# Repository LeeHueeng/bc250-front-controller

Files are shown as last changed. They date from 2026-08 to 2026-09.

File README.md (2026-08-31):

# BC250 Front Controller

**Turn your AMD BC-250 into a real PC** — smart power button, graceful shutdown, temperature-driven fan curve, OLED status display, and Home Assistant integration, all running standalone on a single ESP32-S3.

[🇰🇷 한국어 README](README.ko.md)






> ⚠️ **Status: work in progress.** Firmware boots and is verified on a bare board; full hardware validation (relay + sensors + fan on a live BC-250) is ongoing. Follow the repo for updates.

## Why?

The AMD BC-250 is a PS5-APU board that sells for roughly $100–150 these days — but it was born in a mining rack, so as a desktop it's missing everything:

- ❌ **No power button** and no ACPI — power on = PSU on
- ❌ **No graceful shutdown** — cutting power is the only "off"
- ❌ **No usable fan control** outside the original rack chassis
- ❌ **No status indication** whatsoever

This project fixes all of that with an ESP32-S3 sitting between your ATX PSU and the board — like the front panel the BC-250 never had.

## Features

- 🔌 **Real power button** — short press to power on / gracefully shut down, 5-second hold to force off
- 🛡️ **Fail-safe relay design** — the ATX `PS_ON` line is held through the relay's **NC contact**, so if the ESP32 crashes, reboots or updates, **your server stays up**
- 🧠 **Fully autonomous** — the graceful-shutdown sequence (HTTP request to the OS → wait → cut power), fan curve, OLED and button all run on the ESP32 itself. No Home Assistant, no cloud, no Wi-Fi required
- 🌡️ **Temperature-driven fan curve** — two DS18B20 probes (GPU heatsink + case), 25 kHz PWM, tach feedback with fan-failure detection
- 🖥️ **OLED status display** — power state, temperatures, fan RPM, network info on an SSD1306
- 🎛️ **On-device settings menu** — two extra buttons + the OLED give you a local menu: fan mode/preset, manual speed, display brightness, overheat threshold, shutdown timeout — all saved to flash, no phone or PC needed
- 🚨 **WS2812 status LED** — off / green (running) / yellow (shutting down) / red (fan failure, overheat)
- 🌐 **Built-in web dashboard** — control everything from a browser, straight from the ESP32
- 🏠 **Home Assistant auto-discovery** — appears natively via the ESPHome integration (optional MQTT)
- 📶 **Zero-config Wi-Fi provisioning** — first boot opens a `bc250-front-setup` AP with a captive portal; no credentials are baked into the firmware
- 🔄 **OTA updates** — flash over USB once, update over the air forever
- 📴 **Network-loss hardened** — never reboots on Wi-Fi/API loss; local control keeps working, the setup AP reopens automatically

## How it works

The BC-250 only uses the PCIe 8-pin — the ATX 24-pin connector is completely unused. So we steal three wires from it:

| ATX wire | Purpose |
|---|---|
| 🟣 Purple (pin 9, `5VSB`) | Always-on 5 V → powers the ESP32 + relay even when the PSU is "off" |
| 🟢 Green (pin 16, `PS_ON`) | Grounding this turns the PSU on — held via the relay **NC** contact |
| ⚪ Gray (pin 8, `PWR_OK`) | Tells the ESP32 whether the PSU is actually up (10k+10k divider) |

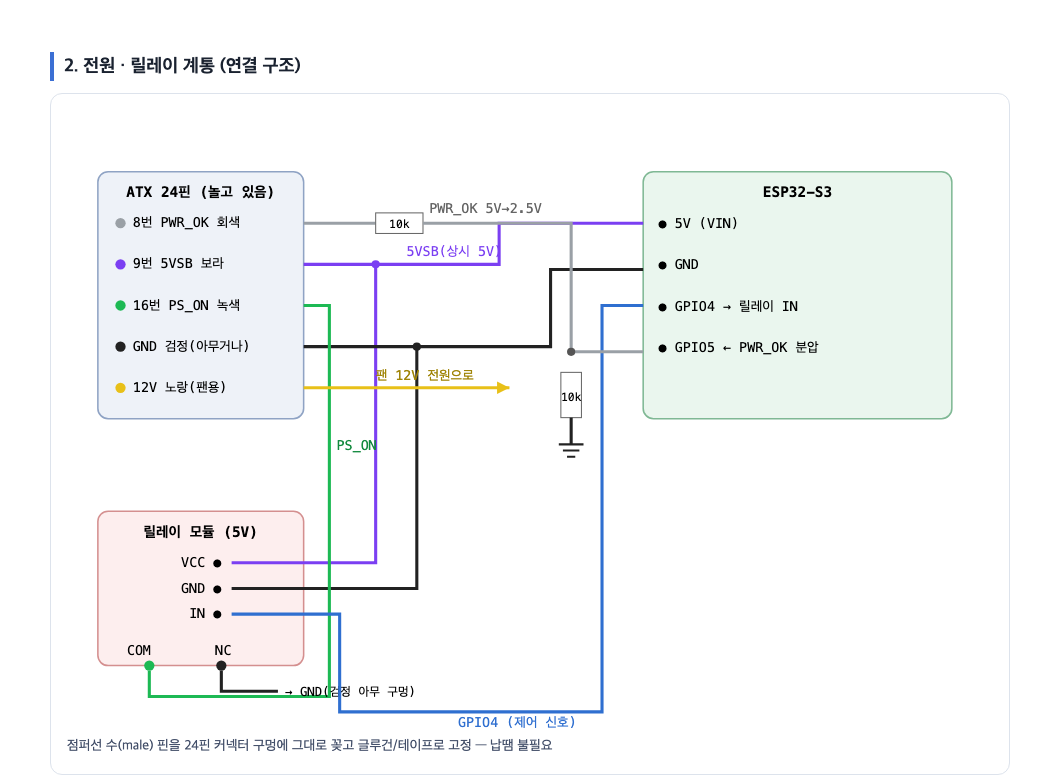
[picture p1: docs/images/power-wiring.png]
Power & relay wiring


Graceful shutdown, with the **ESP32 as the source of truth** (no home-automation dependency):

```
button / web / HA  →  ESP32  →  HTTP shutdown request to the OS
                              →  wait 60 s for the OS to halt
                              →  release PS_ON (power off)
```

## Build tiers — everything is optional except the relay

Missing parts don't break anything: an absent OLED, sensor, fan or button simply disables that one feature. Start minimal, add parts whenever you feel like it.

| Tier | Hardware | You get | Firmware |
|---|---|---|---|
| **Minimal** | ESP32 + relay + 3 jumper wires | Web/HA power on-off, graceful shutdown, status LED (onboard) | [`bc250-front-minimal.yaml`](bc250-front-minimal.yaml) |
| **+ Button** | + push button | Physical front-panel power button | same |
| **Full** | + OLED, 2× DS18B20, PWM fan, 2 menu buttons, PWR_OK divider | Fan curve, temperatures, display, on-device settings menu, PSU state | [`bc250-front.yaml`](bc250-front.yaml) |
| **Full + color LCD** | Full, but OLED → **ST7789V 2.4" 240×320 SPI** | All of the above + large color UI, status icons, backlight dimming | [`bc250-front-st7789.yaml`](bc250-front-st7789.yaml) |

## Hardware

| Part | Qty | ~Cost |
|---|---|---|
| ESP32-S3 dev board (2×22 pins) | 1 | $5 |
| 5 V 1-channel relay module (optocoupler) | 1 | $1 |
| SSD1306 0.96" OLED (I2C) | 1 | $2 |
| DS18B20 temperature sensor | 2 | $2 |
| Momentary push button (power + 2 menu) | 3 | $1 |
| Resistors: 2× 10 kΩ, 1× 4.7 kΩ | — | $0.1 |
| Dupont jumper wires | — | $1 |

**No soldering required** — male jumper pins fit straight into the unused ATX 24-pin connector holes.

## PCB — three options (optional)

| | [**DIY carrier board**](hardware/bc250-front-carrier/README.md) | [**Semi-assembled PCBA**](hardware/bc250-front-pcba/README.md) | [**DevKit mini**](hardware/bc250-front-mini/README.md) |
|---|---|---|---|
| How | bare board, hand-solder the parts, plug in an ESP32-S3-DevKitC-1 | JLCPCB Economic assembly — you solder only the ESP32-S3 WROOM module, the display socket and (optionally) the LED | **66×50 mm**, smallest — DevKit on sockets, parts under it, LCD wired to a pin header |
| Power switch | relay | MOSFET (silent) | MOSFET (silent) |
| Sensors | DS18B20 | DS18B20 **or** 10 kΩ NTC | DS18B20 |
| Cost (5 boards) | ≈ $2 boards + ≈ $8 parts each | JLCPCB ≈ $45 + ≈ $4 module each → ≈ $13 each | ≈ $2 boards (≈ $12 with SMD assembly) + a DevKit |
| Firmware | `relay_inverted: "false"` | defaults + `log_uart: USB_SERIAL_JTAG` | defaults (`relay_inverted: "true"`) |

All three take the PSU's ATX 24-pin plug directly and use the pin map above.

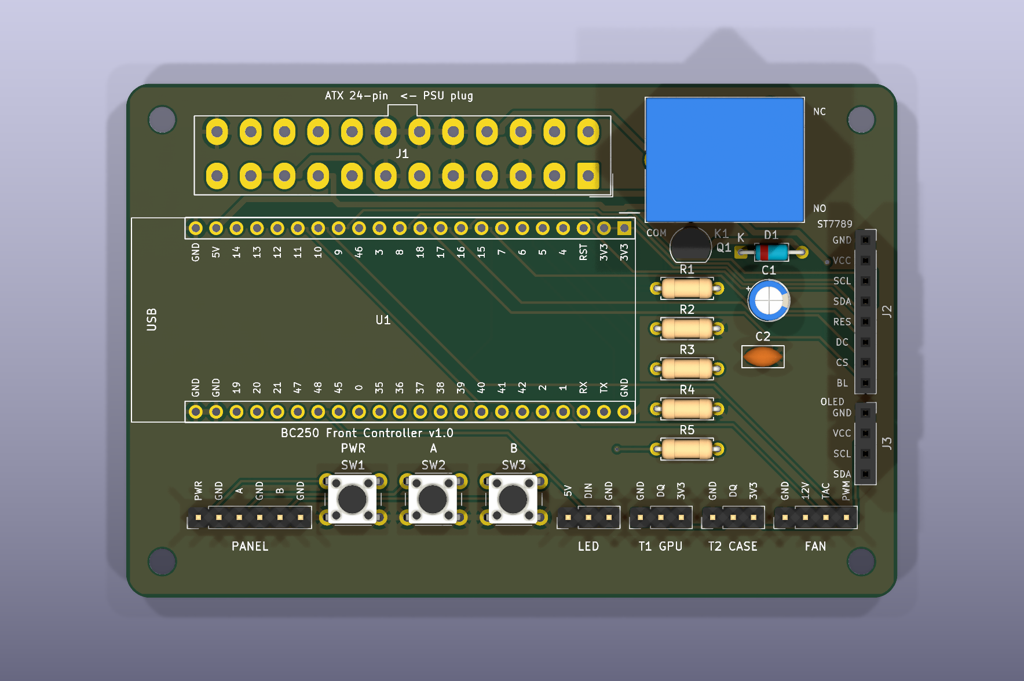
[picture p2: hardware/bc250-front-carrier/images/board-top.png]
carrier board

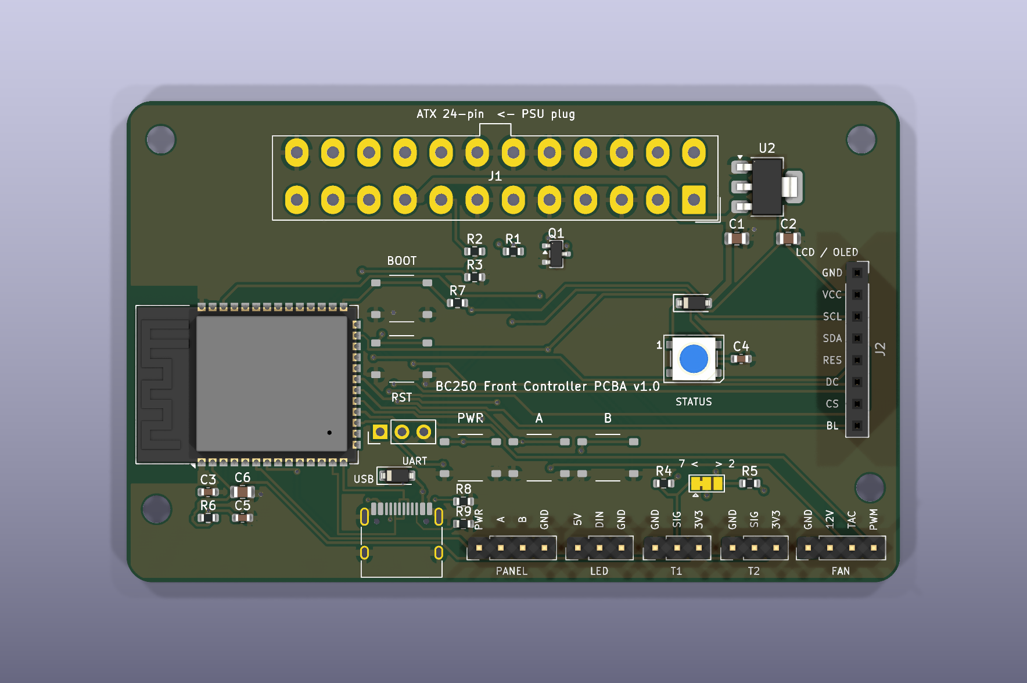
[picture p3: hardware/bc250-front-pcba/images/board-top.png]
PCBA

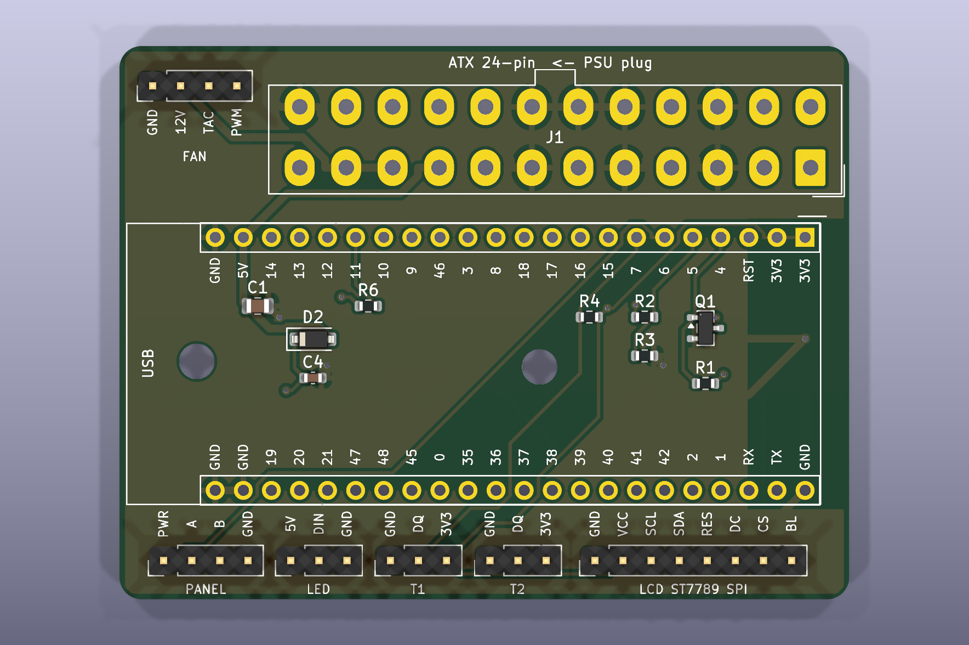
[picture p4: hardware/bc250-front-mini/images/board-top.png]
DevKit mini


## Wiring

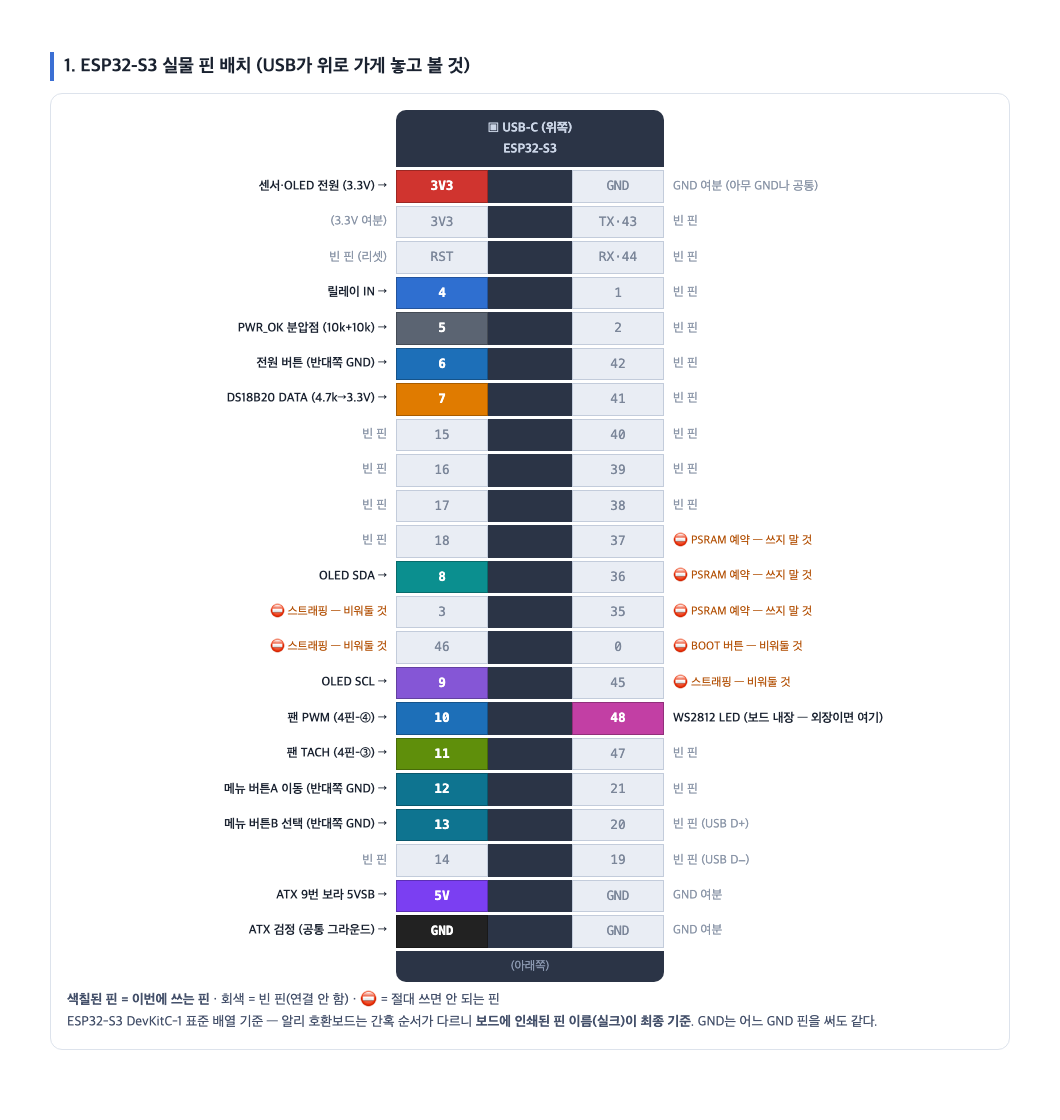
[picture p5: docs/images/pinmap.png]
ESP32-S3 pin map


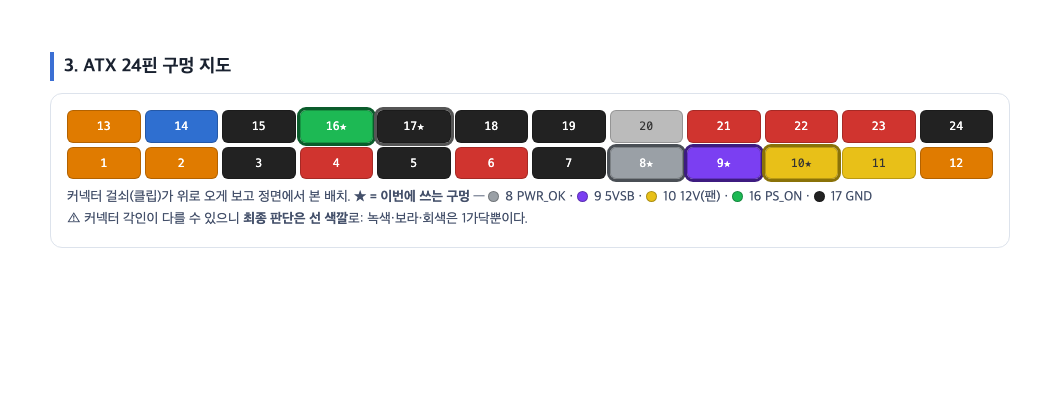
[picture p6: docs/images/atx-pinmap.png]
ATX 24-pin holes


| ESP32-S3 pin | Connects to |
|---|---|
| `5V` | ATX pin 9 — purple `5VSB` |
| `GND` | ATX black (common ground) |
| `3V3` | OLED VCC, DS18B20 VDD, pull-ups |
| `GPIO4` | Relay IN |
| `GPIO5` | ATX pin 8 — gray `PWR_OK` (**via 10k+10k divider**) |
| `GPIO6` | Power button (other leg → GND) |
| `GPIO7` | DS18B20 data ×2, 4.7 kΩ pull-up to 3.3 V |
| `GPIO8` / `GPIO9` | OLED SDA / SCL |
| `GPIO10` | Fan PWM (4-pin fan, pin 4) |
| `GPIO11` | Fan tach (4-pin fan, pin 3) |
| `GPIO12` / `GPIO13` | Menu buttons A (navigate) / B (select) — other leg → GND |
| `GPIO48` | WS2812 (onboard on most devkits) |

Relay contacts: **COM ↔ ATX pin 16 (green `PS_ON`)**, **NC ↔ GND**, NO unused.

Full interactive wiring guide (Korean): [`docs/wiring-guide.html`](docs/wiring-guide.html) (OLED) · [`docs/wiring-guide-st7789.html`](docs/wiring-guide-st7789.html) (ST7789V)

## Flashing

```bash
pip install esphome
esphome run bc250-front.yaml   # first time over USB, afterwards OTA
```

First boot: join the **`bc250-front-setup`** Wi-Fi AP from your phone → the captive portal opens → pick your network, enter the password. Done. Home Assistant will auto-discover the device within minutes.

> **Board note:** on CH343-based devkits the logger must use `hardware_uart: UART0` (already set in the YAML) — the default USB-JTAG console is not routed to the USB port on those boards.

## Roadmap

- [ ] OS-side shutdown agent (tiny systemd unit) + install script
- [ ] INA226 power monitoring (watts on the OLED!)
- [ ] Web-editable fan curve
- [ ] 3D-printable front-panel enclosure
- [ ] Buzzer alerts / event log

PRs and issues welcome — especially test reports from different BC-250 setups.

## Credits

- [mothenjoyer69/bc250-documentation](https://github.com/mothenjoyer69/bc250-documentation) — the definitive BC-250 hardware reference
- [elektricM/amd-bc250-docs](https://github.com/elektricM/amd-bc250-docs) — power & cooling documentation
- Built with [ESPHome](https://esphome.io)

## License

[MIT](LICENSE)

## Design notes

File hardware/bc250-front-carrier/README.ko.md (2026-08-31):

# BC250 Front Controller — 캐리어 PCB v1.0

ESP32-S3 DevKitC-1을 꽂는 캐리어 보드입니다. **PSU의 ATX 24핀 플러그가 보드에 그대로 꽂히므로** 점퍼선·글루건 없이 5VSB / PS_ON / PWR_OK / 12V / GND가 전부 자동으로 연결됩니다. 부품은 전부 관통형(THT)이라 인두기 하나면 조립할 수 있습니다.

[🇺🇸 English](README.md)

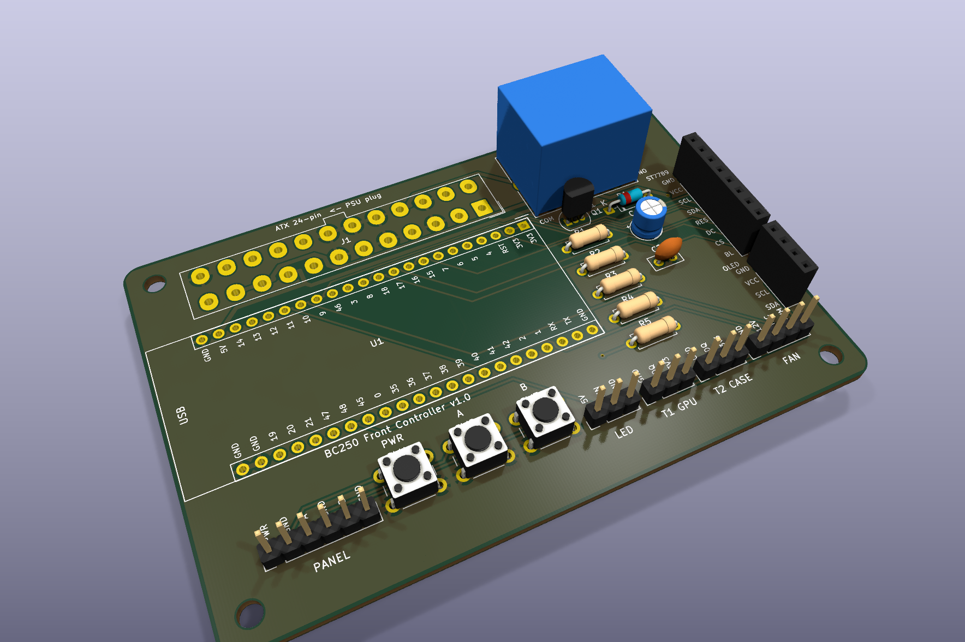
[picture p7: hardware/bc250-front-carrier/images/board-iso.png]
보드 렌더링


| | |
|---|---|
| 크기 | 96 × 64 mm, 2층, 1.6 mm, M3 홀 4개 (간격 87 × 55 mm) |
| MCU | ESP32-S3-DevKitC-1 (2×22핀) → 암소켓 2개에 꽂음 |
| 전원 | ATX 24핀 헤더 (Molex Mini-Fit Jr 5566-24A) 온보드 |
| 릴레이 | SRD-05VDC-SL-C + S8050 NPN 드라이버 온보드 — 기존과 같은 **NC fail-safe** 배선 |
| 디스플레이 | ST7789 2.4″ SPI 8핀 소켓 **과** SSD1306 OLED 4핀 소켓 (둘 중 하나만 꽂으면 됨) |
| 기타 커넥터 | 4핀 PWM 팬, DS18B20 ×2, 외장 WS2812, 전면패널 버튼 6핀 + 온보드 택트 3개 |
| 검증 | KiCad 10 ERC / DRC / 회로도-PCB 정합성 **모두 0건** (실물 검증은 아직 — 아래 첫 전원 절차 참고) |

## 파일

| 파일 | 용도 |
|---|---|
| [`gerbers/bc250-front-carrier-v1.0-gerbers.zip`](gerbers/bc250-front-carrier-v1.0-gerbers.zip) | **JLCPCB에 올리는 파일** (거버 + Excellon 드릴 + 잡파일) |
| `bc250-front-carrier.kicad_pro` / `.kicad_sch` / `.kicad_pcb` | KiCad 10 프로젝트 (풋프린트·심볼 라이브러리 동봉, 다른 PC에서도 바로 열림) |
| [`bc250-front-carrier-schematic.pdf`](bc250-front-carrier-schematic.pdf) | 회로도 |
| [`bom.csv`](bom.csv) | 부품표 |
| `bc250-front-carrier-pos.csv` | 부품 좌표 (조립 참고용) |
| `images/` | 앞·뒤·입체 렌더링, 레이아웃 SVG, 회로도 SVG |
| [`../tools/`](../tools/) | 보드 전체를 스크립트로 재생성 (`build.sh`) |

## JLCPCB 주문

1. [jlcpcb.com](https://jlcpcb.com) → **Order now** → *Add gerber file* → `gerbers/bc250-front-carrier-v1.0-gerbers.zip` 업로드
2. 96 × 64 mm, 2 layers로 자동 인식됩니다. 옵션은 **기본값 그대로** 두면 됩니다: FR-4, 1.6 mm, 1 oz, HASL, 수량 5장 (색은 취향, Remove Order Number는 No).
3. SMT 조립 서비스는 필요 없습니다 — 전부 직접 납땜합니다.
4. 5장에 보드값 약 $2 + 배송비 수준입니다.

## 부품표 (BOM)

| 참조 | 수량 | 부품 | 비고 |
|---|---|---|---|
| U1 | 1 | ESP32-S3-DevKitC-1 (N8R2 / N16R8 무관) | 수핀 헤더가 납땜된 것 |
| U1 소켓 | 2 | 1×22 암 핀소켓 2.54 mm | DevKit을 꽂은 채로 납땜하면 정렬이 쉬움 |
| J1 | 1 | ATX 24핀 보드용 커넥터 (Molex 5566-24A / 39-28-1243 호환, 4.2 mm 2×12 수직) | 국내: 디바이스마트·엘레파츠 "ATX 24핀 커넥터 보드용" |
| K1 | 1 | SRD-05VDC-SL-C 릴레이 (Songle / Sanyou SRD) | |
| Q1 | 1 | S8050 NPN (2N2222A·BC337도 가능) | TO-92, E-B-C |
| D1 | 1 | 1N4148 | 띠(캐소드)를 실크 **K** 쪽으로 |
| R1 | 1 | 1 kΩ | |
| R2, R3, R4 | 3 | 10 kΩ | |
| R5 | 1 | 4.7 kΩ | |
| C1 | 1 | 100 µF 16 V 전해 (5 mm) | 긴 다리(+)를 실크 **+** 쪽으로 |
| C2 | 1 | 100 nF 세라믹 | |
| J2 | 1 | 1×8 암 핀소켓 | ST7789 LCD 모듈이 그대로 꽂힘 |
| J3 | 1 | 1×4 암 핀소켓 | SSD1306 OLED 모듈이 그대로 꽂힘 |
| J4 | 1 | 1×4 수 핀헤더 | 4핀 팬 (진짜 팬 헤더도 꽂힘) |
| J5, J6, J7 | 3 | 1×3 수 핀헤더 | DS18B20 ×2, WS2812 |
| J8 | 1 | 1×6 수 핀헤더 | 전면 패널 버튼 (선택) |
| SW1–SW3 | 3 | 6×6 mm 택트 스위치 | 온보드 PWR / A / B |
| H1–H4 | 4 | M3 서포트 | 선택 |

## 조립 순서

1. **낮은 부품부터**: R1–R5 → D1 (띠를 `K` 쪽) → Q1 (평평한 면을 실크 모양과 맞춤) → C2 → C1 (`+` 확인)
2. **소켓·헤더**: J2·J3 암소켓, J4–J8 핀헤더, SW1–SW3, U1용 1×22 암소켓 ×2
3. **큰 부품**: K1 릴레이, J1 ATX 헤더 — 래치 홈이 있는 면이 보드 위쪽 가장자리(`ATX 24-pin ← PSU plug` 글자 쪽)를 향하게

## ⚠️ 첫 전원 인가 — ESP32를 꽂기 **전에**

ATX 헤더의 핀 번호는 KiCad 표준 Molex 5566-24A 풋프린트를 따랐지만, 실물로 검증된 보드는 아직 없습니다. 1분이면 확인됩니다.

1. DevKit **없이** PSU 24핀만 꽂고 PSU를 켭니다. 릴레이가 쉬는 상태(NC)라 **PSU가 바로 켜지는 게 정상**입니다 (ESP32가 죽어도 서버는 켜져 있다는 그 fail-safe).
2. 멀티미터로 확인 (보드 뒷면 실크에도 적혀 있음):
   - U1 소켓 윗줄 `5V` 핀 ↔ `GND` = **약 5 V**
   - `FAN` 헤더 `12V` 핀 ↔ `GND` = **12 V**
   - `5V` 자리에 0 V나 12 V가 나오면 J1 방향·납땜을 확인하고 **진행을 멈추세요.**
3. PSU를 끄고 DevKit 장착: USB 커넥터가 보드 **왼쪽 가장자리**(`USB` 실크), 안테나가 릴레이 쪽.

## 펌웨어

- yaml의 `substitutions:`에서 **`relay_inverted: "false"`** 로 바꿉니다 (이 보드는 NPN 직결 active-high; 시판 릴레이 모듈은 `"true"`).
- 외장 WS2812를 J7에 달면 `light:`의 `num_leds`를 조정하세요 (DevKit 내장 LED가 첫 번째 픽셀).
- 나머지 핀맵은 [배선 가이드](../../docs/wiring-guide.html)와 동일 — 보드가 그 배선을 그대로 구현한 것입니다.

## 설계 메모

- **릴레이**: COM=PS_ON, NC=GND. 평상시 PS_ON이 접지돼 PSU ON. GPIO4 HIGH → Q1 → 코일 여자 → NC 열림 → PSU OFF. R2(10 k) 풀다운으로 ESP32 부팅 중 코일이 뜨지 않게 하고, D1이 플라이백을 잡습니다. NO 접점은 비워둠.
- **PWR_OK**: 5 V → R3/R4 10 k/10 k → 2.5 V → GPIO5.
- **1-Wire**: GPIO7, R5 4.7 k → 3V3. DS18B20 두 개는 J5/J6에 병렬.
- **전원**: 5VSB → DevKit `5V` 핀(내장 LDO) + 릴레이 코일 (C1 100 µF). 3V3는 DevKit LDO 출력을 J2/J3/J5/J6/R5에 분배. 12V는 팬 전용(PSU 켜져 있을 때만).
- **레이아웃**: 신호 0.3 mm, 전원 0.7 mm, 양면 GND 폴, WROOM 안테나 아래 구리 제거(keepout). 배선은 Freerouting 자동 배선 후 DRC 통과.

## 재생성 (수정하고 싶을 때)

`.kicad_pcb`를 손으로 고치기보다 `../tools/gen_pcb.py`(배치·넷)와 `gen_sch.py`(회로도)를 고친 뒤 `../tools/build.sh`를 돌리세요. KiCad 10과 Java 21+가 필요하며, Freerouting은 스크립트가 자동으로 내려받습니다. 결과물은 이 폴더에 다시 설치됩니다.

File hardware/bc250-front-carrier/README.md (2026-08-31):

# BC250 Front Controller — carrier PCB v1.0

A carrier board for the ESP32-S3-DevKitC-1. **The PSU's ATX 24-pin plug goes straight onto the board**, so 5VSB / PS_ON / PWR_OK / 12V / GND are wired without jumper wires or hot glue. Every part is through-hole — a soldering iron is all you need.

[🇰🇷 한국어](README.ko.md)

board render

| | |
|---|---|
| Size | 96 × 64 mm, 2 layers, 1.6 mm, 4× M3 holes (87 × 55 mm spacing) |
| MCU | ESP32-S3-DevKitC-1 (2×22 pins) in two female sockets |
| Power | ATX 24-pin header (Molex Mini-Fit Jr 5566-24A) on board |
| Relay | SRD-05VDC-SL-C + S8050 NPN driver on board — same **NC fail-safe** wiring as before |
| Display | ST7789 2.4″ SPI 8-pin socket **and** SSD1306 OLED 4-pin socket (fit either) |
| Other connectors | 4-pin PWM fan, 2× DS18B20, external WS2812, 6-pin front-panel buttons + 3 on-board tact switches |
| Checks | KiCad 10 ERC / DRC / schematic-PCB parity: **0 violations** (not yet verified on a physical board — see first power-up below) |

## Files

| File | Purpose |
|---|---|
| [`gerbers/bc250-front-carrier-v1.0-gerbers.zip`](gerbers/bc250-front-carrier-v1.0-gerbers.zip) | **upload this to JLCPCB** (Gerbers + Excellon drill + job file) |
| `bc250-front-carrier.kicad_pro` / `.kicad_sch` / `.kicad_pcb` | KiCad 10 project, footprint and symbol libraries included (opens anywhere) |
| [`bc250-front-carrier-schematic.pdf`](bc250-front-carrier-schematic.pdf) | schematic |
| [`bom.csv`](bom.csv) | bill of materials |
| `bc250-front-carrier-pos.csv` | component positions (assembly reference) |
| `images/` | top / bottom / iso renders, layout SVG, schematic SVG |
| [`../tools/`](../tools/) | regenerates the whole board from scripts (`build.sh`) |

## Ordering at JLCPCB

1. [jlcpcb.com](https://jlcpcb.com) → **Order now** → *Add gerber file* → upload `gerbers/bc250-front-carrier-v1.0-gerbers.zip`
2. It is detected as 96 × 64 mm, 2 layers. Keep the **defaults**: FR-4, 1.6 mm, 1 oz, HASL, quantity 5 (colour is up to you, Remove Order Number: No).
3. No SMT assembly needed — everything is hand-soldered.
4. Expect roughly $2 for 5 boards plus shipping.

## BOM

| Ref | Qty | Part | Notes |
|---|---|---|---|
| U1 | 1 | ESP32-S3-DevKitC-1 (N8R2 / N16R8, either) | with male pin headers soldered |
| U1 sockets | 2 | 1×22 female pin socket 2.54 mm | solder with the DevKit plugged in for alignment |
| J1 | 1 | ATX 24-pin motherboard header (Molex 5566-24A / 39-28-1243 or compatible, 4.2 mm 2×12 vertical) | |
| K1 | 1 | SRD-05VDC-SL-C relay (Songle / Sanyou SRD) | |
| Q1 | 1 | S8050 NPN (2N2222A / BC337 also fine) | TO-92, E-B-C |
| D1 | 1 | 1N4148 | cathode band toward the **K** mark |
| R1 | 1 | 1 kΩ | |
| R2, R3, R4 | 3 | 10 kΩ | |
| R5 | 1 | 4.7 kΩ | |
| C1 | 1 | 100 µF 16 V electrolytic (5 mm) | long leg (+) to the **+** mark |
| C2 | 1 | 100 nF ceramic | |
| J2 | 1 | 1×8 female pin socket | ST7789 LCD module plugs in directly |
| J3 | 1 | 1×4 female pin socket | SSD1306 OLED module plugs in directly |
| J4 | 1 | 1×4 male pin header | 4-pin fan (a real fan header fits too) |
| J5, J6, J7 | 3 | 1×3 male pin header | 2× DS18B20, WS2812 |
| J8 | 1 | 1×6 male pin header | front-panel buttons (optional) |
| SW1–SW3 | 3 | 6×6 mm tactile switch | on-board PWR / A / B |
| H1–H4 | 4 | M3 standoffs | optional |

## Assembly order

1. **Low parts first**: R1–R5 → D1 (band to `K`) → Q1 (flat side as drawn on the silkscreen) → C2 → C1 (mind the `+`)
2. **Sockets and headers**: J2/J3 female sockets, J4–J8 pin headers, SW1–SW3, the two 1×22 sockets for U1
3. **Big parts**: K1 relay, J1 ATX header — the latch ramp faces the top board edge (the `ATX 24-pin ← PSU plug` text)

## ⚠️ First power-up — **before** fitting the ESP32

The ATX header pin numbering follows KiCad's standard Molex 5566-24A footprint, but no physical board has been verified yet. This takes a minute:

1. Plug in the PSU's 24-pin **without** the DevKit and switch the PSU on. The relay is idle (NC), so **the PSU turning on immediately is correct** — that is the fail-safe.
2. With a multimeter (also printed on the back silkscreen):
   - U1 socket, top row `5V` pin ↔ `GND` = **about 5 V**
   - `FAN` header `12V` pin ↔ `GND` = **12 V**
   - If the `5V` pin reads 0 V or 12 V, **stop** and check J1 orientation/solder joints.
3. Power the PSU off and fit the DevKit: USB connectors toward the **left board edge** (`USB` silkscreen), antenna toward the relay.

## Firmware

- Set **`relay_inverted: "false"`** under `substitutions:` in the yaml (this board drives the relay with an NPN, active-high; off-the-shelf relay modules are `"true"`).
- If you attach an external WS2812 to J7, adjust `num_leds` in `light:` (the DevKit's on-board LED is pixel 0).
- Everything else matches the [wiring guide](../../docs/wiring-guide.html) — the board simply implements that wiring.

## Design notes

- **Relay**: COM=PS_ON, NC=GND. PS_ON is grounded at rest, so the PSU is on. GPIO4 HIGH → Q1 → coil energised → NC opens → PSU off. R2 (10 k) keeps the coil off while the ESP32 boots; D1 clamps the flyback. NO is left open.
- **PWR_OK**: 5 V → R3/R4 10 k/10 k → 2.5 V → GPIO5.
- **1-Wire**: GPIO7 with R5 4.7 k to 3V3; both DS18B20s in parallel on J5/J6.
- **Power**: 5VSB → DevKit `5V` pin (on-board LDO) + relay coil (C1 100 µF). 3V3 from the DevKit LDO feeds J2/J3/J5/J6/R5. 12 V is fan-only (present only while the PSU is on).
- **Layout**: 0.3 mm signals, 0.7 mm power, GND pours on both sides, copper keep-out under the WROOM antenna. Autorouted with Freerouting, DRC clean.

## Regenerating

Rather than editing the `.kicad_pcb` by hand, change `../tools/gen_pcb.py` (placement, nets) or `gen_sch.py` (schematic) and run `../tools/build.sh`. It needs KiCad 10 and Java 21+; Freerouting is downloaded automatically. The outputs are installed back into this folder.

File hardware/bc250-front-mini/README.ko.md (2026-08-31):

# BC250 Front Controller — DevKit 미니 보드 v1.0 (66 × 50 mm)

ESP32-S3-DevKitC-1(2×22핀)을 소켓에 꽂고, **PSU의 ATX 24핀 플러그를 보드에 그대로 꽂는** 가장 작은 버전입니다. 케이블 가공 없음. 저항·MOSFET 같은 작은 부품은 전부 DevKit **밑**(소켓 두 줄 사이)에 들어가 있어서 보드가 DevKit보다 조금 큰 정도예요. 디스플레이는 1×8 핀헤더에 점퍼선으로 연결합니다.

[🇺🇸 English](README.md) · 다른 보드: [DIY 캐리어 (96×64)](../bc250-front-carrier/README.ko.md) · [반조립 PCBA (90×56)](../bc250-front-pcba/README.ko.md)

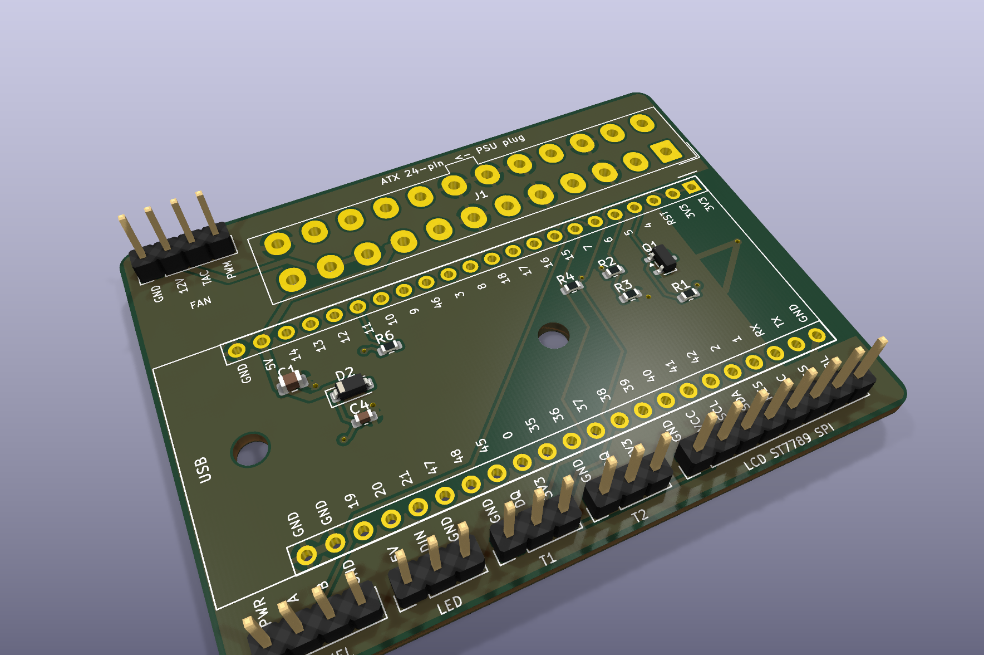
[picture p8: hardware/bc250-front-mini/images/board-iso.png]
보드 렌더링


| | |
|---|---|
| 크기 | **66 × 50 mm**, 2층, 1.6 mm, M3 홀 2개 (DevKit 밑) |
| MCU | ESP32-S3-DevKitC-1 (N8R2 / N16R8 아무거나) — 1×22 암소켓 2개에 꽂음. USB 끝이 보드 왼쪽 가장자리, 안테나는 오른쪽 |
| 전원 | ATX 24핀 헤더 온보드. 5VSB → DevKit `5V` 핀 (DevKit 자체 LDO가 3.3 V). 12 V는 팬 전용 |
| 전원 제어 | **MOSFET(AO3400A)** 이 PS_ON을 접지 — 무소음, fail-safe (ESP32가 죽어도 PSU ON) |
| 디스플레이 | 1×8 핀헤더 `GND VCC SCL SDA RES DC CS BL` → ST7789 모듈에 선으로 (15 cm 이내) |
| 센서 | T1·T2 3핀 헤더 — DS18B20 ×2 (GPIO7 1-Wire 공용, 4.7 k 풀업 내장) |
| 기타 | 4핀 PWM 팬(윗변), 외장 WS2812 헤더, 전면 버튼 4핀 헤더 (PWR A B GND) |
| 검증 | KiCad 10 ERC / DRC / 회로도-PCB 정합성 **0건**. **실물 검증은 아직 없음** — 아래 첫 전원 절차대로 |

v1.0 보드들에서 고친 점: PWR_OK 분압 10k/**20k** (2.5 V → 3.3 V, GPIO HIGH 규격 여유 확보) · 외장 LED 헤더 5V를 D2 뒤 ~4.3 V에서 공급 (3.3 V 데이터선을 WS2812B가 확실히 인식) · 팬 TACH에 10 k 직렬 (12 V 풀업 팬 보호).

## 파일

| 파일 | 용도 |
|---|---|
| [`gerbers/bc250-front-mini-v1.0-gerbers.zip`](gerbers/bc250-front-mini-v1.0-gerbers.zip) | JLCPCB 업로드용 거버 + 드릴 |
| [`jlcpcb-bom.csv`](jlcpcb-bom.csv) · [`jlcpcb-cpl.csv`](jlcpcb-cpl.csv) | (선택) JLCPCB Economic 조립 — **SMD 8개만** (전부 Basic 부품, 로딩비 0) |
| `jlcpcb-bom-full.csv` · `jlcpcb-cpl-full.csv` | ATX 헤더·1×3/1×4 핀헤더까지 조립시킬 때 (Extended 3종, +$9) |
| `bc250-front-mini.kicad_pro` / `.kicad_sch` / `.kicad_pcb` | KiCad 10 프로젝트 (라이브러리 동봉) — 열어서 직접 고쳐도 됨 |
| [`bc250-front-mini-schematic.pdf`](bc250-front-mini-schematic.pdf) | 회로도 |
| `images/` | 렌더링·레이아웃·회로도 SVG |
| [`../tools/`](../tools/) | `build.sh mini` 로 전체 재생성 (`designs/mini.py` 편집) |

## 부품 목록

| Ref | 수량 | 부품 | 비고 |
|---|---|---|---|
| U1 | 1 | **ESP32-S3-DevKitC-1** (핀헤더 납땜된 것) | 알리 ₩6,000~ |
| U1 소켓 | 2 | 1×22 암 핀소켓 2.54 mm | 1×40 소켓 잘라서 써도 됨 |
| J1 | 1 | ATX 24핀 보드용 헤더 **Molex 5566-24A** (4.2 mm 2×12 수직) | 검색어: `5566-24A` / "ATX 24핀 커넥터 보드용" — LCSC C114088 |
| Q1 | 1 | AO3400A N-MOSFET SOT-23 | C20917 |
| R1 R2 R6 | 3 | 10 kΩ 0603 | C25804 |
| R3 | 1 | **20 kΩ** 0603 | C4184 |
| R4 | 1 | 4.7 kΩ 0603 | C23162 |
| D2 | 1 | 1N4148W SOD-123 | C81598 |
| C1 | 1 | 10 µF 0805 | C15850 |
| C4 | 1 | 100 nF 0603 | C14663 |
| J2 | 1 | 1×8 수 핀헤더 | LCD |
| J4 J8 | 2 | 1×4 수 핀헤더 | FAN · PANEL — C124378 |
| J5 J6 J7 | 3 | 1×3 수 핀헤더 | T1 · T2 · LED — C49257 |

SMD 8개는 0603/0805/SOT-23라 인두로도 되지만, JLCPCB에 **Economic 조립**(`jlcpcb-bom.csv` + `jlcpcb-cpl.csv`)을 시키면 5장에 약 **$12** (PCB $2 + 셋업 $8 + 부품 $1.5)로 끝납니다. 나머지(소켓·헤더·ATX)는 관통형이라 직접 납땜.

## 조립 순서

1. **SMD** (JLC 조립이면 건너뜀): DevKit 밑 자리의 Q1·D2·R1~R6·C1·C4. 실크 `1` 표시 = D2 캐소드(K).
2. **핀헤더** (J2·J4~J8) → 짧은 것부터.
3. **DevKit 소켓**: 소켓 2개를 DevKit에 먼저 꽂고 통째로 보드에 끼운 뒤 납땜하면 정렬이 맞습니다. DevKit의 **USB가 보드 왼쪽 가장자리(실크 `USB`)**, 안테나가 오른쪽.
4. **ATX 헤더** 마지막 (열용량이 커서 인두 온도 높게). 걸쇠 홈 면이 보드 위쪽 가장자리(`ATX 24-pin <- PSU plug` 글자 쪽).

## ⚠️ 첫 전원 인가 — DevKit을 꽂기 **전에**

1. 소켓만 있는 보드에 PSU 24핀만 꽂고 PSU AC on. **PSU가 바로 켜지는 게 정상** (fail-safe).
2. 멀티미터: 소켓 윗줄 `5V` ↔ `GND` = **약 5 V** · `FAN` 헤더 `12V` = 12 V · `T1` `3V3`는 아직 0 V (DevKit이 없으니 정상).
3. `5V` 자리에 0 V나 12 V가 나오면 J1 방향·납땜 확인하고 **진행 중지**. 이상 없으면 PSU 끄고 DevKit 장착.
4. USB로 `esphome run bc250-front-st7789.yaml` → 대시보드에서 "서버 전원" 끄기 → PSU 꺼지면 OK.

## 펌웨어 — 기존 yaml에 한 줄

```yaml
substitutions:
  relay_inverted: "true"   # 릴레이 모듈과 같은 극성 (GPIO4 LOW = 전원 차단)
  # log_uart 는 기본값 UART0 그대로 (DevKit의 USB-시리얼)
```
GPIO는 점퍼선 배선과 100 % 동일 — `bc250-front.yaml` / `bc250-front-st7789.yaml` / `bc250-front-minimal.yaml` 전부 그대로.

## 커넥터

| 라벨 | 핀 (실크 순서) | 비고 |
|---|---|---|
| `LCD` (J2) | GND VCC SCL SDA RES DC CS BL | ST7789 모듈 라벨과 1:1 — 같은 이름끼리 선으로 |
| `FAN` (J4, 윗변) | GND 12V TAC PWM | 4핀 PWM 팬 |
| `T1` `T2` (J5 J6) | GND DQ 3V3 | DS18B20 (둘 다 GPIO7) |
| `LED` (J7) | 5V DIN GND | 외장 WS2812 (5V 자리는 실제 ~4.3 V — 의도된 것) |
| `PANEL` (J8) | PWR A B GND | 전면 버튼 3개, 반대쪽 다리는 전부 GND |

LCD 선은 **15 cm 이내**로. 화면이 깨지면 yaml `spi:` 의 `data_rate`를 20 MHz로 낮추세요.

## 설계 메모
- **PS_ON**: Q1 드레인 → PS_ON, 소스 → GND, 게이트 ← GPIO4 + R1 10 k 풀업(3V3). ESP32 리셋/다운로드/사망 시 풀업이 게이트를 HIGH → PSU ON. 펌웨어가 GPIO4 LOW → PSU OFF.
- **PWR_OK**: 5 V → R2 10 k / R3 20 k → 3.3 V → GPIO5. (구 보드의 10k/10k = 2.5 V는 ESP32-S3 VIH 최소 2.475 V에 너무 가까움.)
- **LED**: 5 V → D2 → ~4.3 V → J7. WS2812B는 데이터 HIGH ≥ 0.7×VDD 필요 → 4.3 V면 3.3 V 데이터 OK. 1N4148W 150 mA라 LED 2개까지.
- **FAN TACH**: R6 10 k 직렬 → 일부 팬의 12 V 내부 풀업에서 GPIO11 보호. PWM은 3.3 V 직결.
- **안테나**: DevKit 오른쪽 끝(안테나) 아래는 양면 구리 제거 구역.
- **홀**: M3 ×2, DevKit 밑에 있음 — 소켓 높이(8.5 mm) 덕분에 너트/스탠드오프가 들어감.
- **ATX 헤더 방향**: KiCad 표준 Molex 5566-24A 풋프린트 기준(캐리어/PCBA와 동일). 실물 검증 전이므로 위 첫 전원 절차 필수.

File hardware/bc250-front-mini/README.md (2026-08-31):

# BC250 Front Controller — DevKit mini board v1.0 (66 × 50 mm)

The smallest variant: an **ESP32-S3-DevKitC-1 on two 1×22 sockets, the PSU's ATX 24-pin plug straight on the board**, every small part (MOSFET, resistors, diode, caps) tucked *under* the DevKit between the socket rows. The display is wired to a 1×8 pin header. No cable surgery anywhere.

[🇰🇷 한국어](README.ko.md) · other boards: [DIY carrier (96×64)](../bc250-front-carrier/README.md) · [semi-assembled PCBA (90×56)](../bc250-front-pcba/README.md)

render

| | |
|---|---|
| Size | **66 × 50 mm**, 2 layers, 1.6 mm, 2× M3 (under the DevKit) |
| MCU | ESP32-S3-DevKitC-1 (any N8R2 / N16R8) on 2× 1×22 female headers — USB end at the left board edge, antenna right |
| Power | ATX 24-pin header on board. 5VSB → DevKit `5V` pin (its own LDO makes 3V3). 12 V only feeds the fan |
| Power switch | **MOSFET (AO3400A)** grounds PS_ON — silent, fail-safe (PSU stays ON when the ESP32 is dead) |
| Display | 1×8 header `GND VCC SCL SDA RES DC CS BL` → ST7789 module via wires (≤ 15 cm) |
| Sensors | T1 · T2 3-pin headers — 2× DS18B20 on the GPIO7 1-wire bus (4.7 k pull-up on board) |
| Other | 4-pin PWM fan (top edge), external WS2812 header, front-panel 4-pin header (PWR A B GND) |
| Checks | KiCad 10 ERC / DRC / schematic parity **0 issues**. **Not yet verified on a physical board** |

Fixes vs the v1.0 boards: PWR_OK divider 10k/**20k** (3.3 V instead of a marginal 2.5 V) · external LED header fed from ~4.3 V (D2) so 3.3 V data is a valid HIGH · 10 k series resistor on FAN TACH.

## Files

| File | Use |
|---|---|
| [`gerbers/bc250-front-mini-v1.0-gerbers.zip`](gerbers/bc250-front-mini-v1.0-gerbers.zip) | Gerbers + drill for JLCPCB |
| [`jlcpcb-bom.csv`](jlcpcb-bom.csv) · [`jlcpcb-cpl.csv`](jlcpcb-cpl.csv) | optional JLCPCB Economic assembly — the **8 SMD parts only** (all Basic, no loading fee) |
| `jlcpcb-bom-full.csv` · `jlcpcb-cpl-full.csv` | also assembles the ATX header and 1×3 / 1×4 headers (3 Extended parts, +$9) |
| `bc250-front-mini.kicad_pro` / `.kicad_sch` / `.kicad_pcb` | KiCad 10 project (self-contained libraries) — edit freely |
| [`bc250-front-mini-schematic.pdf`](bc250-front-mini-schematic.pdf) | schematic |
| [`../tools/`](../tools/) | `build.sh mini` regenerates everything from `designs/mini.py` |

## BOM

| Ref | Qty | Part | LCSC |
|---|---|---|---|
| U1 | 1 | ESP32-S3-DevKitC-1 with pin headers | — |
| U1 sockets | 2 | 1×22 female header 2.54 mm | — |
| J1 | 1 | ATX 24-pin header Molex 5566-24A (4.2 mm 2×12 vertical) | C114088 |
| Q1 | 1 | AO3400A SOT-23 | C20917 |
| R1 R2 R6 | 3 | 10 kΩ 0603 | C25804 |
| R3 | 1 | 20 kΩ 0603 | C4184 |
| R4 | 1 | 4.7 kΩ 0603 | C23162 |
| D2 | 1 | 1N4148W SOD-123 | C81598 |
| C1 | 1 | 10 µF 0805 | C15850 |
| C4 | 1 | 100 nF 0603 | C14663 |
| J2 | 1 | 1×8 male pin header | — |
| J4 J8 | 2 | 1×4 male pin header | C124378 |
| J5 J6 J7 | 3 | 1×3 male pin header | C49257 |

## Build order
1. SMD parts under the DevKit (skip if JLCPCB assembles them). Silk `1` on D2 = cathode.
2. Pin headers J2, J4–J8.
3. DevKit sockets: plug the two sockets onto the DevKit first, insert the whole stack, solder. **USB end at the left edge** (silk `USB`), antenna right.
4. ATX header last (large thermal mass). Latch side toward the top edge.

## ⚠️ First power-up — before fitting the DevKit
1. Only the PSU plug on the board → PSU AC on. **The PSU turns on immediately — that is the fail-safe working.**
2. Multimeter: socket `5V` ↔ `GND` ≈ 5 V · `FAN` `12V` = 12 V.
3. 0 V or 12 V on `5V` → check J1 orientation / solder joints and **stop**. Otherwise PSU off, fit the DevKit.
4. USB → `esphome run bc250-front-st7789.yaml` → switch "server power" off in the dashboard → PSU turns off = OK.

## Firmware
```yaml
substitutions:
  relay_inverted: "true"   # same polarity as the relay module (GPIO4 LOW = power cut)
```
GPIOs are identical to the jumper-wire build — all `bc250-front*.yaml` files work unchanged (`log_uart` stays `UART0`).

## Connectors
| Label | Pins | Notes |
|---|---|---|
| `LCD` (J2) | GND VCC SCL SDA RES DC CS BL | same names as on the ST7789 module — wire like to like |
| `FAN` (J4, top edge) | GND 12V TAC PWM | 4-pin PWM fan |
| `T1` `T2` (J5 J6) | GND DQ 3V3 | DS18B20 (both on GPIO7) |
| `LED` (J7) | 5V DIN GND | external WS2812 (the 5V pin is really ~4.3 V — intended) |
| `PANEL` (J8) | PWR A B GND | three buttons, other legs to GND |

## Design notes
- **PS_ON**: Q1 drain → PS_ON, source → GND, gate ← GPIO4 + R1 10 k pull-up to 3V3. Reset / download / dead ESP32 → gate HIGH → PSU on. Firmware drives GPIO4 LOW → PSU off.
- **PWR_OK**: 5 V → R2 10 k / R3 20 k → 3.3 V → GPIO5.
- **LED**: 5 V → D2 → ~4.3 V → J7 so the 3.3 V data line satisfies the WS2812B 0.7×VDD input threshold. 1N4148W = 150 mA → up to 2 LEDs.
- **FAN TACH**: R6 10 k in series protects GPIO11 from fans with an internal 12 V pull-up.
- **Antenna**: copper-free zone under the DevKit's antenna end. **Holes**: M3 ×2 under the DevKit (8.5 mm socket clearance).
- **ATX header orientation** follows the KiCad Molex 5566-24A footprint (same as the other two boards) — unverified on hardware, hence the power-up check above.

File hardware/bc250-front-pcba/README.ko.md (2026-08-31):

# BC250 Front Controller — 반조립 PCBA v1.0 (JLCPCB Economic 조립)

JLCPCB가 저항·콘덴서·MOSFET·LDO·USB-C·ATX 헤더·핀헤더·버튼을 전부 실장해서 보내고, **ESP32-S3 모듈 · 디스플레이 소켓 · (선택) 상태 LED 세 가지만 직접 납땜**하는 버전입니다. 이 세 부품을 빼면 JLCPCB의 저렴한 **Economic 조립**이 가능해져(ESP32 모듈과 5050 LED는 "Standard 전용" 부품) 고정비가 약 $22 줄어듭니다.

[🇺🇸 English](README.md) · 전부 직접 납땜하는 DevKit 버전은 [`../bc250-front-carrier/`](../bc250-front-carrier/README.ko.md)

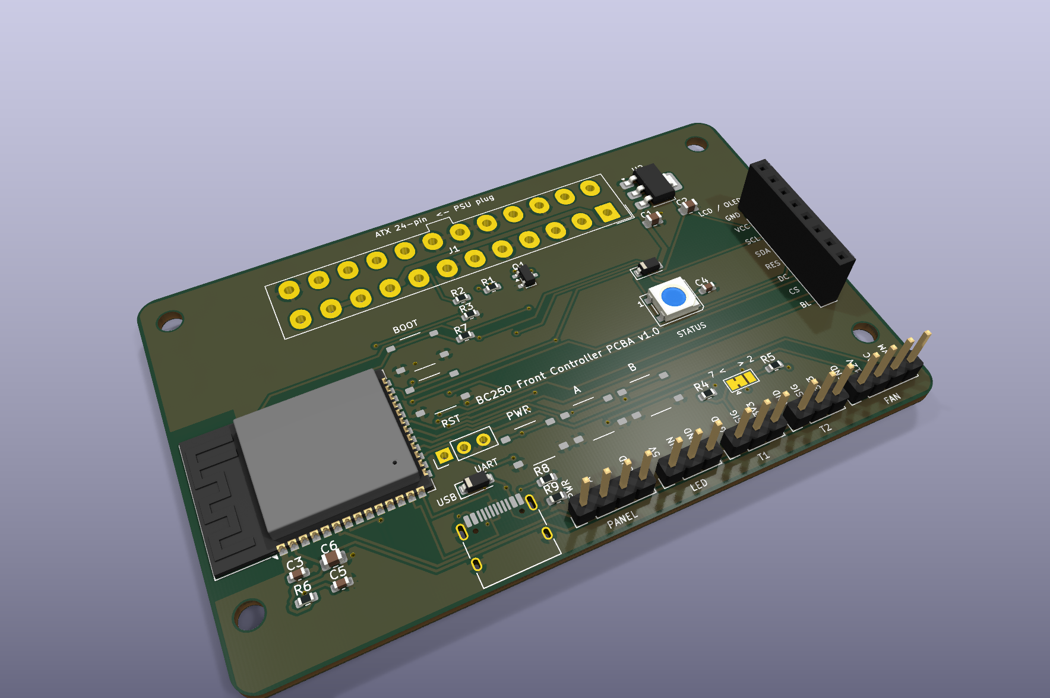
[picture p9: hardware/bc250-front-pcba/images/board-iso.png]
보드 렌더링


| | |
|---|---|
| 크기 | 90 × 56 mm, 2층, 1.6 mm, M3 홀 4개 |
| MCU | **ESP32-S3-WROOM-1** 모듈 (직접 납땜; N4/N8/N8R2/N16R8 아무거나) + USB-C 네이티브 USB (USB-시리얼 칩 없음) |
| 전원 제어 | **MOSFET(AO3400A)** 이 PS_ON을 접지 — 릴레이 없음, 무소음, fail-safe 동일 (ESP32가 죽어도 PSU ON) |
| 전원 | ATX 헤더의 5VSB → AMS1117-3.3. 12V는 팬 전용 |
| 디스플레이 | 1×8 소켓 자리(직접 납땜)에 **ST7789(8핀) 또는 SSD1306 OLED(앞 4핀)** |
| 센서 | T1·T2 3핀 헤더 — DS18B20 **또는 10 kΩ NTC** (4.7 k 풀업 내장) |
| 기타 | 4핀 PWM 팬, WS2812B 상태 LED 자리(선택) + 외장 LED 헤더, 전면패널 4핀, PWR/A/B/BOOT/RESET 버튼 |
| 검증 | KiCad 10 ERC / DRC / 회로도-PCB 정합성 0건. **실물 검증은 아직 없음** — 첫 보드는 아래 점검 절차대로 |

## 파일

| 파일 | 용도 |
|---|---|
| [`gerbers/bc250-front-pcba-v1.0-gerbers.zip`](gerbers/bc250-front-pcba-v1.0-gerbers.zip) | JLCPCB 1단계: 거버 업로드 |
| [`jlcpcb-bom.csv`](jlcpcb-bom.csv) · [`jlcpcb-cpl.csv`](jlcpcb-cpl.csv) | JLCPCB 2단계: **기본(반조립)** BOM/CPL — U1·J2·LED1 제외 |
| `jlcpcb-bom-full.csv` · `jlcpcb-cpl-full.csv` | 전부 조립시키고 싶을 때 (Standard 조립 필요, 약 +$30) |
| `bc250-front-pcba.kicad_pro` / `.kicad_sch` / `.kicad_pcb` | KiCad 10 프로젝트 (라이브러리 동봉) |
| [`bc250-front-pcba-schematic.pdf`](bc250-front-pcba-schematic.pdf) | 회로도 |
| `images/` | 렌더링·레이아웃·회로도 SVG |
| [`../tools/`](../tools/) | `build.sh pcba` 로 전체 재생성 |

## JLCPCB 주문

1. [jlcpcb.com](https://jlcpcb.com) → **Order now** → `gerbers/bc250-front-pcba-v1.0-gerbers.zip` 업로드. PCB 옵션 기본값(FR-4, 1.6 mm, HASL). 수량 **최소 2장**, 5장 추천.
2. **PCB Assembly** ON → **Economic** · Top side · 조립 수량 = 보드 수량.
3. **Add BOM / CPL**: `jlcpcb-bom.csv` + `jlcpcb-cpl.csv` 업로드 → 22줄 전부 LCSC 번호로 자동 매칭되는지 확인. (Extended 부품은 ATX 헤더·USB-C·핀헤더 2종 = 4종, 나머지는 Basic)
4. **배치 미리보기** 확인: `J3` USB-C 입구가 보드 **아래 가장자리**, `Q1`(SOT-23)·`U2`(SOT-223)·`D1`/`D2` 방향이 실크와 일치. 어긋나면 미리보기에서 회전.
5. 결제 → 1~2주 후 도착.

### 비용 (5장 기준 추정, 2026-08 — JLCPCB 견적이 정확)

| 항목 | 금액 |
|---|---|
| PCB 5장 | ~$2 |
| Economic 조립 셋업 + 스텐실 | ~$8 + ~$1.5 |
| Extended 부품 로딩비 4종 | ~$12 |
| 실장 부품값 (장당 ≈ $2.6) | ~$13 |
| 조립비 SMT+THT (장당 ≈ $1.7) | ~$8.5 |
| **JLCPCB 합계 (5장)** | **≈ $45 + 배송 → 장당 ≈ $9** |
| **JLCPCB 합계 (2장)** | **≈ $32 + 배송** |
| + 직접 구매: ESP32-S3-WROOM-1 (알리/LCSC ~$3.5), 1×8 암소켓 (₩100), WS2812B 5050 (선택, ₩100) | 장당 ≈ $4 |

→ **장당 ≈ $13 + 디스플레이·센서·팬**. 전부 조립(Standard, `*-full.csv`)은 5장 ≈ $100.

### 이 버전의 원가 절감 내역

| 항목 | 전 | 후 |
|---|---|---|
| 조립 등급 | Standard ($25 + $7) | **Economic ($8 + $1.5)** — 모듈·LED만 직접 납땜 |
| 릴레이 + 드라이버 (SRD-05V, S8050, 1N4148, 100 µF) | ~$0.7 + THT 4개 | **AO3400A MOSFET 1개** ($0.09), 무소음 |
| DevKit ($4.5~5) | 소켓 2개 + 별도 구매 | **WROOM 모듈** ($3.5) + USB-C ($0.31) + LDO ($0.12) |
| 관통형 R/C | THT 7개 | **0603/0805 Basic 부품** (로딩비 $0) |
| OLED 소켓 + LCD 소켓 | 2개 | **1×8 소켓 하나** (OLED는 앞 4핀) |
| 전면패널 헤더 1×6 | Extended 1종 | **1×4** → FAN과 같은 부품 |
| 택트 스위치 | 6×6 THT | **TS-1187A SMD (Basic, $0.02)** ×5 |
| 온도 센서 | DS18B20 ×2 (~₩3,000/개) | **10 kΩ NTC 겸용** (~₩300/개) |
| ESP32-S3 | N16R8 | **N4/N8도 가능** (PSRAM 불필요) — 직접 사니 아무거나 |

ESP32-C3 다운그레이드는 넣지 않았습니다: 풀옵션에 GPIO 15개가 필요한데 C3는 13개, 절감액도 $1 미만. OLED/최소 구성 전용이면 가능합니다.

## 직접 납땜할 부품 3개

| 부품 | 어떻게 |
|---|---|
| **U1 ESP32-S3-WROOM-1** | 가장자리 캐스텔레이션 패드(1.27 mm 피치)를 인두로: 플럭스 → 모서리 두 곳 가납땜으로 정렬 → 나머지 패드. 가운데 큰 GND 패드는 **안 해도 됨**(GND는 가장자리 1·40번 핀으로 연결됨; 열풍기 있으면 해도 좋음). 안테나가 보드 왼쪽 가장자리(실크 안테나 그림) 쪽. |
| **J2 디스플레이** | 1×8 2.54 mm 암소켓을 납땜해 모듈을 꽂거나(권장), 모듈의 핀헤더를 보드에 직접 납땜. OLED는 GND·VCC·SCL·SDA 4핀 자리에. |
| **LED1 WS2812B** (선택) | 5050 4패드, 1번 핀 표시(실크 `1`)가 왼쪽 위. 안 달아도 외장 LED 헤더 `LED`(J7)가 같은 데이터선을 받으므로 기능은 동일. |

## 사용법

### 펌웨어 (기존 yaml 그대로, substitutions 두 줄만)
```yaml
substitutions:
  relay_inverted: "true"        # 릴레이 모듈과 같은 극성 (GPIO4 LOW = 전원 차단)
  log_uart: USB_SERIAL_JTAG     # 네이티브 USB로 로그
```
GPIO 번호는 DevKit 배선과 100% 동일 — `bc250-front.yaml` / `bc250-front-st7789.yaml` / `bc250-front-minimal.yaml` 모두 그대로. 첫 굽기는 USB-C(`esphome run`), 이후 OTA. 자동 다운로드가 안 잡히면 **BOOT** 누른 채 **RESET**. 외장 LED만 쓰면 `num_leds: 1` 그대로(LED1과 같은 픽셀 0을 보여줌).

### 온도 센서 — DS18B20 또는 NTC
- **DS18B20 두 개(기본)**: T1·T2 모두 GPIO7 1-Wire 버스. yaml 그대로.
- **NTC 두 개 (가장 저렴)**: 뒷면 솔더 점퍼 **JP1** 을 `1-2`(기본, 실크 7)에서 `2-3`(실크 2)으로 옮기면 T2가 GPIO2 전용 채널. NTC를 SIG–GND 사이에 연결하고 yaml의 `one_wire`/`dallas_temp` 대신:
  ```yaml
  sensor:
    - platform: adc
      pin: GPIO7            # T1 (T2는 GPIO2)
      id: t1_adc
      attenuation: 12db
      update_interval: 5s
    - platform: resistance
      sensor: t1_adc
      configuration: DOWNSTREAM   # NTC가 GND 쪽, 4.7k 풀업이 3V3 쪽
      resistor: 4.7kOhm
      reference_voltage: 3.3V
      id: t1_res
    - platform: ntc
      sensor: t1_res
      id: gpu_temp
      name: "GPU 온도"
      calibration:
        b_constant: 3950
        reference_temperature: 25°C
        reference_resistance: 10kOhm
  ```

### 커넥터
| 라벨 | 핀 | 비고 |
|---|---|---|
| `LCD / OLED` (J2) | GND VCC SCL SDA RES DC CS BL | ST7789 8핀 / OLED는 앞 4핀 |
| `FAN` (J4) | GND 12V TACH PWM | 4핀 PWM 팬 |
| `T1` `T2` (J5 J6) | GND SIG 3V3 | DS18B20(GND DQ VDD) 또는 NTC(GND–SIG) |
| `LED` (J7) | 5V DIN GND | 외장 WS2812 (LED1과 병렬, 픽셀 0) |
| `PANEL` (J8) | PWR A B GND | 전면 버튼 (온보드 버튼과 병렬) |
| `UART` (J9, 미실장) | TX RX GND | 디버그용 |

### ⚠️ 첫 전원 인가
1. 모듈·디스플레이·센서를 달기 **전에** PSU 24핀만 꽂고 PSU on → **PSU가 바로 켜지는 게 정상**(fail-safe).
2. `T1` `3V3`–`GND` = 3.3 V, `FAN` `12V` = 12 V, `LED` `5V` = 5 V 확인 (뒷면 실크에도 표기). 이상 없으면 PSU 끄고 모듈 납땜.
3. USB-C 연결 → `esphome run` → 웹 대시보드에서 "서버 전원" 끄기 → PSU 꺼지면 OK.

## 설계 메모
- **PS_ON**: Q1 드레인 → PS_ON, 소스 → GND, 게이트 ← GPIO4 + R1 10 k 풀업(3V3). ESP32가 리셋/다운로드/사망이면 풀업이 게이트를 HIGH로 → PSU ON. 펌웨어가 GPIO4를 LOW로 → PSU OFF. 릴레이 모듈(active-low)과 같은 논리라 `relay_inverted: "true"`.
- **USB**: VBUS → D1(B5819W) → 5V 레일: USB만 꽂아도 동작, PSU 5VSB는 USB로 역류하지 않음. D+/D−는 커넥터 양면 패드를 고정 배선으로 브리지.
- **LED**: WS2812B VDD를 D2(1N4148W)로 ~4.3 V로 낮춰 3.3 V 데이터를 인식. J7은 같은 데이터선(병렬).
- **BOOT/RESET**: R7/R6 10 k 풀업, C5 1 µF EN 지연.
- **안테나**: 모듈 안테나가 왼쪽 가장자리로 향하고 그 아래 양면 구리 제거.
- **CPL 회전값**: KiCad 풋프린트와 JLCPCB(EasyEDA) 풋프린트의 1번 핀 위치를 실제 비교해 보정 (SOT-23·SOT-223 +180°, 나머지 0°).

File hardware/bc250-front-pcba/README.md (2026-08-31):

# BC250 Front Controller — semi-assembled PCBA v1.0 (JLCPCB Economic assembly)

JLCPCB places every resistor, capacitor, the MOSFET, LDO, USB-C, ATX header, pin headers and buttons; **you hand-solder three parts: the ESP32-S3 module, the display socket and (optionally) the status LED.** Leaving those out lets JLCPCB use the cheap **Economic** assembly (the ESP32 module and 5050 LEDs are "Standard only" parts), which cuts the fixed fees by about $22.

[🇰🇷 한국어](README.ko.md) · fully hand-soldered DevKit version: [`../bc250-front-carrier/`](../bc250-front-carrier/README.md)

board render

| | |
|---|---|
| Size | 90 × 56 mm, 2 layers, 1.6 mm, 4× M3 |
| MCU | **ESP32-S3-WROOM-1** module (hand-soldered; any of N4/N8/N8R2/N16R8) + USB-C native USB (no USB-serial chip) |
| Power switch | **MOSFET (AO3400A)** grounds PS_ON — no relay, silent, same fail-safe (PSU stays on when the ESP32 is dead) |
| Power | 5VSB from the ATX header → AMS1117-3.3. 12 V is fan-only |
| Display | 1×8 socket position (hand-soldered) for the **ST7789 (8 pins) or SSD1306 OLED (first 4 pins)** |
| Sensors | T1/T2 3-pin headers — DS18B20 **or 10 kΩ NTC** (4.7 k pull-ups on board) |
| Other | 4-pin PWM fan, WS2812B status LED position (optional) + external LED header, 4-pin front-panel header, PWR/A/B/BOOT/RESET buttons |
| Checks | KiCad 10 ERC / DRC / schematic-PCB parity: 0 violations. **Not verified on hardware yet** — follow the first power-up steps |

## Files

| File | Purpose |
|---|---|
| [`gerbers/bc250-front-pcba-v1.0-gerbers.zip`](gerbers/bc250-front-pcba-v1.0-gerbers.zip) | JLCPCB step 1: Gerbers |
| [`jlcpcb-bom.csv`](jlcpcb-bom.csv) · [`jlcpcb-cpl.csv`](jlcpcb-cpl.csv) | JLCPCB step 2: **default (semi-assembled)** BOM/CPL — U1, J2, LED1 excluded |
| `jlcpcb-bom-full.csv` · `jlcpcb-cpl-full.csv` | if you want everything placed (needs Standard assembly, ≈ +$30) |
| `bc250-front-pcba.kicad_pro` / `.kicad_sch` / `.kicad_pcb` | KiCad 10 project (libraries included) |
| [`bc250-front-pcba-schematic.pdf`](bc250-front-pcba-schematic.pdf) | schematic |
| `images/` | renders, layout and schematic SVG |
| [`../tools/`](../tools/) | `build.sh pcba` regenerates everything |

## Ordering at JLCPCB

1. [jlcpcb.com](https://jlcpcb.com) → **Order now** → upload `gerbers/bc250-front-pcba-v1.0-gerbers.zip`. PCB options: defaults (FR-4, 1.6 mm, HASL). Quantity **at least 2**, 5 recommended.
2. **PCB Assembly** on → **Economic** · Top side · assembly quantity = board quantity.
3. **Add BOM / CPL**: upload `jlcpcb-bom.csv` + `jlcpcb-cpl.csv` → all 22 lines should auto-match LCSC parts. (Extended parts: ATX header, USB-C, two pin-header types = 4; everything else is Basic.)
4. **Placement preview**: `J3` USB-C opening toward the **bottom edge**; `Q1` (SOT-23), `U2` (SOT-223), `D1`/`D2` matching the silkscreen. Rotate in the preview if not.
5. Pay → 1–2 weeks.

### Cost (estimate for 5 boards, Aug 2026 — the JLCPCB quote is authoritative)

| Item | Amount |
|---|---|
| PCB ×5 | ~$2 |
| Economic assembly setup + stencil | ~$8 + ~$1.5 |
| Extended-part loading fee ×4 | ~$12 |
| placed parts (≈ $2.6 / board) | ~$13 |
| assembly SMT + THT (≈ $1.7 / board) | ~$8.5 |
| **JLCPCB total (5)** | **≈ $45 + shipping → ≈ $9 each** |
| **JLCPCB total (2)** | **≈ $32 + shipping** |
| + bought separately: ESP32-S3-WROOM-1 (~$3.5), 1×8 female socket, WS2812B 5050 (optional) | ≈ $4 each |

→ **≈ $13 per board + display, sensors, fan.** Fully assembled (Standard, `*-full.csv`) is ≈ $100 for 5.

### Cost reductions in this version

| Item | Before | After |
|---|---|---|
| Assembly tier | Standard ($25 + $7) | **Economic ($8 + $1.5)** — only the module and LED are hand-soldered |
| Relay + driver (SRD-05V, S8050, 1N4148, 100 µF) | ~$0.7 + 4 THT parts | **one AO3400A MOSFET** ($0.09), silent |
| DevKit ($4.5–5) | 2 sockets + separate purchase | **WROOM module** ($3.5) + USB-C ($0.31) + LDO ($0.12) |
| THT R/C | 7 THT parts | **0603/0805 Basic parts** (no loading fee) |
| OLED socket + LCD socket | 2 parts | **one 1×8 socket** (OLED on the first 4 pins) |
| Front-panel header 1×6 | 1 extended part | **1×4** → same part as the fan header |
| Tact switches | 6×6 THT | **TS-1187A SMD (Basic, $0.02)** ×5 |
| Temperature sensors | 2× DS18B20 (~$2 each) | **10 kΩ NTC also supported** (~$0.2 each) |
| ESP32-S3 | N16R8 | **N4/N8 fine too** (no PSRAM needed) — you buy it, pick the cheapest |

ESP32-C3 was not adopted: the full build needs 15 GPIOs, the C3 exposes 13, and the saving is under $1. Possible for OLED/minimal-only builds.

## The three parts you solder

| Part | How |
|---|---|
| **U1 ESP32-S3-WROOM-1** | Iron-solder the edge castellations (1.27 mm pitch): flux → tack two corners to align → the rest. The large centre GND pad is **optional** (GND is also on edge pins 1/40; use hot air if you have it). Antenna toward the left board edge (see the silkscreen antenna outline). |
| **J2 display** | Solder a 1×8 2.54 mm female socket and plug the module in (recommended), or solder the module's pin header straight to the board. The OLED goes on the GND·VCC·SCL·SDA positions. |
| **LED1 WS2812B** (optional) | 5050, 4 pads, pin-1 mark (silk `1`) top-left. If you skip it, the external `LED` header (J7) carries the same data line, so nothing is lost. |

## Using it

### Firmware (same yaml, two substitutions)
```yaml
substitutions:
  relay_inverted: "true"        # same polarity as the relay module (GPIO4 LOW = power cut)
  log_uart: USB_SERIAL_JTAG     # logs over native USB
```
GPIO numbers are identical to the DevKit wiring — `bc250-front.yaml`, `bc250-front-st7789.yaml`, `bc250-front-minimal.yaml` flash unchanged. First flash over USB-C (`esphome run`), OTA afterwards. If auto-download does not trigger, hold **BOOT** and tap **RESET**. With only an external LED keep `num_leds: 1` (it shows the same pixel 0 as LED1).

### Temperature sensors — DS18B20 or NTC
- **Two DS18B20 (default)**: T1 and T2 on the GPIO7 1-Wire bus. Yaml unchanged.
- **Two NTCs (cheapest)**: move solder jumper **JP1** on the back from `1-2` (default, silk "7") to `2-3` (silk "2") so T2 gets its own channel on GPIO2. Wire each NTC between SIG and GND and replace `one_wire`/`dallas_temp` with:
  ```yaml
  sensor:
    - platform: adc
      pin: GPIO7            # T1 (T2: GPIO2)
      id: t1_adc
      attenuation: 12db
      update_interval: 5s
    - platform: resistance
      sensor: t1_adc
      configuration: DOWNSTREAM   # NTC to GND, 4.7k pull-up to 3V3
      resistor: 4.7kOhm
      reference_voltage: 3.3V
      id: t1_res
    - platform: ntc
      sensor: t1_res
      id: gpu_temp
      name: "GPU temperature"
      calibration:
        b_constant: 3950
        reference_temperature: 25°C
        reference_resistance: 10kOhm
  ```

### Connectors
| Label | Pins | Note |
|---|---|---|
| `LCD / OLED` (J2) | GND VCC SCL SDA RES DC CS BL | all 8 for ST7789 / first 4 for the OLED |
| `FAN` (J4) | GND 12V TACH PWM | 4-pin PWM fan |
| `T1` `T2` (J5 J6) | GND SIG 3V3 | DS18B20 (GND DQ VDD) or NTC (GND–SIG) |
| `LED` (J7) | 5V DIN GND | external WS2812, in parallel with LED1 (pixel 0) |
| `PANEL` (J8) | PWR A B GND | front buttons, in parallel with the on-board ones |
| `UART` (J9, not populated) | TX RX GND | debug |

### ⚠️ First power-up
1. **Before** soldering the module: plug in the PSU 24-pin only and switch the PSU on → **the PSU turning on immediately is correct** (fail-safe).
2. Check `T1` `3V3`–`GND` = 3.3 V, `FAN` `12V` = 12 V, `LED` `5V` = 5 V (also printed on the back). If fine, power off and solder the module.
3. Connect USB-C → `esphome run` → switch "server power" off in the web dashboard → the PSU should turn off.

## Design notes
- **PS_ON**: Q1 drain → PS_ON, source → GND, gate ← GPIO4 with R1 10 k pull-up to 3V3. While the ESP32 is in reset/download/dead the pull-up holds the gate high → PSU on. Firmware drives GPIO4 low → PSU off. Same logic as the active-low relay module, hence `relay_inverted: "true"`.
- **USB**: VBUS → D1 (B5819W) → 5 V rail: runs from USB alone, and the PSU's 5VSB never back-feeds the USB host. D+/D− pad pairs of the receptacle are bridged with locked tracks.
- **LED**: WS2812B VDD dropped to ~4.3 V through D2 (1N4148W) so 3.3 V data is a valid high. J7 shares the same data line (parallel).
- **BOOT/RESET**: R7/R6 10 k pull-ups, C5 1 µF EN delay.
- **Antenna**: module antenna toward the left board edge, copper removed on both layers underneath.
- **CPL rotations**: corrected by comparing pin-1 positions of the KiCad footprints against the JLCPCB (EasyEDA) footprints of the exact LCSC parts (SOT-23 / SOT-223 +180°, everything else 0°).

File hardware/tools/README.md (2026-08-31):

# hardware/tools — board generators

All boards are generated from Python tables, autorouted and checked by scripts; edit the tables, not the `.kicad_pcb`.

| File | Role |
|---|---|
| `gen_pcb.py` | placement / nets / silkscreen tables → `.kicad_pcb`, `.kicad_pro`, project footprint library. Built-in tables = DevKit carrier; `--design pcba` / `--design mini` load `designs/<name>.py` |
| `gen_sch.py` | schematic from the same tables (global labels, power symbols, no-connects, custom symbols) |
| `route.py` | Freerouting autoroute (headless) + no-connect nets + zone fill (runs under KiCad's bundled python) |
| `jlc_export.py` | JLCPCB BOM + CPL from the design's `LCSC` map and the position file (rotation corrections verified against EasyEDA footprints) |
| `build.sh [carrier\|pcba\|mini]` | everything: generate → route → ERC → DRC + schematic parity → Gerbers/drill zip → renders/PDF → install into `../<project>/` |
| `designs/pcba.py` | tables for the assembled board |
| `designs/mini.py` | tables for the 66×50 mm DevKit mini board (SMD parts under the DevKit, ATX header on board) |
| `uuids*.json` | stable symbol/footprint UUIDs so rebuilds keep the schematic ↔ PCB link |

Requirements: KiCad 10 (`KICAD_APP` env, default `~/Applications/KiCad/KiCad.app`), Java 21+ (`JAVA` env), python3. Freerouting 2.3.0 is downloaded automatically.

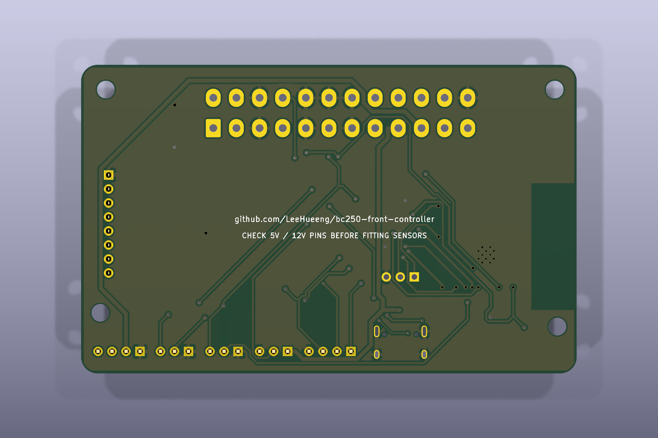
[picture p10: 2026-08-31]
hardware/bc250-front-pcba/images/board-bottom.png

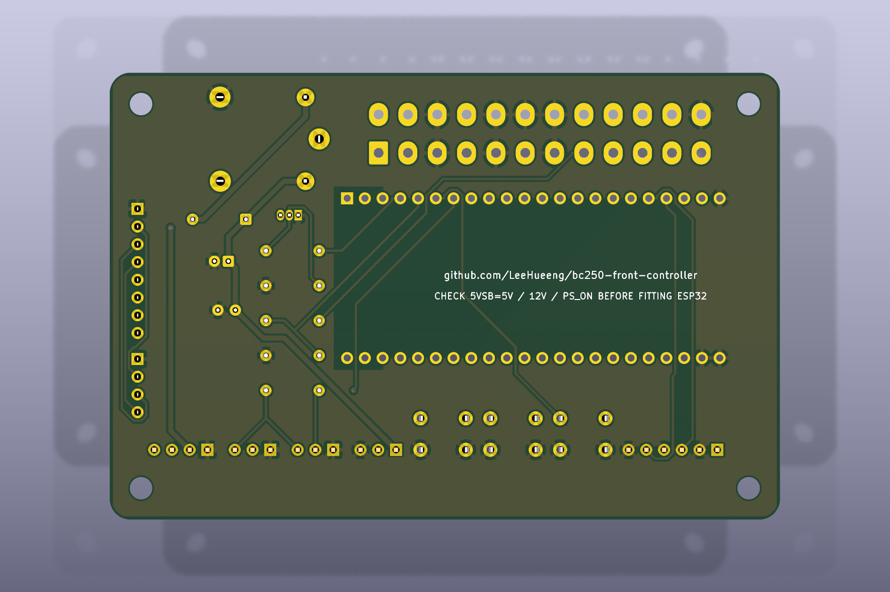
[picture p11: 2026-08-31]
hardware/bc250-front-carrier/images/board-bottom.png

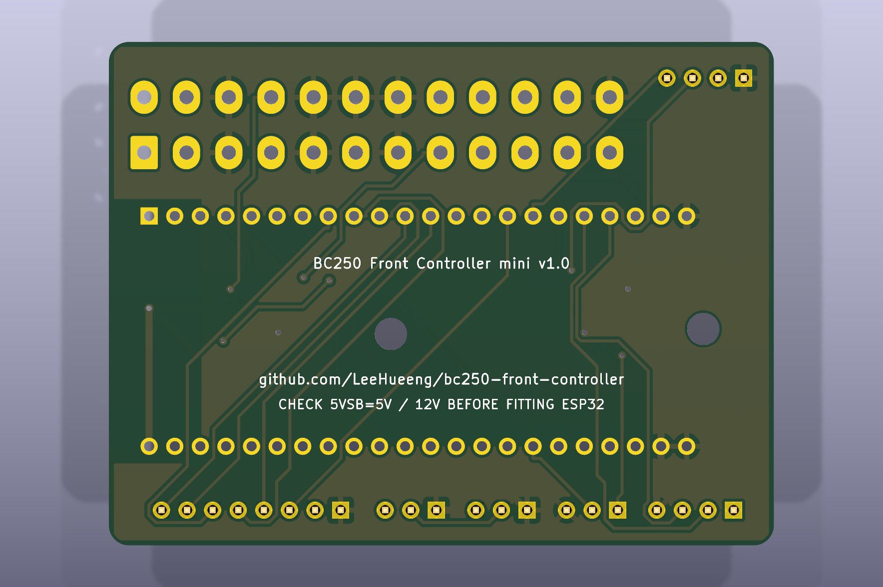
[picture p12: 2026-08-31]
hardware/bc250-front-mini/images/board-bottom.png

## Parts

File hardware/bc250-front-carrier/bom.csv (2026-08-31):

Ref | Qty | Value | Description | Package / footprint | Notes
U1 | 1 | ESP32-S3-DevKitC-1 | ESP32-S3 dev board (N8R2 / N16R8 all fine) | 2x22 pins 2.54 mm | buy with male pin headers soldered; plugs into the two 1x22 sockets
U1 socket | 2 | 1x22 female pin socket 2.54 mm | for the DevKit | THT | solder with the DevKit plugged in for alignment
J1 | 1 | ATX 24-pin motherboard header | Molex Mini-Fit Jr 5566-24A / 39-28-1243 (4.2 mm 2x12 vertical) or compatible | THT | KR: 디바이스마트/엘레파츠 'ATX 24핀 보드용 커넥터'; latch ramp toward the board edge
K1 | 1 | SRD-05VDC-SL-C | 5 V SPDT relay (Songle / Sanyou SRD) | THT 19x15.5 mm
Q1 | 1 | S8050 | NPN transistor (2N2222A / BC337 also OK) | TO-92 (E-B-C) | flat side per silkscreen
D1 | 1 | 1N4148 | flyback diode | DO-35 | cathode band toward the 'K' mark (pin 1, +5V side)
R1 | 1 | 1 kΩ 1/4 W | base resistor | axial 7.62 mm
R2,R3,R4 | 3 | 10 kΩ 1/4 W | base pull-down / PWR_OK divider | axial 7.62 mm
R5 | 1 | 4.7 kΩ 1/4 W | DS18B20 1-wire pull-up | axial 7.62 mm
C1 | 1 | 100 µF 16 V electrolytic | 5VSB bulk | radial D5 mm P2.0 mm | long leg (+) to the '+' mark
C2 | 1 | 100 nF ceramic | decoupling | disc P2.5 mm
J2 | 1 | 1x8 female pin socket 2.54 mm | ST7789V 2.4" SPI LCD module (GND VCC SCL SDA RES DC CS BL) | THT
J3 | 1 | 1x4 female pin socket 2.54 mm | SSD1306 0.96" I2C OLED (GND VCC SCL SDA) | THT
J4 | 1 | 1x4 male pin header 2.54 mm | 4-pin PWM fan (GND 12V TACH PWM) | THT | a real 4-pin fan header (KK-254 style) also fits
J5,J6 | 2 | 1x3 male pin header 2.54 mm | DS18B20 probes (GND DQ 3V3) | THT
J7 | 1 | 1x3 male pin header 2.54 mm | external WS2812 (5V DIN GND) | THT | optional
J8 | 1 | 1x6 male pin header 2.54 mm | front-panel buttons (PWR GND A GND B GND) | THT | optional
SW1,SW2,SW3 | 3 | 6x6 mm tactile switch | on-board PWR / MENU A / MENU B | THT 4-leg
H1-H4 | 4 | M3 standoff + screw | mounting (87 x 55 mm hole spacing) | 3.2 mm holes | optional

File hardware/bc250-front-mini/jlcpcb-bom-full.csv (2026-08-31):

Comment | Designator | Footprint | LCSC Part #
10uF | C1 | C_0805_2012Metric | C15850
100nF | C4 | C_0603_1608Metric | C14663
1N4148W | D2 | D_SOD-123 | C81598
ATX 24-pin | J1 | Molex_Mini-Fit_Jr_5566-24A_2x12_P4.20mm_Vertical | C114088
FAN | J4 | PinHeader_1x04_P2.54mm_Vertical | C124378
T1 | J5 | PinHeader_1x03_P2.54mm_Vertical | C49257
T2 | J6 | PinHeader_1x03_P2.54mm_Vertical | C49257
LED | J7 | PinHeader_1x03_P2.54mm_Vertical | C49257
PANEL | J8 | PinHeader_1x04_P2.54mm_Vertical | C124378
AO3400A | Q1 | SOT-23 | C20917
10k | R1,R2,R6 | R_0603_1608Metric | C25804
20k | R3 | R_0603_1608Metric | C4184
4.7k | R4 | R_0603_1608Metric | C23162

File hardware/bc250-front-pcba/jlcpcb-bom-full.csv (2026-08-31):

Comment | Designator | Footprint | LCSC Part #
10uF | C1,C2,C6 | C_0805_2012Metric | C15850
100nF | C3,C4 | C_0603_1608Metric | C14663
1uF | C5 | C_0603_1608Metric | C15849
B5819W | D1 | D_SOD-123 | C8598
1N4148W | D2 | D_SOD-123 | C81598
ATX 24-pin | J1 | Molex_Mini-Fit_Jr_5566-24A_2x12_P4.20mm_Vertical | C114088
LCD / OLED | J2 | PinSocket_1x08_P2.54mm_Vertical | C27438
USB-C | J3 | USB_C_Receptacle_HRO_TYPE-C-31-M-12 | C165948
FAN | J4 | PinHeader_1x04_P2.54mm_Vertical | C124378
T1 | J5 | PinHeader_1x03_P2.54mm_Vertical | C49257
T2 | J6 | PinHeader_1x03_P2.54mm_Vertical | C49257
LED | J7 | PinHeader_1x03_P2.54mm_Vertical | C49257
PANEL | J8 | PinHeader_1x04_P2.54mm_Vertical | C124378
WS2812B | LED1 | LED_WS2812B_PLCC4_5.0x5.0mm_P3.2mm | C2761795
AO3400A | Q1 | SOT-23 | C20917
10k | R1,R2,R3,R6,R7 | R_0603_1608Metric | C25804
4.7k | R4,R5 | R_0603_1608Metric | C23162
5.1k | R8,R9 | R_0603_1608Metric | C23186
PWR | SW1 | SW_TS-1187A | C318884
MENU A | SW2 | SW_TS-1187A | C318884
MENU B | SW3 | SW_TS-1187A | C318884
BOOT | SW4 | SW_TS-1187A | C318884
RESET | SW5 | SW_TS-1187A | C318884
ESP32-S3-WROOM-1-N16R8 | U1 | ESP32-S3-WROOM-1_edge | C2913202
AMS1117-3.3 | U2 | SOT-223-3_TabPin2 | C6186

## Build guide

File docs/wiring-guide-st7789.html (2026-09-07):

# ⚡ BC250 전면 컨트롤러 배선도 (ST7789V 2.4인치 SPI 에디션)

ESP32-S3 (2×22핀 devkit) · ATX 파워 · 2026-08-21 기준 (ESPHome bc250-front-st7789.yaml과 1:1 대응) · 6장 J2000/J2001 보조 전원은 2026-08-26 추가 · 7장 DS18B20 방수 프로브는 2026-08-28 추가 · 10장 화면 깨짐 자동 복구 · 전원 투입 자동 부팅 · 11장 BC250 종료 에이전트는 2026-09-01 추가

⚠ 시작 전 3가지
① 릴레이 접점은 반드시 NC에 배선 (ESP가 죽어도 서버는 켜진 상태 유지)
② ATX 24핀 구멍은 번호보다 선 색깔로 찾을 것 — 녹색·보라·회색은 파워에 딱 1가닥씩이라 헷갈릴 수 없음
③ PWR_OK(회색)는 5V라서 10kΩ 분압 없이 GPIO에 직결 금지

## 0. ST7789V 모듈 핀 → ESP32 연결표 (모듈에 인쇄된 라벨 기준)

ST7789V 모듈 핀 | ESP32-S3 핀 | 역할
VCC | 3V3 | 전원 (3.3V)
GND | GND | 그라운드 (공통)
SDA (DIN) | GPIO8 | SPI 데이터 입력 (MOSI)
SCL (SCLK) | GPIO9 | SPI 클럭
CS | GPIO17 | 칩 선택
DC (A0/RS) | GPIO15 | 데이터/커맨드 구분
RST (RESET) | GPIO16 | 리셋
BL | GPIO18 | 백라이트 (PWM 밝기 제어)

⚠️ 저가 모듈은 SPI 핀을 SDA/SCL로 인쇄해 놓은 경우가 많음 — SDA=MOSI, SCL=SCLK로 보면 됨.
화면이 세로로 80px 밀려 보이면 yaml의 offset_height: 0 → 80 으로 변경.

## 1. ESP32-S3 실물 핀 배치 (USB가 위로 가게 놓고 볼 것)

▣ USB-C (위쪽)
ESP32-S3

센서·디스플레이 전원 (3.3V) →

3V3

GND

GND 여분 (아무 GND나 공통)

(3.3V 여분)

3V3

TX·43

빈 핀

빈 핀 (리셋)

RST

RX·44

빈 핀

릴레이 IN →

4

1

빈 핀

PWR_OK 분압점 (10k+10k) →

5

2

빈 핀

전원 버튼 (반대쪽 GND) →

6

42

빈 핀

DS18B20 DATA 노랑 (4.7k→3.3V, 7장) →

7

41

빈 핀

ST7789 DC (A0/RS) →

15

40

빈 핀

ST7789 RST →

16

39

빈 핀

ST7789 CS →

17

38

빈 핀

ST7789 BL(백라이트) →

18

37

⛔ PSRAM 예약 — 쓰지 말 것

ST7789 MOSI (DIN) →

8

36

⛔ PSRAM 예약 — 쓰지 말 것

⛔ 스트래핑 — 비워둘 것

3

35

⛔ PSRAM 예약 — 쓰지 말 것

⛔ 스트래핑 — 비워둘 것

46

0

⛔ BOOT 버튼 — 비워둘 것

ST7789 SCLK →

9

45

⛔ 스트래핑 — 비워둘 것

팬 PWM (4핀-④) →

10

48

WS2812 LED (보드 내장 — 외장이면 여기)

팬 TACH (4핀-③) →

11

47

빈 핀

메뉴 버튼A 다음·＋ (반대쪽 GND) →

12

21

빈 핀

메뉴 버튼B 선택 (반대쪽 GND) →

13

20

빈 핀 (USB D+)

메뉴 버튼C 이전·− (반대쪽 GND) → 2026-08-31 추가

14

19

빈 핀 (USB D−)

ATX 9번 보라 5VSB →

5V

GND

GND 여분

ATX 검정 (공통 그라운드) →

GND

GND

GND 여분

(아래쪽)

색칠된 핀 = 이번에 쓰는 핀 · 회색 = 빈 핀(연결 안 함) · ⛔ = 절대 쓰면 안 되는 핀
ESP32-S3 DevKitC-1 표준 배열 기준 — 알리 호환보드는 간혹 순서가 다르니 보드에 인쇄된 핀 이름(실크)이 최종 기준. GND는 어느 GND 핀을 써도 같다.

## 2. 전원 · 릴레이 계통 (연결 구조)

점퍼선 수(male) 핀을 24핀 커넥터 구멍에 그대로 꽂고 글루건/테이프로 고정 — 납땜 불필요

## 3. ATX 24핀 구멍 지도

13

14

15

16★

17★

18

19

20

21

22

23

24

1

2

3

4

5

6

7

8★

9★

10★

11

12

커넥터 걸쇠(클립)가 위로 오게 보고 정면에서 본 배치. ★ = 이번에 쓰는 구멍 — 8 PWR_OK · 9 5VSB · 10 12V(팬) · 16 PS_ON · 17 GND
⚠ 커넥터 각인이 다를 수 있으니 최종 판단은 선 색깔로: 녹색·보라·회색은 1가닥뿐이다.

쓰는 선만 색칠 — 24가닥 중 5가닥만 건드린다

13

14

15

16
PS_ON

17
GND

18

19

20

21

22

23

24

1

2

3

4

5

6

7

8
PWR_OK

9
5VSB

10
12V

11

12

선 색 | 구멍 | 전압 | 이 보드에서 쓰는 곳
보라 | 9 | 5VSB (5 V 상시) | ESP32 전원. 파워가 꺼져 있어도 살아 있어서 컨트롤러가 항상 켜져 있음 → 보드에서 3.3 V로 낮춰 씀
녹색 | 16 | PS_ON (파워 내부 풀업, 3.3~5 V) | 접지하면 파워가 켜짐 → 릴레이 NC / MOSFET이 이 선을 GND로 당김
회색 | 8 | PWR_OK — 5 V 논리 신호 | 파워가 정상 기동했는지 감지. 5 V라 10k+10k 분압으로 2.5 V로 낮춰 GPIO5에
노랑 | 10 | 12 V | 팬 헤더 12V 핀만. 파워가 켜져 있을 때만 나옴. 컨트롤러 회로로는 안 들어감
검정 | 17 (아무 GND나) | GND | 공통 그라운드
빨강 · 주황 · 파랑 · 흰 | 나머지 19개 | 5 V · 3.3 V · −12 V · NC | 안 씀 — 비워 둔다

12 V는 팬으로만 가고 컨트롤러 쪽은 전부 5 V / 3.3 V 영역이다. BC250 본체는 24핀이 아니라 PCIe 8핀(12 V)으로 먹기 때문에 24핀이 통째로 놀고 있고, 그 중 다섯 가닥만 빌려 쓴다.

## 4. 전체 연결표

ESP32-S3 핀 | 연결 대상 | 비고
5V (VIN) | ATX 9번 보라(5VSB) | 상시 전원 — 파워 꺼져도 살아있음
GND | ATX 검정(아무거나) | 모든 장치 GND 공통
3V3 | ST7789V VCC · DS18B20 VDD(빨강선) · 풀업저항 | 3.3V 전원 레일
GPIO4 | 릴레이 IN | active-low 모듈 기준(yaml inverted:true)
GPIO5 | ATX 8번 회색(PWR_OK) | 10k+10k 분압 필수 (5V→2.5V). 2026-09-01부터 ADC로 전압을 읽어 1.5 V 넘으면 켜짐 / 1.0 V 아래면 꺼짐으로 판정 — 실제 전압은 웹/HA의 "PWR_OK 전압" 센서에 보임 (파워 켜짐 ≈ 2.5 V, 꺼짐 ≈ 0 V, 선이 안 물렸으면 0.1~0.5 V를 떠돎)
GPIO6 | 전원 버튼 | 반대쪽은 GND, 내부 풀업 사용
GPIO7 | DS18B20 ×2 DATA (노랑선) | 3.3V로 4.7k 풀업 1개, 센서는 병렬 — 방수 프로브 배선은 7장
GPIO8 | ST7789V SDA (DIN/MOSI) | SPI 데이터
GPIO9 | ST7789V SCL (SCLK) | SPI 클럭
GPIO17 | ST7789V CS | 칩 선택
GPIO15 | ST7789V DC (A0/RS) | 데이터/커맨드 구분 — 펌웨어의 화면 복구 스크립트가 같은 핀을 출력(lcd_dc)으로도 씀. 배선은 그대로
GPIO16 | ST7789V RST (RESET) | 리셋 — 부팅 때 1초 긴 리셋·하드 복구용 출력(lcd_rst)과 공유. 배선은 그대로
GPIO18 | ST7789V BL (백라이트) | PWM 밝기 제어 (메뉴에서 조절)
GPIO10 | 팬 4핀-④ PWM | 25kHz PWM 출력
GPIO11 | 팬 4핀-③ TACH | 내부 풀업, 2펄스/회전
GPIO12 / GPIO13 / GPIO14 | 메뉴 버튼 A(다음·＋) / B(선택) / C(이전·−) | 반대쪽은 GND, 내부 풀업 — 디스플레이 설정 메뉴 조작. C(GPIO14)는 2026-08-31 추가 — 13번 바로 옆 핀
GPIO48 | WS2812 상태 LED | devkit 내장 LED면 배선 불필요
릴레이 접점: COM ↔ ATX 16번 녹색(PS_ON) · NC ↔ GND · NO는 비움 / 릴레이 VCC↔5VSB, GND↔공통
팬 전원: ① GND ↔ 공통 GND · ② 12V ↔ ATX 10번 노랑 (파워 켜져 있을 때만 살아남 — 정상)

## 5. 사용법 (조작 설명서)

🔘 버튼 조작
버튼 | 동작 | 결과
전원 버튼 (GPIO6) | 짧게 | 꺼져 있으면 켜기 (단, 과열 위험이 아직 안 풀렸으면 거부) / 켜져 있으면 정상 종료: 화면 하단 SENDING SHUTDOWN → BC250 에이전트(11장)에 종료 명령 → SHUTTING DOWN 43s 카운트다운 → 전원 컷. 대기가 끝났는데 OS가 아직 응답하면 한 번 더 기다린다(최대 2배). 종료 명령이 실패하면(에이전트 없음·네트워크 불통·토큰 불일치) 전원을 끊지 않고 유지 + LED 빨강 + 하단 SHUTDOWN REQUEST FAILED가 다음 전원 조작까지 남는다 — 그때는 아래 3초 강제 컷을 쓴다
| 3초 누르고 있기 | 강제 전원 컷 (콘센트 뽑기와 동일 — 서버가 뻗었을 때만). 3초 되는 순간 바로 꺼지므로 놓는 타이밍은 상관없음 — 2026-08-31에 5초→3초로 변경
메뉴 A (GPIO12) | 짧게 | 메뉴 닫혀 있으면 다음 화면(메인 ↔ 네트워크) / 메뉴에선 다음 항목 / 값 변경 중엔 값 올리기(＋)
| 누르고 있기 | 0.6초 뒤부터 0.2초마다 자동 반복 (항목 이동·값 ＋) — 놓으면 멈춤
메뉴 C (GPIO14) 2026-08-31 추가 | 짧게 | 메뉴 닫혀 있으면 이전 화면 / 메뉴에선 이전 항목 / 값 변경 중엔 값 내리기(−)
| 누르고 있기 | 0.6초 뒤부터 0.2초마다 자동 반복 (항목 이동·값 −) — 놓으면 멈춤
메뉴 B (GPIO13) | 짧게 | 메뉴 열기 / 항목 선택 → 값 변경 모드 진입 / 한 번 더 누르면 확정
| 길게(1.2초) | 메뉴 닫기

값 바꾸는 순서: A·C로 항목 찾기 → B(변경 모드, 항목 양옆에 표시) → A(＋)·C(−)로 값 조절 → B(확정). 예전엔 A를 길게 눌러 되돌아갔지만 2026-08-31부터 C 버튼이 그 역할 — A 길게는 자동 반복이다. 메뉴는 30초 동안 버튼 조작이 없으면 자동으로 닫힌다.

🎛️ 설정 메뉴 항목 (변경값은 플래시에 저장 — 재부팅에도 유지)
팬 모드 | 자동(온도 커브) / 수동. 자동인데 GPU 온도가 안 읽히면(센서 미배선·고장) 60% 고정으로 돈다
수동 팬 % | 수동 모드일 때 팬 속도 (0~100%)
팬 프리셋 | 조용히(−10%p) / 표준 / 성능(+15%p) — 자동 커브에 가감
화면 밝기 | 10~100% — ST7789 백라이트 PWM 밝기 (웹/HA 에서는 "LCD 밝기" — 2026-09-07 이름 변경: 한글만인 이름은 저장 키가 "팬 프리셋"과 겹쳐 밝기가 0 으로 복원되던 버그). 자동 어둡게: 서버 꺼짐 → 35%(예전 10%), 밤 23~07시(인터넷 시계가 맞을 때만) → 30%, 아무 버튼이나 누르면 30초간 원래 밝기 (값은 yaml off_brightness / night_start / night_end / night_brightness)
과열 경고 C | 이 온도 넘으면 팬 100% + 경고 (70~95°C, 5°C 단위). 여기서 +10°C가 60초 지속되면 자동 정상 종료, 종료 요청이 실패하면 강제 전원 컷 (마진은 yaml critical_margin)
종료 대기 s | 정상 종료 시 OS가 꺼질 때까지 기다리는 시간 (30~180초)
화면 복구 2026-09-01 추가 | LCD를 RST 핀으로 완전히 리셋하고 초기화를 처음부터 다시 함 — 화면이 깨진 채 1분이 지나도 안 돌아올 때. 약 0.4초 꺼졌다 켜진다. 웹/HA에는 "LCD 화면 복구" 버튼. 평소의 깨짐은 10장의 자동 복구가 알아서 처리
컨트롤러 재부팅 | ESP32만 재시작 — 서버가 켜져 있으면 전원 유지 (NC 배선 덕분). 서버가 꺼져 있을 때는 재부팅 중 릴레이 입력이 잠깐 풀리며 PSU가 약 1~2초 켜졌다 꺼질 수 있음(정상, 무해) — 재부팅 뒤 꺼짐 상태는 그대로 복원된다(아래 전원 정책)
초기화 ▶ 설정값만 초기화 | 팬·밝기·과열·종료대기를 기본값으로 되돌림 — WiFi·전원 상태는 유지
초기화 ▶ 공장 초기화(WiFi 포함) | WiFi 비밀번호까지 전부 지우고 재부팅 → 다시 bc250-front-setup AP로 시작. 웹/HA에도 "공장 초기화" 버튼으로 있음

🔌 전원 정책 — 컨트롤러가 켜질 때 서버는? 2026-09-01 변경
5VSB/AC 투입 (콜드 부팅) 콘센트·PSU 스위치·5VSB 선을 뽑았다 꽂음, ESP32 RST 버튼도 포함 | 서버 무조건 ON — 마지막에 꺼 놓고 뽑았어도 켜진다 (릴레이 NC 접점이라 5VSB가 들어오는 순간 PS_ON이 접지돼 PSU가 켜지고, 펌웨어도 그 상태를 유지). 이게 싫으면 yaml power_on_boot: "false" → 예전처럼 마지막 상태 복원
소프트 재부팅 OTA 업데이트·"컨트롤러 재부팅"·안전 모드·워치독 | 마지막 상태 복원 — 서버를 꺼 둔 채였으면 부팅 직후 다시 끈다(그 사이 PSU가 1~2초 켜질 수 있음). 켜져 있었으면 NC 접점 덕에 전원이 끊기지 않는다
예전 동작 (2026-08-31까지) | 어느 경우든 마지막 상태 복원 → 서버를 끄고 전원을 뽑았다 꽂으면 꺼진 채라 "전원 넣어도 자동 부팅이 안 된다"고 보였음

💡 상태 LED
꺼짐 | 서버 전원 꺼짐
🟢 초록 | 정상 동작
🟡 노랑 | 정상 종료 진행 중
🔴 빨강 | 팬 고장 · 과열 · PSU 이상(릴레이는 켰는데 PWR_OK가 10초 넘게 안 옴) · 정상 종료 요청 실패(다음 전원 조작까지 유지, 전원은 유지됨). 무엇인지는 화면 하단 바에 적힌다

🖥️ 메인 화면 하단 바 2026-09-01 변경
평소: FAN · TEMP · PSU · NET 점 4개 | 초록=정상, 빨강=팬 고장/과열, PSU 점은 PWR_OK(회색=파워 꺼짐), NET 노랑=WiFi 끊김. PSU 점이 실제와 다르면 웹의 "PWR_OK 전압"을 볼 것 — 파워가 켜져 있는데 0 V 근처면 회색선·분압·GND 배선이 안 물린 것
🟨 SENDING SHUTDOWN | 에이전트에 종료 명령 보내는 중 (최대 3초, 그동안 버튼이 안 먹는 건 정상)
🟨 SHUTTING DOWN 43s | OS가 꺼지길 기다리는 중 — 카운트다운이 0이 되면 전원 컷. 급하면 전원 버튼 3초
🟥 SHUTDOWN REQUEST FAILED / HOLD POWER 3S TO FORCE OFF | 종료 명령이 실패해 전원을 유지 중. 11장(에이전트·IP·토큰·방화벽) 확인. 강제로 끄려면 전원 버튼 3초
🟥 PSU NOT OK / CHECK PS-ON RELAY / PWR-OK | 릴레이는 켰는데 PWR_OK가 10초 넘게 1.5 V를 못 넘음 — 파워가 정말 안 켜졌으면 릴레이 NC↔PS_ON 배선·PSU, 파워는 켜졌는데 뜨면 회색선/분압/GND가 GPIO5에 안 물린 것 ("PWR_OK 전압" 확인)
네트워크 화면(메뉴 A)에 OFFLINE | WiFi 실패 1분 뒤 설정용 AP bc250-front-setup가 뜬다(비밀번호: secrets.yaml의 ap_password) → 192.168.4.1

📶 최초 WiFi 설정 & 원격 접속
1 | 첫 부팅(또는 WiFi 실패 1분 후) ESP가 bc250-front-setup AP를 엶 — 비밀번호는 secrets.yaml의 ap_password (2026-09-01부터 잠금. 예전엔 누구나 붙어 WiFi를 바꿀 수 있었음)
2 | 폰으로 접속 → 자동으로 설정 페이지 열림 (안 열리면 브라우저에서 192.168.4.1)
3 | 집 WiFi 선택 + 비밀번호 입력 → 저장 후 자동 접속
4 | 이후 웹 대시보드: http://bc250-front.local — 전원·정상종료·팬·설정 전부 브라우저에서 조작 가능. 로그인: admin / secrets.yaml의 web_password (2026-09-01부터 digest 인증 — 브라우저 로그인창은 같고, 비밀번호가 LAN에 평문으로 안 흐름. 스크립트로 부를 땐 curl --digest -u admin:…). 페이지 JS를 펌웨어에 내장해서(local: true) 인터넷 없는 AP 모드(192.168.4.1)에서도 정상 표시
5 | Home Assistant가 있으면 몇 분 안에 자동 발견 (없어도 모든 기능 동작). 추가할 때 secrets.yaml의 api_key를 물어봄
6 | 비밀번호 파일 — 키·비밀번호(API 키, OTA 비밀번호, 웹 로그인)는 전부 secrets.yaml에 있고 git에는 올라가지 않는다(secrets.yaml.example 참고). 파일을 잃어버리면 새로 만들고 USB로 다시 플래시하면 됨. 2026-08-31 적용

디스플레이 화면은 메인(전원·온도·팬) ↔ 네트워크(WiFi·IP) 두 장 — A/C 버튼으로 넘긴다 (2026-08-31: 7초 자동 순환 제거). 온도센서·디스플레이 등이 미배선이어도 해당 기능만 꺼질 뿐 나머지는 정상 동작한다.
5V 투입 직후 화면은 약 2초 동안 꺼져 있다가 켜진다 — 정상. LCD 전원이 안정될 때까지 초기화를 미루는 것 (8장 참고).

## 6. (옵션) 보조 전원 — PSU CPU/EPS 8핀 → BC250 J2000·J2001 Micro-Fit 3.0 · 2026-08-26 추가

BC250 보드 가장자리의 Micro-Fit 8핀 헤더 두 개(J2000·J2001)에 PSU의 CPU(EPS12V) 케이블을 연결해 J1000(PCIe 8핀)과 부하를 나눈다. 위 1~5장 배선은 그대로 둔 채 케이블만 추가하는 개조.

⛔ 시작 전 4가지
① LED1 · LED2 · PGD 세 자리는 반드시 비운다. PGD를 GND에 붙이면 보드가 안 켜지고, LED 자리에 12V가 들어가면 보드를 태운다
② 12V 줄 / GND 줄이 뒤집히면 PSU 12V가 그대로 단락 → 보드에 꽂기 전에 멀티미터로 J1000과 통전 체크(6-6의 3번)가 최종 기준
③ CPU/EPS 케이블만 쓸 것 — PCIe 8핀은 12V/GND 줄이 반대라 이 어댑터에 억지로 꽂으면 극성이 뒤집힌다. 모듈러 PSU면 PSU 쪽 소켓의 CPU 라벨 확인
④ J1000(PCIe 8핀)은 계속 꽂아둔다. J2000/J2001은 대체가 아니라 부하 분담용

### 6-1. 전체 구조 — 뭘 추가하고 뭘 안 건드리나

12V(노랑) · GND(검정) · 연결 금지 자리 · 초록 테두리 = 기본안에서 쓰는 자리 · 점선 = 확장안(선이 더 있고 통전 확인을 마쳤을 때만)

### 6-2. PSU 쪽 — CPU/EPS 8핀 케이블에서 어느 선이 뭔지

EPS12V 8핀 (마더보드 쪽 커넥터를 정면에서, 걸쇠가 위로 오게)

걸쇠(클립) 쪽

12V노랑

12V노랑

12V노랑

12V노랑

GND검정

GND검정

GND검정

GND검정

걸쇠 반대쪽

규칙은 단순하다: 걸쇠 쪽 줄 4가닥 = 12V, 반대 줄 4가닥 = GND.
↳ PCIe 8핀은 정확히 반대(걸쇠 쪽이 GND)라서 헷갈리면 극성이 뒤집힌다 — 그래서 CPU 케이블만 쓴다.

4+4 분리형이면 더 쉽다. 반쪽 하나가 정확히 노랑 2 + 검정 2 → 반쪽 A는 J2000, 반쪽 B는 J2001. 자르기 전에 반쪽별로 테이프를 감아두면 끝.

선이 전부 검정인 슬리브 케이블이면 자르기 전에 커넥터에 꽂힌 상태로 걸쇠 쪽 4가닥에 노란 테이프를 감아둔다. 자르고 나면 구분할 방법이 없다. 불안하면 PSU에만 꽂고(보드 연결 없이) 24핀 PS_ON을 GND에 점퍼 → 멀티미터로 12V 나오는 선 확인.

### 6-3. 보드 쪽 — J2000 · J2001 자리 지도

J2000

PCB에서 먼 줄

LED1⛔ 비움

12V★

12V★

12V확장

LED2⛔ 비움

GND★

GND★

GND확장

PCB(보드) 쪽 줄

J2001

PCB에서 먼 줄

12V확장

12V★

12V★

PGD⛔ 비움

GND확장

GND★

GND★

GND확장

PCB(보드) 쪽 줄

보드 가장자리에서 헤더 정면(핀 구멍 쪽)을 보고, PCB가 아래로 오게 본 배치 (mothenjoyer69 문서의 "PCB down" 핀아웃). 헤더는 Molex Micro-Fit 3.0 BMI 44428-0801 호환.
★ 가운데 두 칸만 쓰는 이유: 문서 그림이 좌우 거울로 보이더라도 2·3번째 칸은 어느 쪽으로 봐도 12V/GND라 좌우 방향을 틀려도 안전하다. 1·4번째 칸은 한쪽이 LED/PGD라 실수하면 바로 사고 → 점선 "확장" 자리는 6-6의 3번 통전 확인을 마친 뒤에만 쓴다.
위/아래 줄은 하우징 키(각진 모서리) 때문에 한 방향으로만 꽂히지만, 어느 하우징 줄이 12V 줄에 오는지는 빈 하우징을 먼저 끼워보고 + J1000과 통전 체크로 정한다 (6-6의 3번).

자리 | 정체 | 왜 비우나
PGD | 보드로 들어가는 입력. 랙에서 두 번째 PSU가 살아 있음을 알리는 5V 신호(PGOOD) | GND에 닿으면 보드가 꺼진다 → GND 자리로 착각해 검정선을 꽂으면 "보드가 안 켜짐"
LED1 | 보드가 내보내는 출력(active-low) — 랙 전면 초록 LED용 | 출력 핀에 12V나 GND를 물리면 드라이버가 탄다. 선을 꽂지 않는 게 유일한 정답
LED2 | 보드가 내보내는 출력(active-low) — 랙 전면 빨강 LED용

### 6-4. 연결표

EPS 케이블 선 | → 자리 | 비고
노랑 ① | J2000 · 먼 줄 · 2번째 칸 (12V) | 기본안 (EPS 8핀 하나) 12V 4가닥 = 최대 20 A ≈ 240 W + J1000이 그대로 있으니 합계 여유 500 W↑
노랑 ② | J2000 · 먼 줄 · 3번째 칸 (12V)
노랑 ③ | J2001 · 먼 줄 · 2번째 칸 (12V)
노랑 ④ | J2001 · 먼 줄 · 3번째 칸 (12V)
검정 ① | J2000 · PCB 쪽 줄 · 2번째 칸 (GND) | 4+4 분리형이면 반쪽 A(노랑①② 검정①②) → J2000, 반쪽 B → J2001
검정 ② | J2000 · PCB 쪽 줄 · 3번째 칸 (GND)
검정 ③ | J2001 · PCB 쪽 줄 · 2번째 칸 (GND)
검정 ④ | J2001 · PCB 쪽 줄 · 3번째 칸 (GND)
비우는 자리: J2000 1번째 칸 위·아래(LED1·LED2) · J2001 4번째 칸 위(PGD) · 나머지 점선 자리는 기본안에서 빈 채로 둔다
확장안: PSU에 CPU 케이블이 2개(또는 8핀 + 4핀)면 점선 자리(J2000 4번째 칸 12V/GND · J2001 1번째 칸 12V/GND · J2001 4번째 칸 아래 GND)에 추가 → 12V 6가닥 ≈ 360 W. 반드시 6-6의 3번 통전 확인 후. 파워 하나에서 EPS 두 가닥을 뽑아 병렬로 묶는 건 같은 12V라 문제없다

### 6-5. 부품 · 공구

품목 | 수량 | 비고
Micro-Fit 3.0 리셉터클 하우징 2×4 (8핀) Molex 43025-0800 | 2 | J2000·J2001용. 알리/아마존의 "Micro-Fit 3.0 8핀 암 하네스/피그테일 18AWG" 완제품 2개를 사서 필요 없는 선은 빼내는 게 제일 빠름
암 크림프 단자 Molex 43030-0001 (주석, 18–24 AWG) | 8 + 여분 | 기본안 8자리. 피그테일 완제품이면 불필요
Micro-Fit 3.0 대응 라쳇 크림퍼 | 1 | 정품 63819-0900 또는 오픈배럴 소형 단자용(Engineer PA-09 급). 롱노즈로 눌러 접는 건 접촉 저항이 커져 발열 원인 → 비추
단자 추출 핀 (Micro-Fit용) | 1 | 피그테일에서 LED1·LED2·PGD 자리 선을 빼낼 때. 없으면 그 선을 하우징 바로 앞에서 잘라 열수축으로 절연 (빼는 게 정석)
열수축 튜브 · 압착 슬리브(또는 납땜) | — | EPS 선과 피그테일 이음용
케이블타이 · 글루건 | — | 래치를 잘라낸 하우징 빠짐 방지
멀티미터 | 1 | 필수. 통전(삐) 모드 있는 것

선 굵기 — PSU CPU 케이블은 대부분 18 AWG (고급 PSU는 16 AWG). Micro-Fit 단자는 18 AWG까지만 들어가므로 16 AWG면 바로 압착이 안 된다 → 18 AWG 피그테일에 압착 슬리브/납땜으로 잇는다. "18 AWG가 녹았다"는 보고는 PCIe 케이블 하나에 250 W 전부가 몰렸을 때 얘기고, 여기선 세 커넥터가 나눠 지므로 가닥당 전류는 훨씬 낮다.
래치 — BC250 헤더는 랙 백플레인용(BMI)이라 Micro-Fit 하우징의 걸쇠가 걸릴 홈이 없다. 하우징 걸쇠를 니퍼로 잘라내야 끝까지 들어간다 (MODDIY 어댑터 구매자 리뷰도 동일). 잘라도 하우징 모서리 키 때문에 방향은 한쪽으로만 꽂힌다. 빠짐 방지는 케이블타이나 글루건 소량.

### 6-6. 제작 · 검증 순서 (이 순서대로)

# | 할 일 | 확인 기준

1 | 선 표시. EPS 커넥터에 꽂힌 상태로 걸쇠 쪽 4가닥에 노란 테이프. 4+4면 반쪽별로 A/B 테이프. 그 다음 커넥터를 잘라낸다 | 노랑 4 · 검정 4가 구분됨
2 | 빈 하우징 끼워보기. 래치 잘라낸 빈 하우징을 J2000·J2001에 꽂아 방향 확인 → 보드에 닿는 줄에 "PCB" 표시, 1번째 칸 쪽에 "LED/PGD" 표시 | 한 방향으로만 들어감. 억지로 밀리지 않음
3 | 통전 체크 (최종 기준). PSU 케이블 전부 뽑은 상태에서 멀티미터 통전 모드: J1000의 12V 핀 ↔ J2000/J2001 각 자리 → 삐 = 12V 자리. J1000의 GND 핀 ↔ 각 자리 → 삐 = GND 자리. 어느 쪽도 안 울리는 자리 = LED1·LED2·PGD | 3장 지도와 일치: 먼 줄 12V(3칸) / PCB 쪽 GND, 안 울리는 자리가 J2000 1번째 칸 위·아래, J2001 4번째 칸 위
4 | 단자 삽입. 3번에서 확인한 자리에만 노랑/검정을 꽂는다. LED1·LED2·PGD 자리는 빈 채로. 딸깍 소리 후 살짝 당겨서 고정 확인 | 4장 연결표대로 8자리
5 | 케이블 단독 점검. 저항 모드: 노랑끼리 0 Ω · 검정끼리 0 Ω · 노랑↔검정 무한대. 하우징 정면에서 각 단자에 프로브 대고 다시 확인 | 노랑↔검정이 0 Ω이면 절대 꽂지 말 것
6 | 보드에 연결. J1000(PCIe) 그대로 + 새 케이블을 J2000·J2001에. PSU 쪽은 CPU 소켓. 케이블타이로 고정 | 세 커넥터 전부 끝까지 삽입
7 | 첫 전원. 컨트롤러 대시보드에서 "서버 전원" ON → 부팅 확인 → J2000 12V 자리에 프로브: 약 12 V. 10분 부하 후 커넥터·선 손으로 만져 온도 확인 | 미지근 = OK / 뜨거워서 못 만지면 즉시 OFF, 압착 상태 재점검

### 6-7. 전류 여유 계산

경로 | 단자 정격 | 12V 핀 | 여유
J1000 · PCIe 8핀 (Mini-Fit Jr) | 9 A/핀 | 3 | 27 A ≈ 324 W
J2000 + J2001 · 기본안 (Micro-Fit 3.0) | 최대 8.5 A/핀, 전 회로 사용 시 5 A 기준 | 2 + 2 | 20 A ≈ 240 W
J2000 + J2001 · 확장안 | 〃 | 3 + 3 | 30 A ≈ 360 W
BC250 실제 소비 — idle 65~105 W · 스톡 게이밍 최대 ~235 W · Furmark 250 W · GPU 오버클럭 시 320 W | | | 기본안 + J1000 = 560 W↑

그러니 기본안이면 충분하고, 확장안은 오버클럭을 세게 걸 때나 의미가 있다. 어느 경우든 핵심은 "한 케이블에 몰리지 않게" — 세 커넥터가 12V 플레인에서 병렬이라 자동으로 나눠 흐른다.

### 6-8. 컨트롤러(ESP32)와의 관계 — 바뀌는 것 없음

- 컨트롤러는 여전히 24핀 5VSB로 살고, PS_ON을 끊어 PSU를 끈다. PSU가 꺼지면 12V 레일 전체가 죽으므로 J1000 · J2000 · J2001이 동시에 꺼진다 — 케이블을 몇 가닥 더 꽂았다고 달라질 게 없다.
- PWR_OK(24핀 8번 회색) 감지도 그대로. 팬 12V도 그대로 24핀 10번.
- 위 0~5장의 배선과 YAML은 손댈 곳 없음.
- 참고(미검증): PGD는 "GND로 당기면 블레이드가 꺼지는" 입력이다. 나중에 ESP32 오픈드레인으로 PGD를 당기면 PSU는 켜둔 채 보드만 끄는 방식도 가능할 수 있지만, 내부 회로가 공개돼 있지 않으니 지금 프로젝트에서는 건드리지 않는다.

출처: mothenjoyer69/bc250-documentation (핀아웃·PGD·커넥터 호환) (https://github.com/mothenjoyer69/bc250-documentation/blob/main/hardware.md) · elektricM BC250 docs 핀아웃 (https://elektricm.github.io/amd-bc250-docs/hardware/pinouts/) · elektricM 전력 요구사항 (소비전력 실측) (https://elektricm.github.io/amd-bc250-docs/hardware/power/) · MODDIY EPS→2×MicroFit 어댑터 (래치 제거 리뷰) (https://www.moddiy.com/products/6837/Standard-8-Pin-EPS12V-to-2-x-MicroFit-8-Pin-Cable-for-ASRock-BC250.html) · mosfet.party 어댑터 (J1000 병행 권고) (https://mosfet.party/products/eps-8pin-to-dual-microfit) · Molex 44428-0801 (https://www.molex.com/en-us/products/part-detail/444280801)

## 7. DS18B20 방수 프로브 (스테인리스 관 · 3선 빨강/노랑/검정) 연결 2026-08-28 추가

알리/아마존의 "DS18B20 방수 스레드 온도 프로브 스테인리스 1/2/3/5 m" 기준. 관 안에 DS18B20 칩이 에폭시로 봉해져 있고 선 3가닥만 나온다. 케이블 길이가 1 m든 5 m든 배선은 똑같다. GPU 방열판용 ①, 케이스 공기용 ② 두 개를 같은 세 핀에 병렬로 단다.

⛔ 시작 전 3가지
① 빨강 = 전원(3V3) · 검정 = GND · 노랑 = DATA. 빨강↔검정이 바뀌면 센서가 뜨거워지고 몇 초 만에 망가질 수 있다 → 꽂기 전에 한 번 더 본다. 판매 페이지에 다른 색 표기가 있으면 그게 우선 (빨강·검정은 거의 고정, "남는 한 가닥 = DATA")
② 전원은 3V3에. 5V 핀 아님. 4.7 kΩ 풀업도 3V3에 건다 — DATA가 GPIO7에 직결이라 풀업을 5V에 걸면 ESP32 핀이 상한다
③ 4.7 kΩ 풀업은 버스 전체에 딱 1개 (프로브 2개라도 1개). 캐리어·PCBA·미니 보드는 이미 보드에 있으니 추가하지 않는다

### 7-1. 선 색 → 어디에 (연결 구조)

빨강 VDD · 노랑 DATA(DQ) · 검정 GND · ● = 이어진 곳 · 검정선이 노랑 줄을 넘어가는 아치(⌒) = 안 이어짐(건너뜀)
세 줄은 실제로는 "빨강 2가닥 + 저항 다리 하나를 3V3 핀에", "노랑 2가닥 + 저항 반대쪽 다리를 GPIO7 핀에", "검정 2가닥을 GND 핀에" 묶는다는 뜻. 프로브가 하나뿐이면 ②만 빼면 된다.

### 7-2. 연결표

프로브 선 | DevKit 직결 (점퍼선) | 캐리어 · PCBA · 미니 보드 (T1 / T2 3핀 헤더) | 비고
빨강 | 3V3 | 3V3 칸 (실크 3V3) | 5V 아님. DevKit 왼쪽 줄 맨 위 핀
노랑 | GPIO7 + 4.7 kΩ → 3V3 | 가운데 칸 (실크 DQ 또는 SIG) | 보드에는 4.7 k 풀업(R4/R5) 내장 → 저항 추가 금지
검정 | GND | GND 칸 (실크 GND) | 아무 GND 핀이나 같다
프로브 ② (케이스) | ①과 같은 세 핀에 같은 색끼리 병렬 | T2 헤더 (①은 T1) | T1/T2는 보드 안에서 이미 병렬(둘 다 GPIO7)
T1 · T2 헤더 칸 순서 (세 보드 공통, 실크 인쇄대로): GND ← 검정DQ ← 노랑3V3 ← 빨강 — 3핀 듀폰 암 하우징에 검정·노랑·빨강 순서로 끼워두면 그대로 꽂힌다 (거꾸로 꽂으면 빨강↔검정이 뒤집히니 실크 확인)

DevKit 직결일 때 4.7 kΩ 다는 법 — 1/4 W 4.7 kΩ 저항 한 개. 한쪽 다리는 3V3, 반대쪽 다리는 GPIO7. 제일 간단한 건 암-암 점퍼선 하우징에 프로브 노랑선과 저항 다리를 같이 끼워 GPIO7에 꽂고, 저항 반대 다리를 빨강선과 같이 3V3에 꽂는 것. 길게 쓸 거면 작은 만능기판이나 3핀 커넥터로 정리.
ESP32 내부 풀업(약 45 kΩ)으로는 대체 불가 — 너무 약해서 1 m만 넘어도 못 읽는다. 빨강을 검정과 같이 GND에 묶는 "2선 기생전원" 방식도 쓰지 않는다 (yaml은 3선 정상 전원 기준·긴 케이블에서 불안정).

### 7-3. 프로브 주소를 yaml에 넣기 (2개 쓸 때 필수)

# | 할 일 | 확인 기준

0 | 프로브가 하나뿐이면 건너뛴다. yaml의 address: 0x0000000000000000은 "버스에 하나뿐이면 그걸 자동 선택"이라 손댈 게 없다. GPU·케이스 두 항목이 같은 프로브를 가리켜 같은 값이 뜨는데 정상. 팬 커브·과열 경고는 GPU 온도 기준이니 하나만 달 거면 GPU 방열판에 | 부팅 후 "GPU 온도"가 실온 근처
1 | 둘 다 꽂고 USB 연결 → esphome run bc250-front-st7789.yaml (이미 올려뒀으면 esphome logs bc250-front-st7789.yaml). 부팅 로그에서 Found devices: 아래 두 줄을 복사 [C][gpio.one_wire]: GPIO 1-wire bus: [C][gpio.one_wire]: Pin: GPIO7 [C][gpio.one_wire]: Found devices: [C][gpio.one_wire]: 0x1c0000031edd2a28 (DS18B20) ← 예시 [C][gpio.one_wire]: 0x7a00000c3b41ee28 (DS18B20) ← 예시 | DS18B20 주소는 항상 …28로 끝남. 두 줄이 안 보이면 7-5
2 | yaml의 sensor: 아래 두 자리에 넣고 다시 esphome run - platform: dallas_temp id: gpu_temp name: "GPU 온도" address: 0x1c0000031edd2a28 # ← 1번에서 복사한 주소 update_interval: 5s - platform: dallas_temp id: case_temp name: "케이스 온도" address: 0x7a00000c3b41ee28 # ← 나머지 하나 update_interval: 10s | 주소 2개가 서로 다르고 둘 다 0x로 시작
3 | 어느 게 어느 건지 확인. GPU에 붙일 프로브를 손으로 꼭 쥐고 30초 → 대시보드(http://bc250-front.local)나 로그에서 "GPU 온도"가 올라가면 OK. "케이스 온도"가 올라가면 yaml의 두 주소를 맞바꾸고 다시 올린다 | 쥔 프로브 쪽 항목만 2~5 °C 상승 (방수관이라 느림)
4 | 프로브에 라벨(GPU / CASE)을 붙여둔다 — 나중에 케이블 정리할 때 헷갈리지 않게 | —

주소가 0x0000000000000000인 채로 프로브 2개를 꽂으면 로그에 More than one device, can't auto-select address가 뜨고 둘 다 값이 안 나온다 — 고장이 아니라 주소를 넣으라는 뜻.

### 7-4. 어디에 어떻게 붙이나

프로브 | 위치 | 고정
① GPU | GPU 방열판 핀 사이 또는 히트파이프에 관이 금속에 닿게. 팬 날개·팬 흡기 바로 앞은 피한다 | 케이블타이로 밀착 + 관과 금속 사이에 써멀패드/써멀구리스 소량. 케이블은 팬을 안 지나가게 빼서 케이스 안쪽으로
② 케이스 | 흡기 쪽 공기 중에 매달기 — 방열판·PSU·금속 판에 닿지 않게 | 케이블타이 한 개로 케이스 프레임에 늘어뜨린다
읽는 값의 의미 — 스테인리스 관은 방열판 표면 온도라 OS가 보여주는 GPU 다이 온도보다 낮게 나온다. 방수 에폭시 때문에 반응도 수십 초 느리다(정상). 부팅 후 OS 온도와 한 번 비교해서 5장 설정 메뉴의 팬 커브 시작 온도·과열 경고를 이 값 기준으로 낮춰 잡을 것. 케이블 5 m도 4.7 kΩ이면 보통 읽힌다. 읽기 실패가 잦으면 PSU·팬 전원선과 나란히 묶인 구간을 떼어 놓고, 그래도 안 되면 풀업을 3.3 kΩ(또는 2.2 kΩ)로 낮춘다. 남는 케이블은 둘둘 말지 말고 지그재그로 접어 묶는다.

### 7-5. 안 될 때

증상 | 원인 | 조치
로그에 Found no devices! / 온도 항목 "알 수 없음" | 노랑이 GPIO7에 안 갔거나 4.7 k 풀업 없음, 빨강이 3V3에 안 감 | 노랑↔GPIO7, 저항 양쪽(3V3·GPIO7), 빨강↔3V3 순서로 통전 확인. 전원 끈 상태에서 멀티미터로 GPIO7↔3V3 사이 4~5 kΩ 근처가 나와야 함
딱 85.0 °C로 고정 | DS18B20 초기값 = 전원이 불안정해 측정이 안 됨 | 빨강이 3V3에 확실히 닿는지, 접촉 불량(듀폰 헐거움) 확인
프로브가 뜨거워짐 / 인식 안 됨 | 빨강↔검정 반대 | 즉시 분리. 식힌 뒤 바르게 꽂아 다시 시도 — 오래 뒀으면 센서 사망
가끔 reading scratch pad failed / 값 튐 | 긴 케이블 + 노이즈, 풀업 약함 | PSU·팬 케이블과 떨어뜨리기 → 풀업 3.3 k/2.2 k → 케이블 짧은 것으로
More than one device, can't auto-select | 프로브 2개인데 주소가 0 | 7-3대로 주소 입력
1-wire bus is held low | 노랑이 GND에 닿음(단락) 또는 프로브 고장 | 프로브 하나씩 빼 보며 어느 쪽인지 찾기
디스플레이 온도 자리에 --만 뜸 | 위 항목 중 하나 | 로그부터 본다 (esphome logs bc250-front-st7789.yaml). 온도가 없어도 나머지 기능은 정상 동작

## 8. 전원 넣을 때 화면이 안 켜지고 버튼을 눌러야 나오는 문제 2026-08-31 조사·펌웨어 대응

증상 — 5V(PSU 5VSB 또는 USB)를 넣으면 화면이 안 켜지고, ESP32의 버튼을 눌러 재부팅해야 정상 화면이 나온다.

원인은 두 가지가 겹칠 수 있다 — 어느 쪽인지는 아래 확인 순서로 가른다.

# | 원인 | 설명

① | PC(맥)에 USB를 꽂아 둔 채 전원 투입 → 칩이 다운로드 모드로 들어감 | ESP32-S3의 두 USB 포트(UART/CH343, 네이티브 USB) 모두 PC 쪽 DTR/RTS 신호로 칩을 리셋·다운로드 모드로 보내는 회로가 달려 있다. PC가 포트를 열거나 열거(enumerate)하는 순간 rst:0x15 boot:0x0 (DOWNLOAD)로 들어가면 펌웨어가 아예 실행되지 않아 화면·WiFi·LED 전부 죽은 듯 보인다. 2026-08-31 실제로 네이티브 USB 포트에서 재현됨. 펌웨어로는 못 막는다 — 운용 중엔 PC 케이블을 빼 둘 것.
② | 콜드 부팅 때 LCD 초기화가 씹힘 | ESPHome 드라이버의 LCD 리셋이 1 ms LOW → 약 4.5 ms 대기 → 초기화 명령이라 데이터시트 한계(5 ms)에 걸쳐 있다. 전원이 막 들어와 LCD 내부가 정리되기 전이면 초기화가 무시돼 화면이 백지로 남고, 재부팅(RST)하면 LCD가 이미 안정된 상태라 정상. 펌웨어로 대응함(아래).

펌웨어 대응 (yaml esphome: on_boot: + output: lcd_rst) — ②에 대한 조치. 2026-08-31 실물에서 해결 확인됨 (전원 투입만으로 화면 켜짐)

시점 | 동작
부팅 직후 | 백라이트 OFF, LCD RST(GPIO16)를 1초간 LOW로 유지 (그 사이 LCD·릴레이로 켜진 PSU 전원 안정) → HIGH → 0.2초 대기 → 그 다음에 LCD 초기화
초기화 직후 | 메뉴에 저장된 밝기로 백라이트 ON — 화면이 "백지 → 정상"이 아니라 "꺼짐 → 정상"으로 켜진다. 전원 투입 후 약 1.5초 꺼져 있는 건 정상

2026-09-01 추가 — 2차 방어선: 부팅 10초·30초 뒤에 LCD 소프트 복구(10장)를 한 번씩 더 돌린다. LCD 초기화(부팅 1.5초) 직후에 WiFi가 켜지며 전류가 튀어 LCD가 흔들렸더라도 늦어도 30초 안에 화면이 살아난다. 그 뒤로도 1분마다 반복.

확인 순서 — 배선은 바꿀 것 없음

# | 할 것 | 결과 → 뜻

1 | USB 케이블을 PC에서 완전히 뺀다. 5VSB(또는 USB 충전기)만으로 전원 투입 | 2초 안에 화면 뜸 → 해결. 안 뜨면 2번으로
2 | 그 상태로 5초 뒤 상태 LED 색, 폰 WiFi 목록에 bc250-front-setup(AP 모드일 때) 또는 공유기 접속 여부 | LED 켜짐/AP 보임 → ESP는 부팅됨, LCD만 실패(②) → 30초 더 기다려 본다(자동 복구). 그래도 안 되면 yaml on_boot의 delay(1000)을 3000으로 올리고 LCD VCC↔GND에 100 µF 전해 콘덴서 + 10장 배선 점검 LED도 꺼짐·AP도 없음 → ESP 자체가 안 뜸 → 3번
3 | ESP32 보드의 어느 버튼으로 살아나는지 확인 (실크 RST/EN vs BOOT) | RST로 살아남 → 전원 상승이 느려 EN 타이밍 어긋남: DevKit EN↔GND에 1 µF, 5V↔GND에 470 µF 전해 콘덴서 BOOT로 살아남 → GPIO0 배선/보드 이상(정상 보드는 BOOT가 동작 중 아무 영향 없음) — GPIO0에 뭔가 닿아 있는지 확인
4 | PC에 꽂아 두고 써야 하면 | ①을 감수해야 함. 포트를 여는 프로그램(esphome logs, 시리얼 모니터)이 리셋을 걸 수 있으니, 화면이 죽어 있으면 RST 한 번

2026-09-07 추가 — 전원(USB/5 V)을 넣은 첫 부팅에서 화면이 안 나오고 RST 를 눌러야만 나올 때
실측: 콜드 부팅 첫 부팅에서는 LCD 초기화를 다시 해도(웹 "LCD 화면 복구") 안 나오고 BOOT 버튼도 소용없으며, RST 버튼 또는 소프트 재부팅(웹 "컨트롤러 재시작")으로만 살아난다. 그래서 펌웨어가 전원 투입 직후 스스로 1회 재부팅한다(부팅 1~2초 추가, 로그 콜드 부팅 — LCD 정상화를 위해 1회 자동 재부팅). 두 번째 부팅도 "콜드 부팅"으로 취급되므로 5장의 전원 정책(전원 투입 = 서버 ON)은 그대로다. 원인은 전원 투입 직후 ESP32 쪽 SPI/GPIO 경로 상태로 보이며(패널은 정상), 칩 리셋이 유일한 해법이라 이렇게 우회했다.

소프트 재부팅(OTA·웹 "컨트롤러 재시작"·안전 모드) 뒤에만 화면이 안 켜질 때
콜드 부팅(5 V 투입·RST)과 달리 소프트 재부팅은 ESP32 의 GPIO 와 LCD 패널이 이전 상태를 유지한 채 다시 초기화된다. 펌웨어는 이제 소프트 재부팅이면 부팅 3초 뒤 10장의 "하드 복구"(RST 펄스 + 전체 초기화)를 자동으로 한 번 실행한다(로그 소프트 재부팅 — LCD 하드 복구 실행). 그래도 까맣다면 펌웨어가 아니라 배선이다: 어두운 곳에서 백라이트가 조금이라도 빛나는지 먼저 보고(안 빛나면 VCC·GND·BL 선), 빛은 나는데 그림이 없으면 SCL·SDA·DC·RST·CS 점퍼를 하나씩 눌러 본다 — 보드를 손으로 눌렀을 때 켜지면 점퍼 접촉 불량이다.
참고: 서버가 꺼져 있으면 부팅 30초 뒤 백라이트가 35 %(예전 10 %)로 내려간다. 아무 버튼이나 누르면 30초간 원래 밝기. 꺼진 것처럼 보이면 먼저 버튼을 눌러 볼 것.

## 9. 쿨링팬 (4핀 PWM) 연결 2026-08-31 추가

PC용 4핀 PWM 팬을 그대로 쓴다. 팬 커넥터의 선 4가닥이 각각 아래로 간다. 선 색은 제조사마다 다르니 커넥터의 핀 위치(1~4번)가 최종 기준 — 커넥터 한쪽에 튀어나온 걸쇠(key)로 방향을 잡는다.

팬 핀 | 신호 (흔한 색) | 연결 대상 | 비고
1 | GND (검정) | 공통 GND (ESP32 GND · ATX 검정) | 반드시 ESP와 GND를 공유 — 안 그러면 PWM·TACH 신호 기준이 없어 팬이 안 돌거나 RPM이 안 읽힘
2 | +12V (노랑/빨강) | ATX 24핀 10번 노랑(12V) | 파워가 켜져 있을 때만 살아있음(정상). 3장 구멍 지도 참고
3 | TACH / Sense (초록/노랑) | GPIO11 | 회전수 신호. 내부 풀업 사용(2펄스/회전). 절대 12V에 연결 금지 — ESP 사망
4 | PWM / Control (파랑) | GPIO10 | 속도 제어. 25 kHz PWM 출력(3.3V) — 대부분의 4핀 팬이 그대로 받음

⛔ TACH(3번)를 12V에 꽂지 말 것. 팬 커넥터에서 12V(2번) 바로 옆이라 한 칸 밀리면 GPIO11로 12V가 들어가 ESP32가 즉시 죽는다. 꽂기 전에 2번과 3번을 한 번 더 확인.
⚠️ GND 공유 필수. 팬 12V를 ATX에서, 신호를 ESP에서 따올 때 두 GND가 이어져 있어야 한다(같은 PSU면 이미 공통). GND가 끊기면 팬이 안 돌거나 풀속으로 돈다.

경우별 정리
3핀 팬 | PWM(4번) 선이 없음 → 속도 제어 불가, 항상 100%로 돈다. GND·12V·TACH만 위 표대로 연결하면 RPM은 읽힌다. 속도를 줄이고 싶으면 4핀 팬으로 교체
팬을 안 달 때 | 아무것도 안 해도 됨 — 팬 관련 기능만 꺼지고 나머지는 정상. GPIO10/11은 비워둔다
2개 이상 | PWM(GPIO10)·TACH(GPIO11)는 팬 1개 기준. 여러 개면 PWM은 병렬로 나눠도 되지만 TACH는 한 개만 GPIO11에 물리고 나머지는 비운다(합산 안 됨)

증상 | 원인 | 조치
팬이 아예 안 돔 | 12V(2번) 안 옴 / 파워 꺼짐 / GND 안 이어짐 | 서버 전원 ON 상태에서 2번 자리에 약 12V 나오는지, GND가 ESP와 공통인지 확인. 서버가 꺼져 있으면 12V가 없어 원래 안 돈다 — 그때 화면은 FAN OFF / NO 12V - PSU OFF, 웹의 "쿨링팬"도 OFF·"팬 속도" 0 (2026-09-01부터. 예전엔 PWM 명령값 20%가 그대로 보여 도는 것처럼 보였음)
팬은 도는데 RPM 0 | TACH(3번)가 GPIO11에 안 감 | 3번↔GPIO11 통전 확인. 3핀 팬이 아닌지도 확인. 서버 켜짐 + PWM 20% 초과 + RPM 0이 30초 이상이면 팬 이상(화면 RPM 빨강, LED 빨강)
속도 조절이 안 되고 항상 풀속 | PWM(4번) 미연결 / 3핀 팬 / GND 끊김 | 4번↔GPIO10 확인, GND 공유 확인. 3핀 팬은 원래 조절 불가
웹·화면에서 팬 % 는 오르는데 소리 변화 없음 | 드물게 오픈드레인만 받는 팬 | GPIO10↔4번 사이에 10k 풀업(→팬 쪽 5V)이 필요한 경우가 있음 — 대부분은 불필요

속도 규칙은 5장 설정 메뉴에서: 자동(온도 커브)·수동·프리셋(조용히/표준/성능). GPU 온도가 안 읽히면 안전하게 60% 고정, 과열 경고 온도 이상이면 100%.

## 10. 화면이 깨질 때 (버튼 조작 중 등) — 자동 복구 2026-09-01 조사·펌웨어 대응

증상 — 버튼을 누르거나 하면 가끔 화면이 깨진다: 색이 반전되거나, 그림이 밀리거나, 줄무늬·백지·꺼짐이 된 채 계속 그대로다. (한 프레임만 지지직거리고 바로 돌아오는 건 여기 해당 없음 — 그건 원래 2초 안에 지워진다)

왜 "영구히" 깨지나 — ESP32는 화면 전체(240×320)를 2초마다 SPI로 다시 보내므로 픽셀 데이터가 잘못 가면 다음 프레임에 지워진다. 그런데 프레임마다 앞에 붙는 명령 바이트(주소 설정·메모리 쓰기) 하나가 노이즈로 다른 명령으로 읽히면 — 예를 들어 0x2C(메모리 쓰기)가 한 비트 바뀌어 0x28(표시 OFF)이나 0x20(색 반전 해제), 0x3A(픽셀 포맷)가 되면 — LCD 컨트롤러의 설정 레지스터가 바뀌어 버려 그 뒤 프레임을 아무리 보내도 화면은 깨진 채 남는다. RST 선이 순간 흔들려 LCD만 리셋돼도 마찬가지(절전 상태로 돌아가 백지). 2026-08-31까지의 펌웨어는 부팅 때 딱 한 번만 초기화해서, 이렇게 되면 컨트롤러를 재부팅해야 했다.

펌웨어 대응 (yaml script: lcd_heal / lcd_reset)

언제 | 무엇을 | 보이는 변화
버튼 조작 1초 뒤 (연타는 마지막 조작 기준 한 번) | 소프트 복구 — 깨지면 영구히 남는 레지스터들만 드라이버 초기값으로 다시 쓴다: 절전 해제(SLPOUT)·아이들 모드 해제·일반 표시 모드·주소 방향+BGR(MADCTL)·16비트 픽셀 포맷(COLMOD)·색 반전(INVON)·표시 ON(DISPON). 그리고 프레임을 한 번 다시 그린다 | 정상 화면이면 아무 변화 없음. 깨져 있었으면 바로 정상으로

1분마다

부팅 10초·30초 뒤
메뉴 화면 복구 / 웹·HA LCD 화면 복구 버튼 | 하드 복구 — 백라이트 끄고 → RST 핀으로 LCD 완전 리셋 → 부팅 때와 똑같은 초기화 시퀀스 전체 → 프레임 → 표시 ON → 백라이트. 소프트 복구로도 안 돌아올 때(컨트롤러 먹통) | 약 0.4초 꺼졌다 켜짐

같이 바뀐 것: 화면 갱신 주기 1초 → 2초. 한 프레임(153 KB) 그리고 보내는 동안 약 305 ms(2026-09-07 실측; 설계 때 예상은 140 ms였음) 메인 루프가 멈추는데(로그 display took a long time), 이게 버튼 반응을 늦추고 짧게 누른 걸 길게 잡히게 했다. 값들은 어차피 5초마다 바뀌고 버튼·전원 조작은 즉시 갱신되므로 체감 차이는 없다.

근본 원인은 배선 쪽 — 펌웨어는 "깨져도 1초 안에 돌아오게" 하는 것. 깨지는 빈도 자체를 줄이려면 아래를 본다. 버튼을 누를 때 깨진다는 건 버튼 선의 노이즈나 손이 닿을 때의 접촉 불량이 LCD 선(특히 RST·DC·CS)으로 넘어간다는 뜻이다.

# | 할 것 | 이유

1 | 버튼 선과 LCD 선을 같이 묶지 말 것 — 따로 떼서 다른 길로 | 버튼을 누르는 순간 3.3 V → 0 V로 급히 떨어지는 신호가 옆 선에 유도된다. 특히 RST(GPIO16)에 튀면 LCD가 리셋돼 백지
2 | LCD 모듈 VCC↔GND에 100 nF + 10 µF, DevKit 5V↔GND에 470 µF 전해 콘덴서 (핀 바로 옆에) | WiFi 송신 순간(≈300 mA) 3.3 V가 출렁이면 LCD가 먼저 죽는다. 부팅 로그에 4-Way Handshake Timeout이 반복되면 전원 불안정 의심
3 | LCD 선 8가닥은 15 cm 이하, 브레드보드 대신 납땜·핀헤더 직결. GND는 LCD·버튼·ESP 각각 짧게 별도로 | 긴 점퍼선 + 브레드보드 접촉 = 흔들면 순간 끊김. 버튼을 누르는 손이 보드를 흔든다
4 | SPI 클럭은 2026-09-07부터 기본 lcd_data_rate: "10MHz" (예전 20 MHz) | 동작 중 화면이 검게 꺼지는 일(명령 바이트 1비트 오류 → DISPOFF)이 있어 반으로 낮췄다. 한 프레임 쓰는 시간 약 140 → 200 ms(2초마다). 같은 날부터 펌웨어가 2초마다 DISPON·NORON·INVON·IDMOFF 명령을 다시 보내 깨져도 2초 안에 스스로 돌아온다(예전엔 60초 복구까지 검은 채). 그래도 자주 깨지면 점퍼를 짧게(10 cm 이하)·GND 를 LCD 바로 옆 핀에
5 | RST 선(GPIO16↔LCD RST)에 10 kΩ 풀업(3.3 V) — 선택 | 부팅 직후 1.5초 동안 ESP 핀이 떠 있을 때와 노이즈에 RST가 흔들리는 걸 막는다

확인 순서

# | 할 것 | 결과 → 뜻

1 | 깨진 화면을 아무 버튼이나 한 번 누르고 1~2초 기다림 | 돌아옴 → 소프트 복구 동작 중(정상). 배선만 1~3번대로 손보면 빈도가 준다
2 | 안 돌아오면 1분 기다림 | 돌아옴 → 같음. 안 돌아오면 3번
3 | 메뉴 B → 화면 복구 (화면이 안 보이면 웹 http://bc250-front.local → "LCD 화면 복구") | 돌아옴 → LCD가 먹통이 될 만큼 흔들렸던 것: RST 선·전원(2·5번) 먼저. 안 돌아옴 → LCD 전원·배선 끊김(0장 연결표 재확인) 또는 모듈 고장
4 | USB(CH343)로 로그를 보며 재현: esphome logs bc250-front-st7789.yaml --device /dev/cu.usbmodem5C630586901 | 깨질 때 Transmit failed가 찍히면 SPI 버스 자체 문제(3·4번). 아무 로그 없이 깨지면 LCD 쪽 선/전원(1·2·5번)

## 11. BC250 쪽 종료 에이전트 설치 (정상 종료가 되려면 필수) 2026-09-01 추가 · 저장소 bc250-agent/

왜 필요한가 — 컨트롤러는 OS에게 "꺼져 달라"고 말할 방법이 HTTP뿐이다. BC250 리눅스 안에서 그 요청을 받아 systemctl poweroff를 실행해 주는 작은 서버가 에이전트. 이게 없으면 정상 종료·과열 자동 종료가 전부 실패로 떨어져 전원 유지 + 빨강이 되고, 끄는 방법은 강제 컷(3초)뿐이다. 표준 라이브러리만 쓰는 Python 3 한 파일이라 어느 배포판이든 된다(systemd 필요). Windows는 미지원.

# | 할 것 (BC250 에서, root) | 설명

1 | 저장소의 bc250-agent/ 폴더를 BC250 으로 복사 | scp, USB, git clone 아무거나
2 | sudo ./install.sh <토큰> | 토큰 = 컨트롤러 secrets.yaml의 bc250_agent_token 값 그대로. 스크립트가 /usr/local/bin/bc250_agent.py, /etc/bc250-agent.env(600), systemd 유닛을 깔고 켠 뒤 ufw/firewalld 가 있으면 8420 을 연다. 마지막에 /health → ok 자체 확인
3 | 공유기에서 BC250 에 고정 IP(DHCP 예약) | IP 가 바뀌면 컨트롤러가 못 찾는다. 컨트롤러와 같은 서브넷이어야 함(컨트롤러는 192.168.1.x 였음)
4 | yaml substitutions: bc250_host: "그 IP" 로 바꾸고 다시 플래시 | 포트를 바꿨으면 bc250_agent_port 도. 기본 8420
5 | 확인: 다른 PC에서 curl http://BC250IP:8420/health | ok 가 오면 끝. 실제 종료 테스트는 컨트롤러의 전원 버튼 짧게(또는 웹 "정상 종료") — 화면에 SHUTTING DOWN 카운트다운이 뜨면 성공

엔드포인트 | 동작
GET /health | 200 ok — 토큰 없이 됨. 컨트롤러가 종료 대기 끝에 "아직 살아 있나" 확인하는 용도
POST /shutdown | 헤더 X-Token 이 토큰과 같으면 200 응답 후 1초 뒤 systemctl poweroff. 다르면 403(컨트롤러 로그에 "토큰 불일치")
POST /reboot | 같은 방식으로 systemctl reboot (컨트롤러는 안 씀, 수동용)

보안: 토큰이 없으면 LAN 의 아무나 서버를 끌 수 있으므로 토큰은 필수이며, 에이전트는 토큰이 비어 있으면 모든 종료 요청을 거부한다. HTTP 평문이라 같은 LAN 안에서만 쓸 것(인터넷 노출 금지). 토큰을 바꾸면 /etc/bc250-agent.env 와 컨트롤러 secrets.yaml 양쪽을 같이 바꾸고 systemctl restart bc250-agent + 컨트롤러 재플래시.

증상 (컨트롤러 쪽) | 원인 | 조치
하단 SHUTDOWN REQUEST FAILED, 로그 "연결 실패" | IP 틀림 / 에이전트 안 뜸 / 방화벽 / 다른 서브넷 | BC250 에서 systemctl status bc250-agent, 다른 PC 에서 curl http://BC250IP:8420/health
로그 "HTTP 403 (토큰 불일치)" | 양쪽 토큰이 다름 | /etc/bc250-agent.env 와 secrets.yaml 비교
카운트다운은 도는데 OS 가 안 꺼짐 → "한 번 더 기다림" | OS 종료가 대기 시간보다 오래 걸림 | 메뉴 종료 대기 s 를 늘림 (기본 60, 최대 180). 두 번째 대기까지 지나면 강제로 끊긴다

## 12. 기판이 뜨끈할 때 · 어느 ESPHome 으로 올려야 하나 2026-09-07 조사·추가

기판이 뜨끈뜨끈한 건 정상인가 — 대개 정상. ESP32-S3 DevKit 은 WiFi 절전을 끄고(power_save_mode: none) 240 MHz 로 상시 돌며, 기판의 5 V→3.3 V 레귤레이터(AMS1117)가 그 전류를 열로 버린다. 표면 40~55 °C, 즉 "따뜻~뜨끈"이 보통이다. 2026-09-07 부터 웹/HA 의 "컨트롤러 칩 온도" 센서로 칩 내부 온도를 볼 수 있다.

어디가 뜨거운가 | 판단
ESP32 모듈(은색 캔) · 그 옆 레귤레이터 | 정상. 칩 온도 45~65 °C 면 문제 없음. 80 °C 넘거나 손가락을 3초 못 댈 정도·탄내가 나면 통풍과 5 V 전원(어댑터 전압·케이블)을 확인
릴레이 모듈 | 서버 꺼짐 상태에선 코일이 계속 켜져 있어(NC 접점 방식) 미지근~따뜻한 게 정상(약 0.4 W). 서버 켜짐인데 뜨겁다면 relay_inverted 가 반대로 잡힌 것
LCD 뒷면 | 백라이트 열. 설정 메뉴 화면 밝기 를 낮추면 준다
저항·점퍼선·커넥터 | 비정상. 배선을 끊고 4장 연결표와 대조

펌웨어 쪽 "과부하"(로그의 display took a long time, 센서 튐)는 발열과 거의 무관하다 — ESP-IDF 는 루프가 한가해도 CPU 를 재우지 않아 전력 차이가 미미하다.

전원이 약할 때 — 브라운아웃 리셋 — 2026-09-07 맥 USB 포트로 전원을 주고 USB 를 뺐다 꽂는 테스트에서, 부팅 직후 WiFi 가 붙는 순간 rst:0xf (BROWNOUT_RST) 가 두 번 찍혔다(3.3 V 가 2.5 V 아래로 순간 강하). 증상은 "켜지자마자 한두 번 더 재부팅"이며, 펌웨어는 이 경우에도 릴레이 상태를 유지하고 LCD 를 다시 살리므로 동작엔 지장이 없지만 전원이 약하다는 신호다. 펌웨어는 WiFi 송신 출력을 15 dBm 으로 낮춰(신호 -46 dBm 로 충분) 피크 전류를 줄였다. 하드웨어 쪽: 짧고 굵은 USB 케이블, 허브 대신 본체 포트, 최종 설치에선 PSU 5VSB(2 A 이상)로 급전. 부팅 로그 첫 줄의 rst: 값으로 확인한다(0x1 POWERON 정상, 0xf 브라운아웃).
어느 ESPHome 으로 올려야 하나 — 2026-09-07 점검 때 보드에는 HA 쪽 ESPHome 애드온(2025.2.2) 으로 빌드한 8/31 커밋본이 올라가 있었다. 그 결과 화면이 1초마다 갱신돼 루프의 30 % 가 막히고, GPIO5(PWR_OK)가 옛 디지털 입력이라 선이 떠서 분당 70회 ON/OFF 로 튀며 로그·HA 를 밀어냈고, API 키·OTA 비밀번호·웹 비밀번호가 이 저장소의 secrets.yaml 과 달라 이 맥에서 붙을 수 없었다.

규칙 | 이유
이 저장소의 bc250-front-st7789.yaml + secrets.yaml 을 ESPHome 2026.8 이상으로 빌드해 올린다 | yaml 이 2026.8 문법(request_headers, digest 인증)을 쓴다. 2025.x 애드온에서는 아예 빌드가 안 되거나, 옛 커밋본이 올라간다
USB 로 올릴 때: esphome upload bc250-front-st7789.yaml --device /dev/cu.usbmodem5C630586901 (CH343 포트) | 다른 secrets 로 빌드된 펌웨어가 올라가 있으면 OTA 비밀번호가 안 맞아 WiFi(OTA)로는 못 올린다. 네이티브 USB 포트는 쓰지 말 것(8장)
지금 뭐가 올라가 있는지 보는 법 | 부팅 로그 첫 줄 ESPHome version … / 컴파일 시각, 또는 mDNS _esphomelib._tcp TXT 의 version. 증상으로는: display took a long time 경고가 1초마다 찍히면 옛 펌웨어(새 펌웨어는 2초마다)

BC250 Front Controller · ESPHome bc250-front-st7789.yaml 기준 (ST7789V 240×320 SPI) · 2026-08-21 작성 · 2026-09-07 갱신 (칩 온도 센서 · 12장 발열/플래시 출처) · 2026-08-31 갱신 (버튼 C · 3초 강제종료 · 콜드부팅 대기 · 화면전환 버튼 · 웹내장 · 보안 · 과열 자동종료 · 백라이트 자동어둡게 · 초기화 · 팬 연결) · 2026-09-01 갱신 (화면 깨짐 자동 복구 · 화면 복구 버튼 · 전원 투입 자동 부팅 · 갱신 2초 · 종료 실패/PSU 이상 표시 · 카운트다운 · BC250 종료 에이전트 · AP 비밀번호 · digest 인증)

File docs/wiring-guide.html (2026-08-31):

# ⚡ BC250 전면 컨트롤러 배선도

ESP32-S3 (2×22핀 devkit) · ATX 파워 · 2026-08-21 기준 (ESPHome bc250-front.yaml과 1:1 대응) · 6장 DS18B20 방수 프로브는 2026-08-28 추가

⚠ 시작 전 3가지
① 릴레이 접점은 반드시 NC에 배선 (ESP가 죽어도 서버는 켜진 상태 유지)
② ATX 24핀 구멍은 번호보다 선 색깔로 찾을 것 — 녹색·보라·회색은 파워에 딱 1가닥씩이라 헷갈릴 수 없음
③ PWR_OK(회색)는 5V라서 10kΩ 분압 없이 GPIO에 직결 금지

## 1. ESP32-S3 실물 핀 배치 (USB가 위로 가게 놓고 볼 것)

▣ USB-C (위쪽)
ESP32-S3

센서·OLED 전원 (3.3V) →

3V3

GND

GND 여분 (아무 GND나 공통)

(3.3V 여분)

3V3

TX·43

빈 핀

빈 핀 (리셋)

RST

RX·44

빈 핀

릴레이 IN →

4

1

빈 핀

PWR_OK 분압점 (10k+10k) →

5

2

빈 핀

전원 버튼 (반대쪽 GND) →

6

42

빈 핀

DS18B20 DATA 노랑 (4.7k→3.3V, 6장) →

7

41

빈 핀

빈 핀

15

40

빈 핀

빈 핀

16

39

빈 핀

빈 핀

17

38

빈 핀

빈 핀

18

37

⛔ PSRAM 예약 — 쓰지 말 것

OLED SDA →

8

36

⛔ PSRAM 예약 — 쓰지 말 것

⛔ 스트래핑 — 비워둘 것

3

35

⛔ PSRAM 예약 — 쓰지 말 것

⛔ 스트래핑 — 비워둘 것

46

0

⛔ BOOT 버튼 — 비워둘 것

OLED SCL →

9

45

⛔ 스트래핑 — 비워둘 것

팬 PWM (4핀-④) →

10

48

WS2812 LED (보드 내장 — 외장이면 여기)

팬 TACH (4핀-③) →

11

47

빈 핀

메뉴 버튼A 이동 (반대쪽 GND) →

12

21

빈 핀

메뉴 버튼B 선택 (반대쪽 GND) →

13

20

빈 핀 (USB D+)

빈 핀

14

19

빈 핀 (USB D−)

ATX 9번 보라 5VSB →

5V

GND

GND 여분

ATX 검정 (공통 그라운드) →

GND

GND

GND 여분

(아래쪽)

색칠된 핀 = 이번에 쓰는 핀 · 회색 = 빈 핀(연결 안 함) · ⛔ = 절대 쓰면 안 되는 핀
ESP32-S3 DevKitC-1 표준 배열 기준 — 알리 호환보드는 간혹 순서가 다르니 보드에 인쇄된 핀 이름(실크)이 최종 기준. GND는 어느 GND 핀을 써도 같다.

## 2. 전원 · 릴레이 계통 (연결 구조)

점퍼선 수(male) 핀을 24핀 커넥터 구멍에 그대로 꽂고 글루건/테이프로 고정 — 납땜 불필요

## 3. ATX 24핀 구멍 지도

13

14

15

16★

17★

18

19

20

21

22

23

24

1

2

3

4

5

6

7

8★

9★

10★

11

12

커넥터 걸쇠(클립)가 위로 오게 보고 정면에서 본 배치. ★ = 이번에 쓰는 구멍 — 8 PWR_OK · 9 5VSB · 10 12V(팬) · 16 PS_ON · 17 GND
⚠ 커넥터 각인이 다를 수 있으니 최종 판단은 선 색깔로: 녹색·보라·회색은 1가닥뿐이다.

쓰는 선만 색칠 — 24가닥 중 5가닥만 건드린다

13

14

15

16
PS_ON

17
GND

18

19

20

21

22

23

24

1

2

3

4

5

6

7

8
PWR_OK

9
5VSB

10
12V

11

12

선 색 | 구멍 | 전압 | 이 보드에서 쓰는 곳
보라 | 9 | 5VSB (5 V 상시) | ESP32 전원. 파워가 꺼져 있어도 살아 있어서 컨트롤러가 항상 켜져 있음 → 보드에서 3.3 V로 낮춰 씀
녹색 | 16 | PS_ON (파워 내부 풀업, 3.3~5 V) | 접지하면 파워가 켜짐 → 릴레이 NC / MOSFET이 이 선을 GND로 당김
회색 | 8 | PWR_OK — 5 V 논리 신호 | 파워가 정상 기동했는지 감지. 5 V라 10k+10k 분압으로 2.5 V로 낮춰 GPIO5에
노랑 | 10 | 12 V | 팬 헤더 12V 핀만. 파워가 켜져 있을 때만 나옴. 컨트롤러 회로로는 안 들어감
검정 | 17 (아무 GND나) | GND | 공통 그라운드
빨강 · 주황 · 파랑 · 흰 | 나머지 19개 | 5 V · 3.3 V · −12 V · NC | 안 씀 — 비워 둔다

12 V는 팬으로만 가고 컨트롤러 쪽은 전부 5 V / 3.3 V 영역이다. BC250 본체는 24핀이 아니라 PCIe 8핀(12 V)으로 먹기 때문에 24핀이 통째로 놀고 있고, 그 중 다섯 가닥만 빌려 쓴다.

## 4. 전체 연결표

ESP32-S3 핀 | 연결 대상 | 비고
5V (VIN) | ATX 9번 보라(5VSB) | 상시 전원 — 파워 꺼져도 살아있음
GND | ATX 검정(아무거나) | 모든 장치 GND 공통
3V3 | OLED VCC · DS18B20 VDD(빨강선) · 풀업저항 | 3.3V 전원 레일
GPIO4 | 릴레이 IN | active-low 모듈 기준(yaml inverted:true)
GPIO5 | ATX 8번 회색(PWR_OK) | 10k+10k 분압 필수 (5V→2.5V)
GPIO6 | 전원 버튼 | 반대쪽은 GND, 내부 풀업 사용
GPIO7 | DS18B20 ×2 DATA (노랑선) | 3.3V로 4.7k 풀업 1개, 센서는 병렬 — 방수 프로브 배선은 6장
GPIO8 / GPIO9 | OLED SDA / SCL | OLED 전원은 3.3V
GPIO10 | 팬 4핀-④ PWM | 25kHz PWM 출력
GPIO11 | 팬 4핀-③ TACH | 내부 풀업, 2펄스/회전
GPIO12 / GPIO13 | 메뉴 버튼 A(이동) / B(선택) | 반대쪽은 GND, 내부 풀업 — OLED 설정 메뉴 조작
GPIO48 | WS2812 상태 LED | devkit 내장 LED면 배선 불필요
릴레이 접점: COM ↔ ATX 16번 녹색(PS_ON) · NC ↔ GND · NO는 비움 / 릴레이 VCC↔5VSB, GND↔공통
팬 전원: ① GND ↔ 공통 GND · ② 12V ↔ ATX 10번 노랑 (파워 켜져 있을 때만 살아남 — 정상)

## 5. 사용법 (조작 설명서)

🔘 버튼 조작
버튼 | 동작 | 결과
전원 버튼 (GPIO6) | 짧게 | 꺼져 있으면 켜기 / 켜져 있으면 정상 종료 (OS에 종료 명령 → 대기 → 전원 컷)
| 5초 이상 | 강제 전원 컷 (콘센트 뽑기와 동일 — 서버가 뻗었을 때만)
메뉴 A (GPIO12) | 짧게 | 메뉴 열기 / 다음 항목으로 이동
| 길게(0.8초) | 이전 항목으로 이동
메뉴 B (GPIO13) | 짧게 | 항목 선택 → 값 변경 모드 진입/확정
| 길게(1.2초) | 메뉴 닫기

🎛️ 설정 메뉴 항목 (변경값은 플래시에 저장 — 재부팅에도 유지)
팬 모드 | 자동(온도 커브) / 수동
수동 팬 % | 수동 모드일 때 팬 속도 (0~100%)
팬 프리셋 | 조용히(−10%p) / 표준 / 성능(+15%p) — 자동 커브에 가감
OLED 밝기 | 10~100%
과열 경고 C | 이 온도 넘으면 팬 100% + 경고 (70~95°C)
종료 대기 s | 정상 종료 시 OS가 꺼질 때까지 기다리는 시간 (30~180초)
컨트롤러 재부팅 | ESP32만 재시작 — 서버 전원은 유지됨 (NC 배선 덕분)

💡 상태 LED
꺼짐 | 서버 전원 꺼짐
🟢 초록 | 정상 동작
🟡 노랑 | 정상 종료 진행 중
🔴 빨강 | 팬 고장 또는 과열

📶 최초 WiFi 설정 & 원격 접속
1 | 첫 부팅(또는 WiFi 실패 1분 후) ESP가 bc250-front-setup AP를 엶 (비밀번호 없음)
2 | 폰으로 접속 → 자동으로 설정 페이지 열림 (안 열리면 브라우저에서 192.168.4.1)
3 | 집 WiFi 선택 + 비밀번호 입력 → 저장 후 자동 접속
4 | 이후 웹 대시보드: http://bc250-front.local — 전원·정상종료·팬·설정 전부 브라우저에서 조작 가능
5 | Home Assistant가 있으면 몇 분 안에 자동 발견 (없어도 모든 기능 동작)

OLED 상태 화면은 7초마다 메인(전원·온도·팬) ↔ 네트워크(WiFi·IP)를 자동 순환. 온도센서·OLED 등이 미배선이어도 해당 기능만 꺼질 뿐 나머지는 정상 동작한다.

## 6. DS18B20 방수 프로브 (스테인리스 관 · 3선 빨강/노랑/검정) 연결 2026-08-28 추가

알리/아마존의 "DS18B20 방수 스레드 온도 프로브 스테인리스 1/2/3/5 m" 기준. 관 안에 DS18B20 칩이 에폭시로 봉해져 있고 선 3가닥만 나온다. 케이블 길이가 1 m든 5 m든 배선은 똑같다. GPU 방열판용 ①, 케이스 공기용 ② 두 개를 같은 세 핀에 병렬로 단다.

⛔ 시작 전 3가지
① 빨강 = 전원(3V3) · 검정 = GND · 노랑 = DATA. 빨강↔검정이 바뀌면 센서가 뜨거워지고 몇 초 만에 망가질 수 있다 → 꽂기 전에 한 번 더 본다. 판매 페이지에 다른 색 표기가 있으면 그게 우선 (빨강·검정은 거의 고정, "남는 한 가닥 = DATA")
② 전원은 3V3에. 5V 핀 아님. 4.7 kΩ 풀업도 3V3에 건다 — DATA가 GPIO7에 직결이라 풀업을 5V에 걸면 ESP32 핀이 상한다
③ 4.7 kΩ 풀업은 버스 전체에 딱 1개 (프로브 2개라도 1개). 캐리어·PCBA·미니 보드는 이미 보드에 있으니 추가하지 않는다

### 6-1. 선 색 → 어디에 (연결 구조)

빨강 VDD · 노랑 DATA(DQ) · 검정 GND · ● = 이어진 곳 · 검정선이 노랑 줄을 넘어가는 아치(⌒) = 안 이어짐(건너뜀)
세 줄은 실제로는 "빨강 2가닥 + 저항 다리 하나를 3V3 핀에", "노랑 2가닥 + 저항 반대쪽 다리를 GPIO7 핀에", "검정 2가닥을 GND 핀에" 묶는다는 뜻. 프로브가 하나뿐이면 ②만 빼면 된다.

### 6-2. 연결표

프로브 선 | DevKit 직결 (점퍼선) | 캐리어 · PCBA · 미니 보드 (T1 / T2 3핀 헤더) | 비고
빨강 | 3V3 | 3V3 칸 (실크 3V3) | 5V 아님. DevKit 왼쪽 줄 맨 위 핀
노랑 | GPIO7 + 4.7 kΩ → 3V3 | 가운데 칸 (실크 DQ 또는 SIG) | 보드에는 4.7 k 풀업(R4/R5) 내장 → 저항 추가 금지
검정 | GND | GND 칸 (실크 GND) | 아무 GND 핀이나 같다
프로브 ② (케이스) | ①과 같은 세 핀에 같은 색끼리 병렬 | T2 헤더 (①은 T1) | T1/T2는 보드 안에서 이미 병렬(둘 다 GPIO7)
T1 · T2 헤더 칸 순서 (세 보드 공통, 실크 인쇄대로): GND ← 검정DQ ← 노랑3V3 ← 빨강 — 3핀 듀폰 암 하우징에 검정·노랑·빨강 순서로 끼워두면 그대로 꽂힌다 (거꾸로 꽂으면 빨강↔검정이 뒤집히니 실크 확인)

DevKit 직결일 때 4.7 kΩ 다는 법 — 1/4 W 4.7 kΩ 저항 한 개. 한쪽 다리는 3V3, 반대쪽 다리는 GPIO7. 제일 간단한 건 암-암 점퍼선 하우징에 프로브 노랑선과 저항 다리를 같이 끼워 GPIO7에 꽂고, 저항 반대 다리를 빨강선과 같이 3V3에 꽂는 것. 길게 쓸 거면 작은 만능기판이나 3핀 커넥터로 정리.
ESP32 내부 풀업(약 45 kΩ)으로는 대체 불가 — 너무 약해서 1 m만 넘어도 못 읽는다. 빨강을 검정과 같이 GND에 묶는 "2선 기생전원" 방식도 쓰지 않는다 (yaml은 3선 정상 전원 기준·긴 케이블에서 불안정).

### 6-3. 프로브 주소를 yaml에 넣기 (2개 쓸 때 필수)

# | 할 일 | 확인 기준

0 | 프로브가 하나뿐이면 건너뛴다. yaml의 address: 0x0000000000000000은 "버스에 하나뿐이면 그걸 자동 선택"이라 손댈 게 없다. GPU·케이스 두 항목이 같은 프로브를 가리켜 같은 값이 뜨는데 정상. 팬 커브·과열 경고는 GPU 온도 기준이니 하나만 달 거면 GPU 방열판에 | 부팅 후 "GPU 온도"가 실온 근처
1 | 둘 다 꽂고 USB 연결 → esphome run bc250-front.yaml (이미 올려뒀으면 esphome logs bc250-front.yaml). 부팅 로그에서 Found devices: 아래 두 줄을 복사 [C][gpio.one_wire]: GPIO 1-wire bus: [C][gpio.one_wire]: Pin: GPIO7 [C][gpio.one_wire]: Found devices: [C][gpio.one_wire]: 0x1c0000031edd2a28 (DS18B20) ← 예시 [C][gpio.one_wire]: 0x7a00000c3b41ee28 (DS18B20) ← 예시 | DS18B20 주소는 항상 …28로 끝남. 두 줄이 안 보이면 6-5
2 | yaml의 sensor: 아래 두 자리에 넣고 다시 esphome run - platform: dallas_temp id: gpu_temp name: "GPU 온도" address: 0x1c0000031edd2a28 # ← 1번에서 복사한 주소 update_interval: 5s - platform: dallas_temp id: case_temp name: "케이스 온도" address: 0x7a00000c3b41ee28 # ← 나머지 하나 update_interval: 10s | 주소 2개가 서로 다르고 둘 다 0x로 시작
3 | 어느 게 어느 건지 확인. GPU에 붙일 프로브를 손으로 꼭 쥐고 30초 → 대시보드(http://bc250-front.local)나 로그에서 "GPU 온도"가 올라가면 OK. "케이스 온도"가 올라가면 yaml의 두 주소를 맞바꾸고 다시 올린다 | 쥔 프로브 쪽 항목만 2~5 °C 상승 (방수관이라 느림)
4 | 프로브에 라벨(GPU / CASE)을 붙여둔다 — 나중에 케이블 정리할 때 헷갈리지 않게 | —

주소가 0x0000000000000000인 채로 프로브 2개를 꽂으면 로그에 More than one device, can't auto-select address가 뜨고 둘 다 값이 안 나온다 — 고장이 아니라 주소를 넣으라는 뜻.

### 6-4. 어디에 어떻게 붙이나

프로브 | 위치 | 고정
① GPU | GPU 방열판 핀 사이 또는 히트파이프에 관이 금속에 닿게. 팬 날개·팬 흡기 바로 앞은 피한다 | 케이블타이로 밀착 + 관과 금속 사이에 써멀패드/써멀구리스 소량. 케이블은 팬을 안 지나가게 빼서 케이스 안쪽으로
② 케이스 | 흡기 쪽 공기 중에 매달기 — 방열판·PSU·금속 판에 닿지 않게 | 케이블타이 한 개로 케이스 프레임에 늘어뜨린다
읽는 값의 의미 — 스테인리스 관은 방열판 표면 온도라 OS가 보여주는 GPU 다이 온도보다 낮게 나온다. 방수 에폭시 때문에 반응도 수십 초 느리다(정상). 부팅 후 OS 온도와 한 번 비교해서 5장 설정 메뉴의 팬 커브 시작 온도·과열 경고를 이 값 기준으로 낮춰 잡을 것. 케이블 5 m도 4.7 kΩ이면 보통 읽힌다. 읽기 실패가 잦으면 PSU·팬 전원선과 나란히 묶인 구간을 떼어 놓고, 그래도 안 되면 풀업을 3.3 kΩ(또는 2.2 kΩ)로 낮춘다. 남는 케이블은 둘둘 말지 말고 지그재그로 접어 묶는다.

### 6-5. 안 될 때

증상 | 원인 | 조치
로그에 Found no devices! / 온도 항목 "알 수 없음" | 노랑이 GPIO7에 안 갔거나 4.7 k 풀업 없음, 빨강이 3V3에 안 감 | 노랑↔GPIO7, 저항 양쪽(3V3·GPIO7), 빨강↔3V3 순서로 통전 확인. 전원 끈 상태에서 멀티미터로 GPIO7↔3V3 사이 4~5 kΩ 근처가 나와야 함
딱 85.0 °C로 고정 | DS18B20 초기값 = 전원이 불안정해 측정이 안 됨 | 빨강이 3V3에 확실히 닿는지, 접촉 불량(듀폰 헐거움) 확인
프로브가 뜨거워짐 / 인식 안 됨 | 빨강↔검정 반대 | 즉시 분리. 식힌 뒤 바르게 꽂아 다시 시도 — 오래 뒀으면 센서 사망
가끔 reading scratch pad failed / 값 튐 | 긴 케이블 + 노이즈, 풀업 약함 | PSU·팬 케이블과 떨어뜨리기 → 풀업 3.3 k/2.2 k → 케이블 짧은 것으로
More than one device, can't auto-select | 프로브 2개인데 주소가 0 | 6-3대로 주소 입력
1-wire bus is held low | 노랑이 GND에 닿음(단락) 또는 프로브 고장 | 프로브 하나씩 빼 보며 어느 쪽인지 찾기
디스플레이 온도 자리에 --만 뜸 | 위 항목 중 하나 | 로그부터 본다 (esphome logs bc250-front.yaml). 온도가 없어도 나머지 기능은 정상 동작

BC250 Front Controller · ESPHome bc250-front.yaml 기준 · 2026-08-21

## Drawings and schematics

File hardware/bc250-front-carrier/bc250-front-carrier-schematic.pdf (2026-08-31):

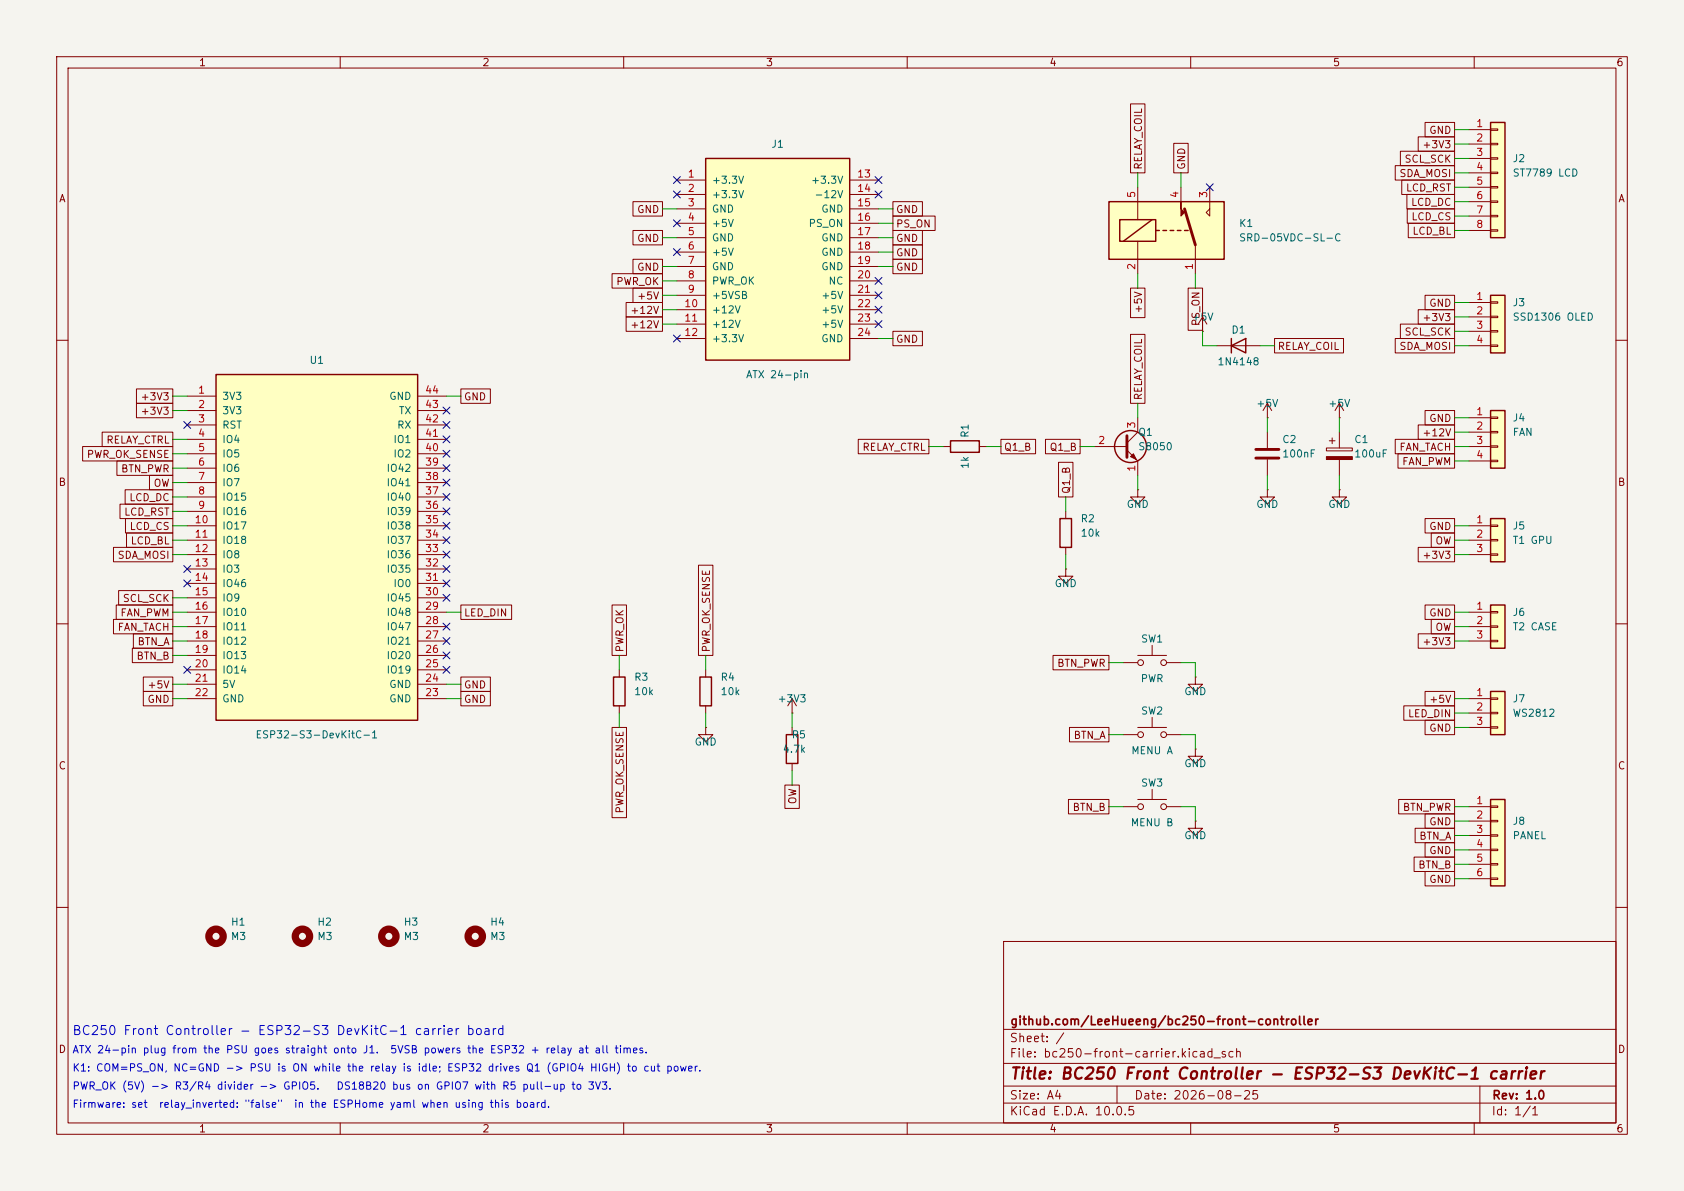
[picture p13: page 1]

github.com/LeeHueeng/bc250-front-controller
Sheet: /
File: bc250-front-carrier.kicad_sch
Title: BC250 Front Controller - ESP32-S3 DevKitC-1 carrier

Firmware: set relay_inverted: "false" in the ESPHome yaml when using this board. BC250 Front Controller - ESP32-S3 DevKitC-1 carrier board

Size: A4 | Rev: 1.0
KiCad E.D.A. 10.0.5 | Id: 1/1

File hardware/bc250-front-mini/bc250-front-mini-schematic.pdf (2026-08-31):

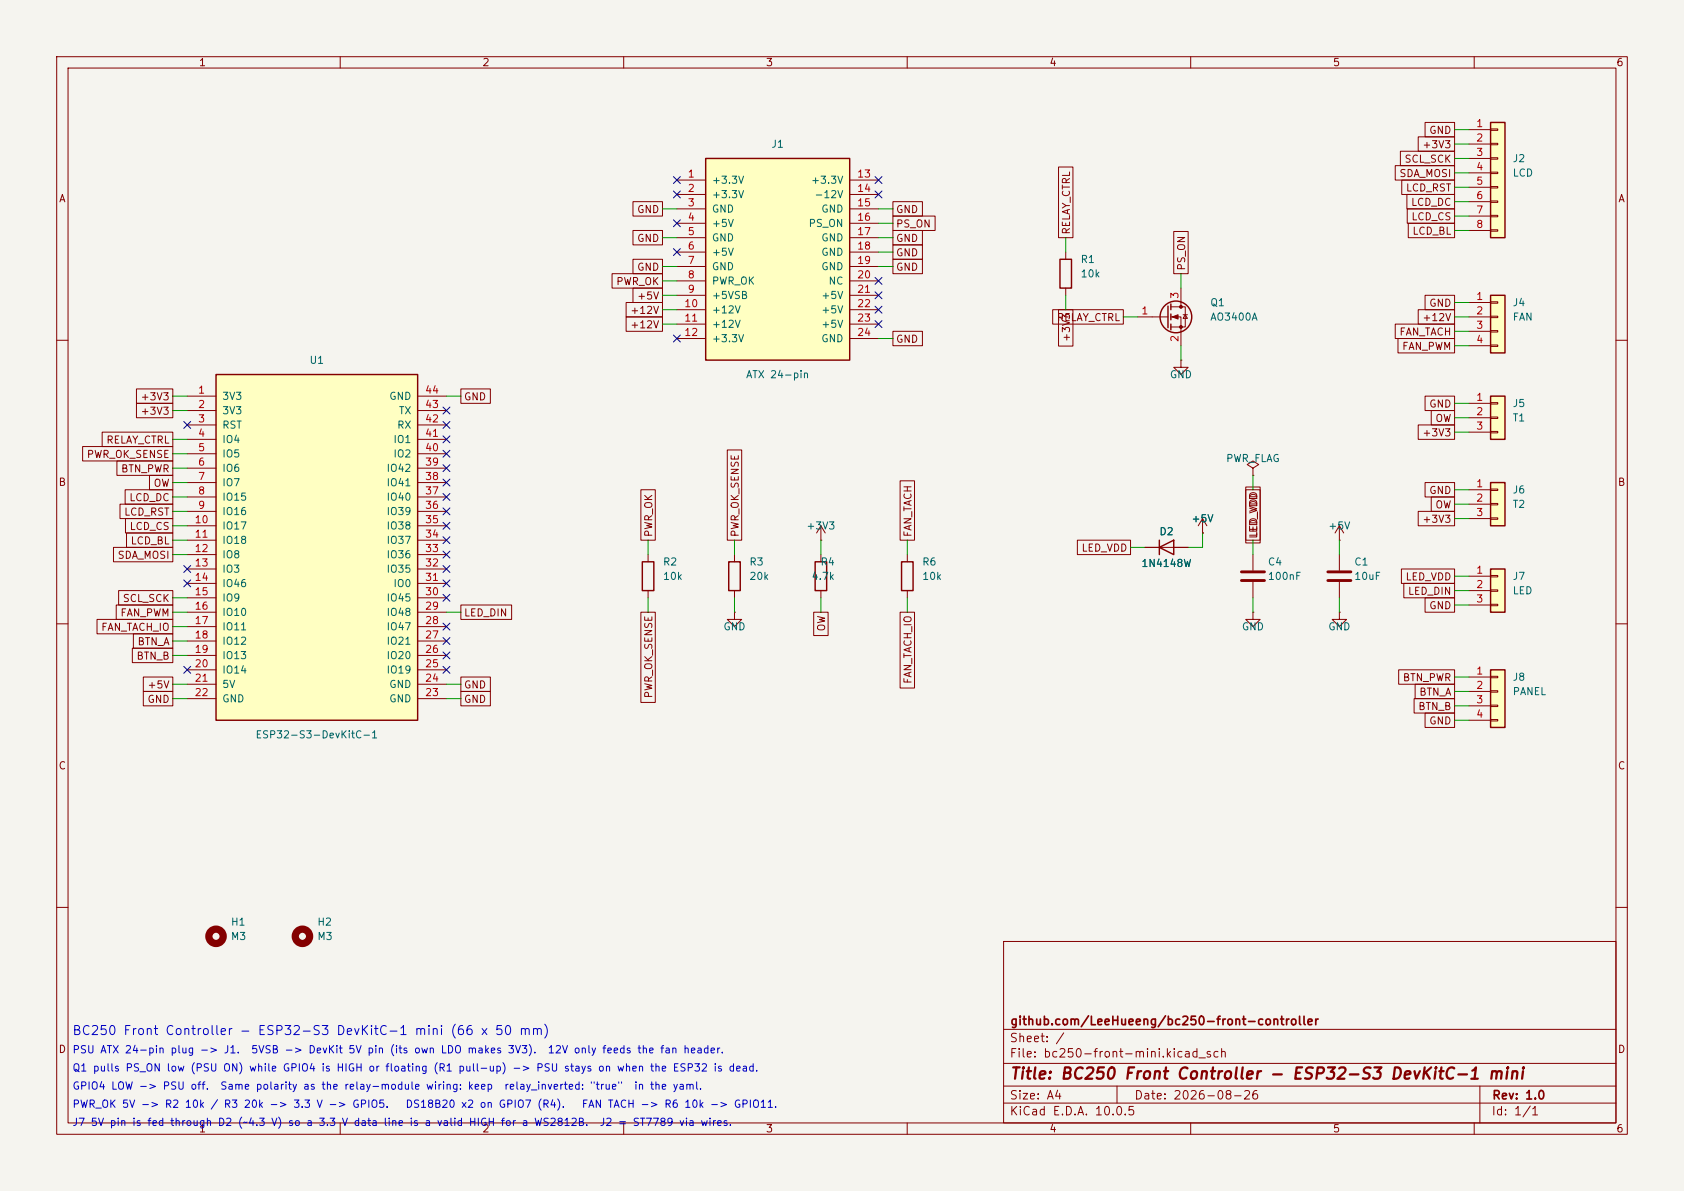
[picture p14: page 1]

github.com/LeeHueeng/bc250-front-controller GND

Sheet: /
File: bc250-front-mini.kicad_sch
Title: BC250 Front Controller - ESP32-S3 DevKitC-1 mini

Size: A4 | Rev: 1.0
KiCad E.D.A. 10.0.5 | Id: 1/1

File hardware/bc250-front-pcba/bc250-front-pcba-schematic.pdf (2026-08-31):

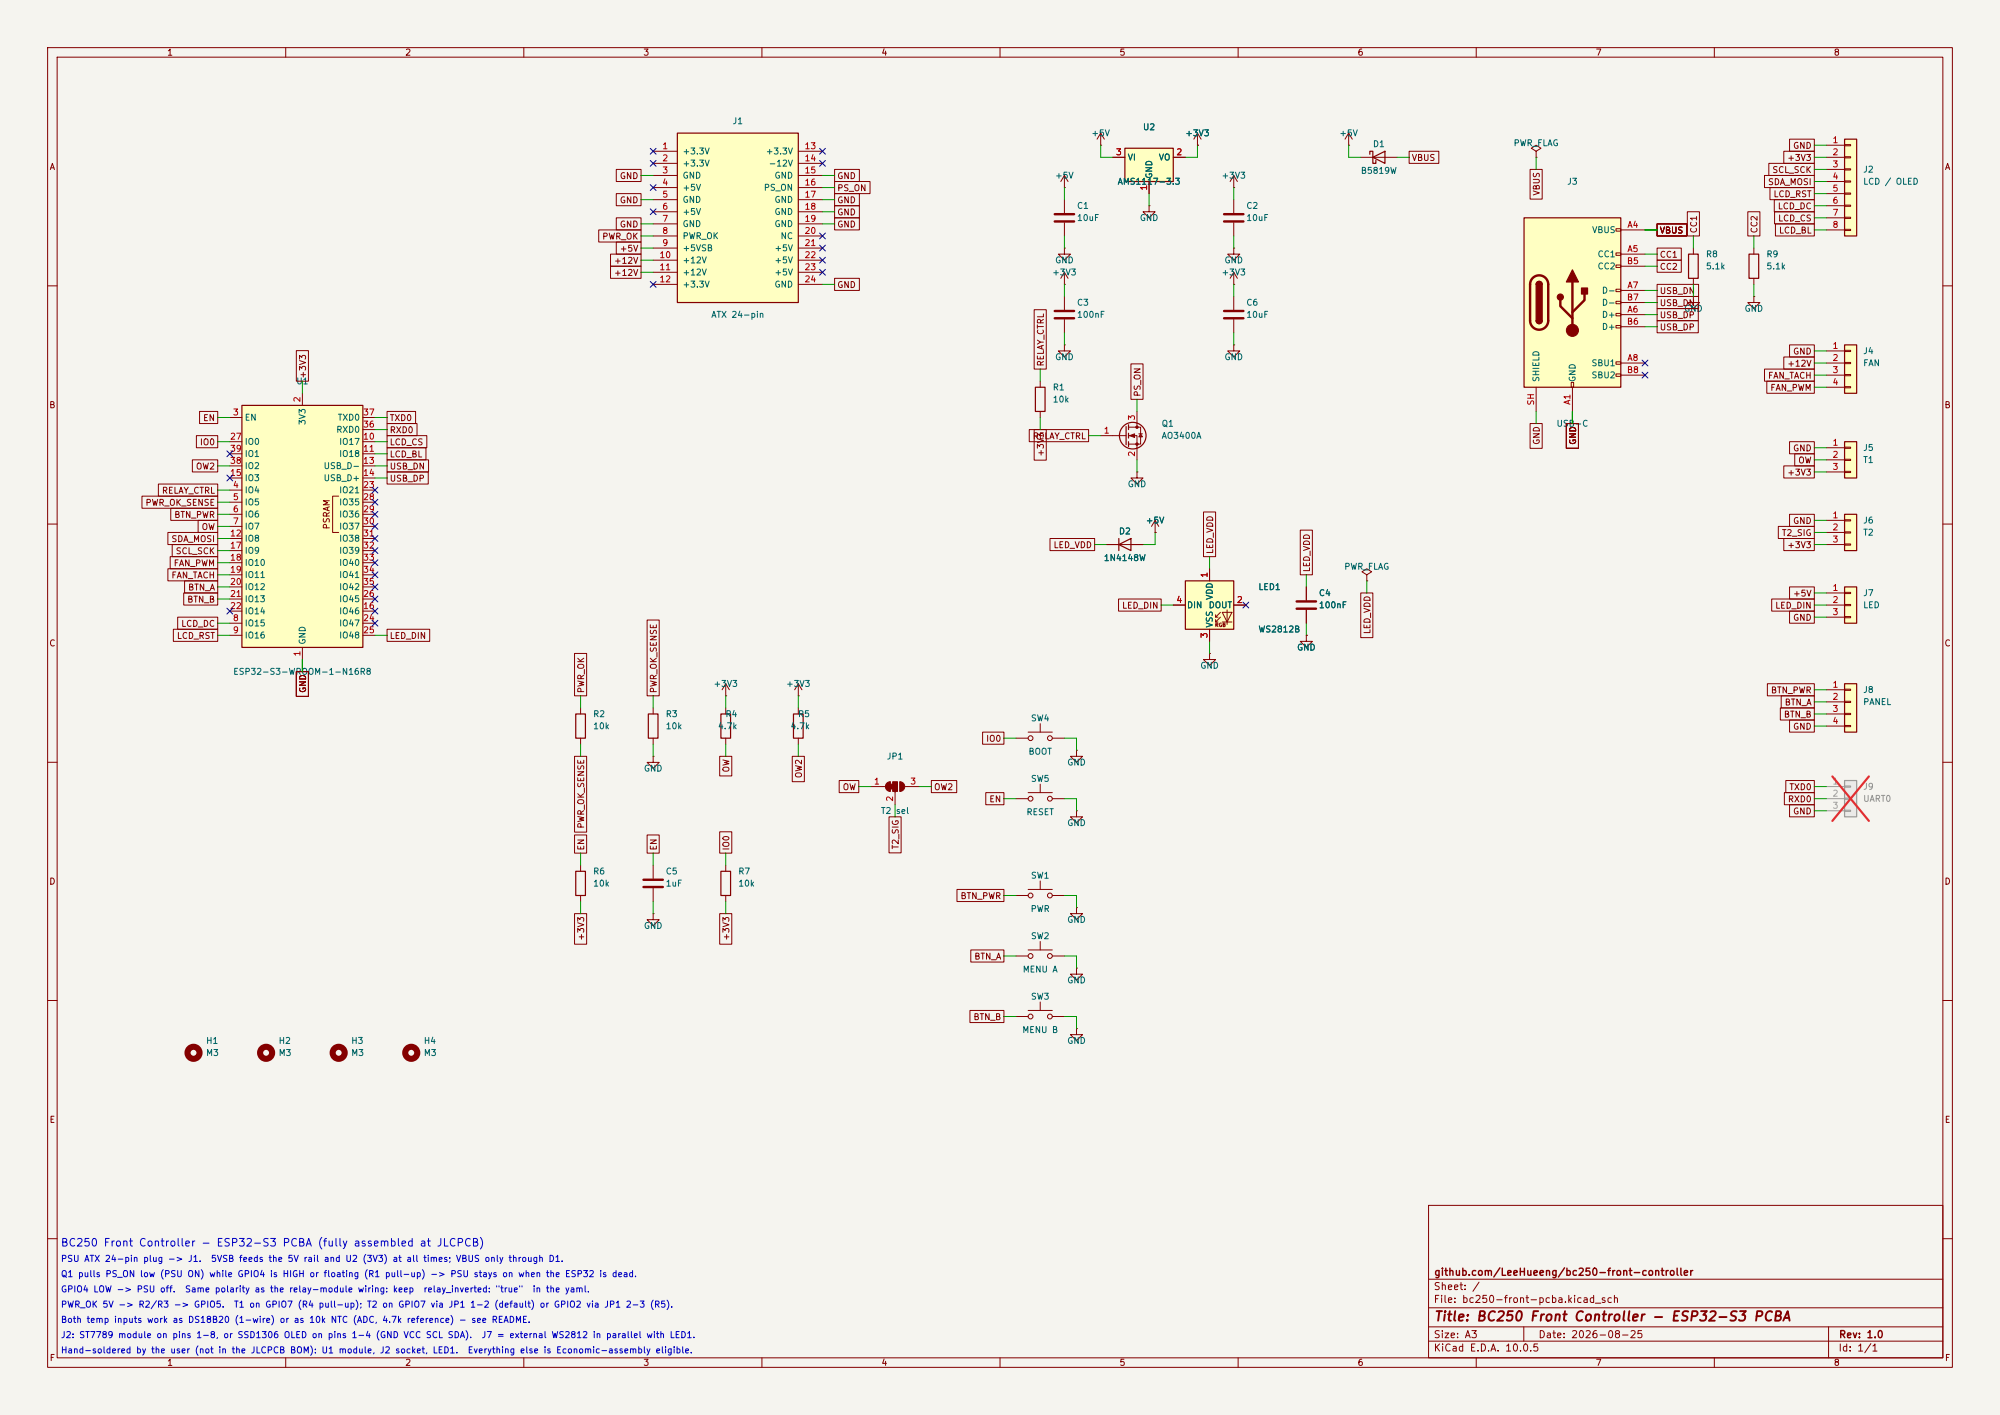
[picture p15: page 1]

github.com/LeeHueeng/bc250-front-controller
Sheet: /
File: bc250-front-pcba.kicad_sch
Title: BC250 Front Controller - ESP32-S3 PCBA

Size: A3 | Rev: 1.0 | F Date: 2026-08-25
KiCad E.D.A. 10.0.5 | Id: 1/1

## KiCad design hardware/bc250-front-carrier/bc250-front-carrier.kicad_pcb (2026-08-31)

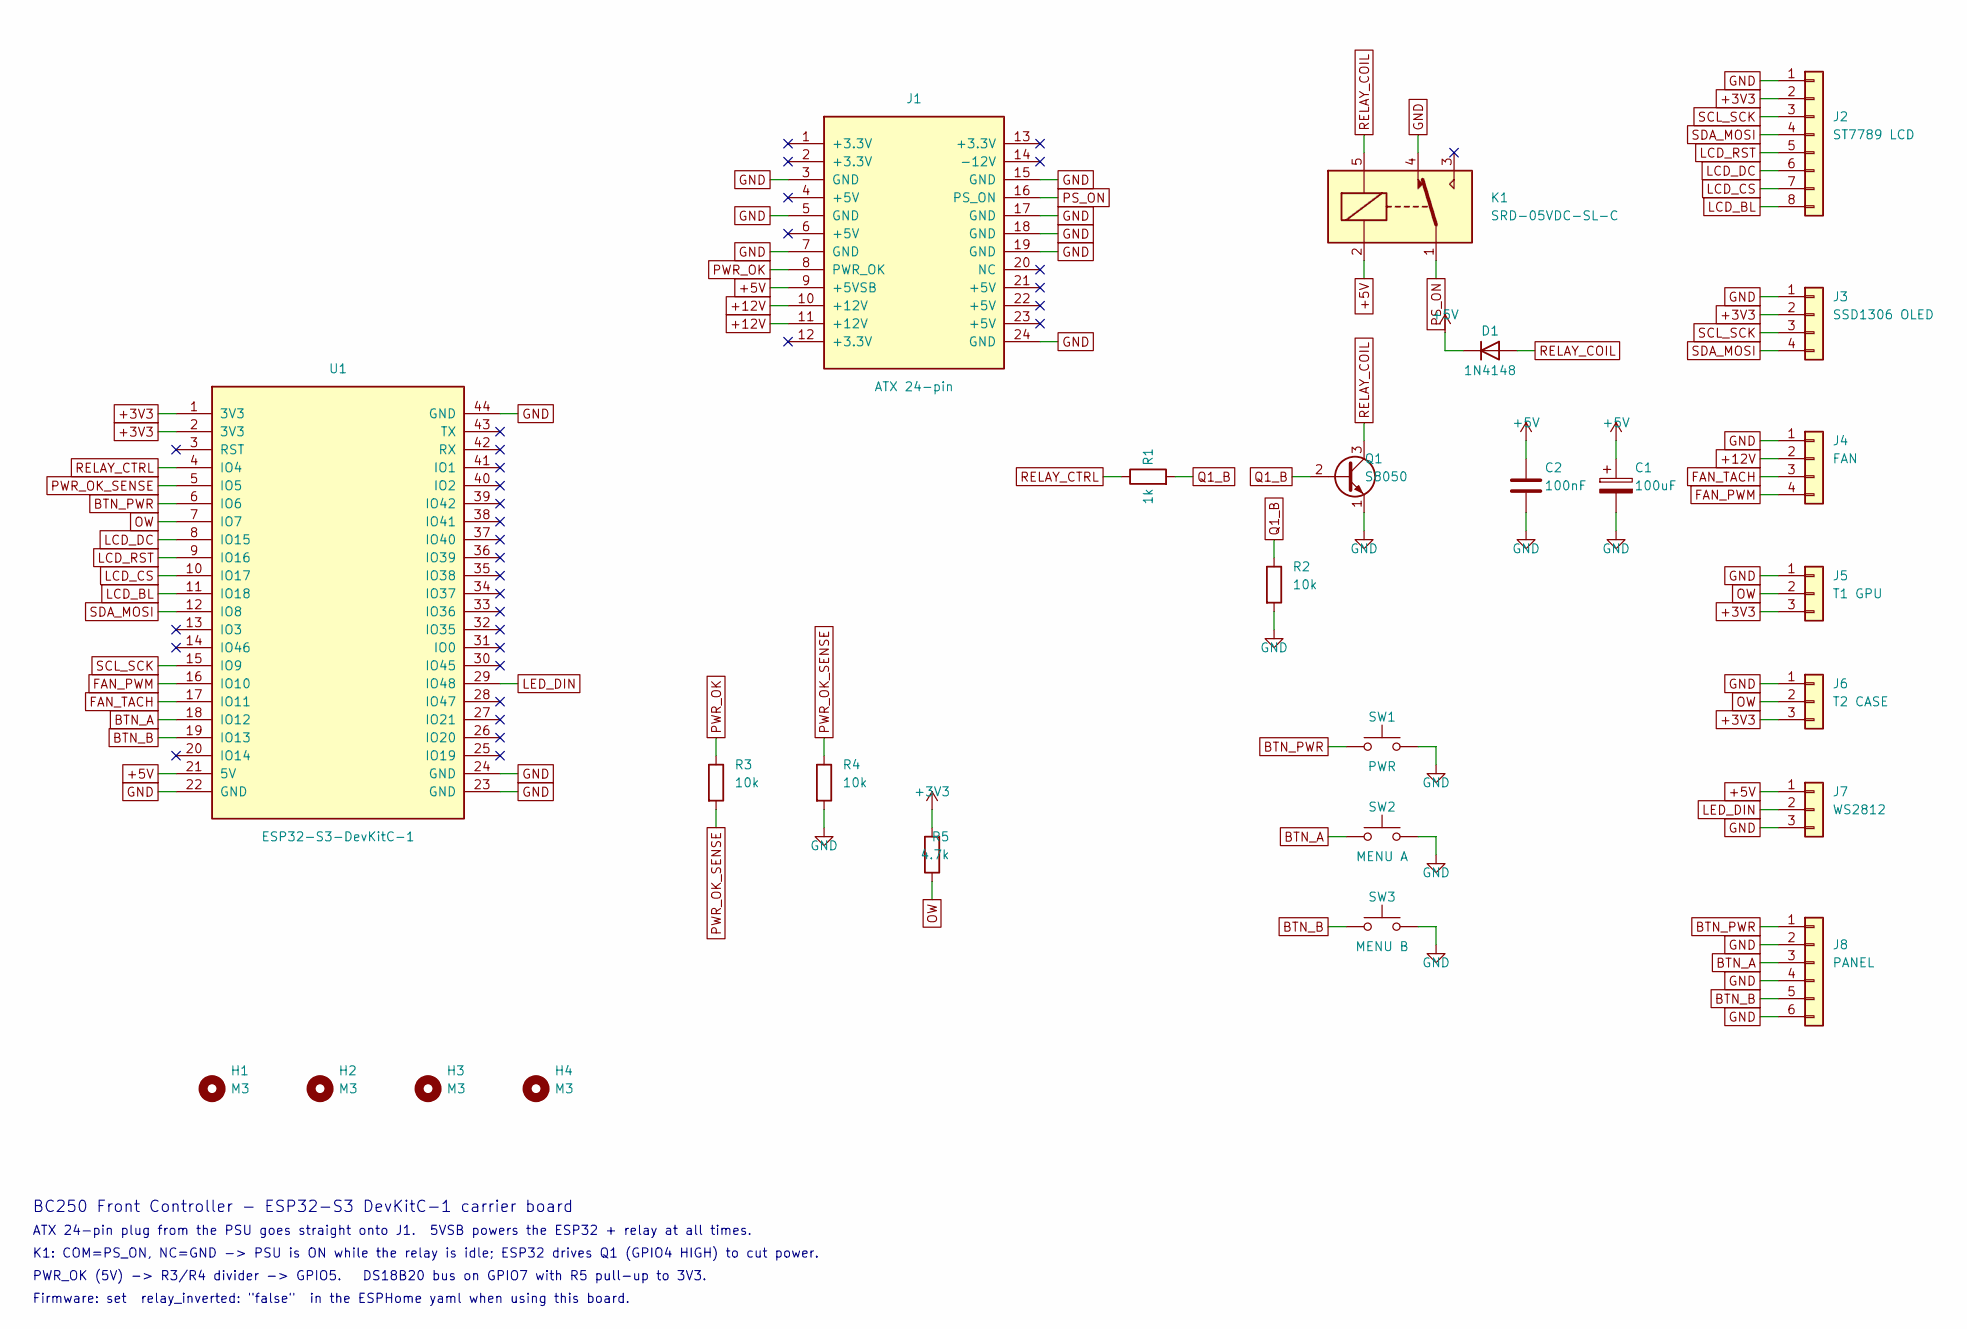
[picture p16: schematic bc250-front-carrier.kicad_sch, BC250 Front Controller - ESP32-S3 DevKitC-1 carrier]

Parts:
C1: 100uF; CP_Radial_D5.0mm_P2.00mm
C2: 100nF; C_Disc_D5.0mm_W2.5mm_P2.50mm
D1: 1N4148; D_DO-35_SOD27_P7.62mm_Horizontal
H1, H2, H3, H4: M3; MountingHole_3.2mm_M3
J1: ATX 24-pin; Molex_Mini-Fit_Jr_5566-24A_2x12_P4.20mm_Vertical
J2: ST7789 LCD; PinSocket_1x08_P2.54mm_Vertical
J3: SSD1306 OLED; PinSocket_1x04_P2.54mm_Vertical
J4: FAN; PinHeader_1x04_P2.54mm_Vertical
J5: T1 GPU; PinHeader_1x03_P2.54mm_Vertical
J6: T2 CASE; PinHeader_1x03_P2.54mm_Vertical
J7: WS2812; PinHeader_1x03_P2.54mm_Vertical
J8: PANEL; PinHeader_1x06_P2.54mm_Vertical
K1: SRD-05VDC-SL-C; Relay_SPDT_SANYOU_SRD_Series_Form_C
Q1: S8050; TO-92_Inline
R1: 1k; R_Axial_DIN0207_L6.3mm_D2.5mm_P7.62mm_Horizontal
R2, R3, R4: 10k; R_Axial_DIN0207_L6.3mm_D2.5mm_P7.62mm_Horizontal
R5: 4.7k; R_Axial_DIN0207_L6.3mm_D2.5mm_P7.62mm_Horizontal
SW1: PWR; SW_PUSH_6mm
SW2: MENU A; SW_PUSH_6mm
SW3: MENU B; SW_PUSH_6mm
U1: ESP32-S3-DevKitC-1; ESP32-S3-DevKitC-1_Socket

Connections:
+3V3: J2.2, J3.2, J5.3, J6.3, R5.2, U1.1 (3V3), U1.2 (3V3)
+5V: C1.1, C2.1, D1.1 (K), J1.9 (+5VSB), J7.1, K1.2, U1.21 (5V)
+12V: J1.10 (+12V), J1.11 (+12V), J4.2
BTN_A: J8.3, SW2.1, U1.18 (IO12)
BTN_B: J8.5, SW3.1, U1.19 (IO13)
BTN_PWR: J8.1, SW1.1, U1.6 (IO6)
FAN_PWM: J4.4, U1.16 (IO10)
FAN_TACH: J4.3, U1.17 (IO11)
GND: C1.2, C2.2, J1.3 (GND), J1.5 (GND), J1.7 (GND), J1.15 (GND), J1.17 (GND), J1.18 (GND), J1.19 (GND), J1.24 (GND), J2.1, J3.1, J4.1, J5.1, J6.1, J7.3, J8.2, J8.4, J8.6, K1.4, Q1.1 (E), R2.2, R4.2, SW1.2, SW2.2, SW3.2, U1.22 (GND), U1.23 (GND), U1.24 (GND), U1.44 (GND)
LCD_BL: J2.8, U1.11 (IO18)
LCD_CS: J2.7, U1.10 (IO17)
LCD_DC: J2.6, U1.8 (IO15)
LCD_RST: J2.5, U1.9 (IO16)
LED_DIN: J7.2, U1.29 (IO48)
OW: J5.2, J6.2, R5.1, U1.7 (IO7)
PS_ON: J1.16 (PS_ON), K1.1
PWR_OK: J1.8 (PWR_OK), R3.1
PWR_OK_SENSE: R3.2, R4.1, U1.5 (IO5)
Q1_B: Q1.2 (B), R1.2, R2.1
RELAY_COIL: D1.2 (A), K1.5, Q1.3 (C)
RELAY_CTRL: R1.1, U1.4 (IO4)
SCL_SCK: J2.3, J3.3, U1.15 (IO9)
SDA_MOSI: J2.4, J3.4, U1.12 (IO8)

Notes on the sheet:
BC250 Front Controller - ESP32-S3 DevKitC-1 carrier board
ATX 24-pin plug from the PSU goes straight onto J1. 5VSB powers the ESP32 + relay at all times.
K1: COM=PS_ON, NC=GND -> PSU is ON while the relay is idle; ESP32 drives Q1 (GPIO4 HIGH) to cut power.
PWR_OK (5V) -> R3/R4 divider -> GPIO5. DS18B20 bus on GPIO7 with R5 pull-up to 3V3.
Firmware: set relay_inverted: "false" in the ESPHome yaml when using this board.

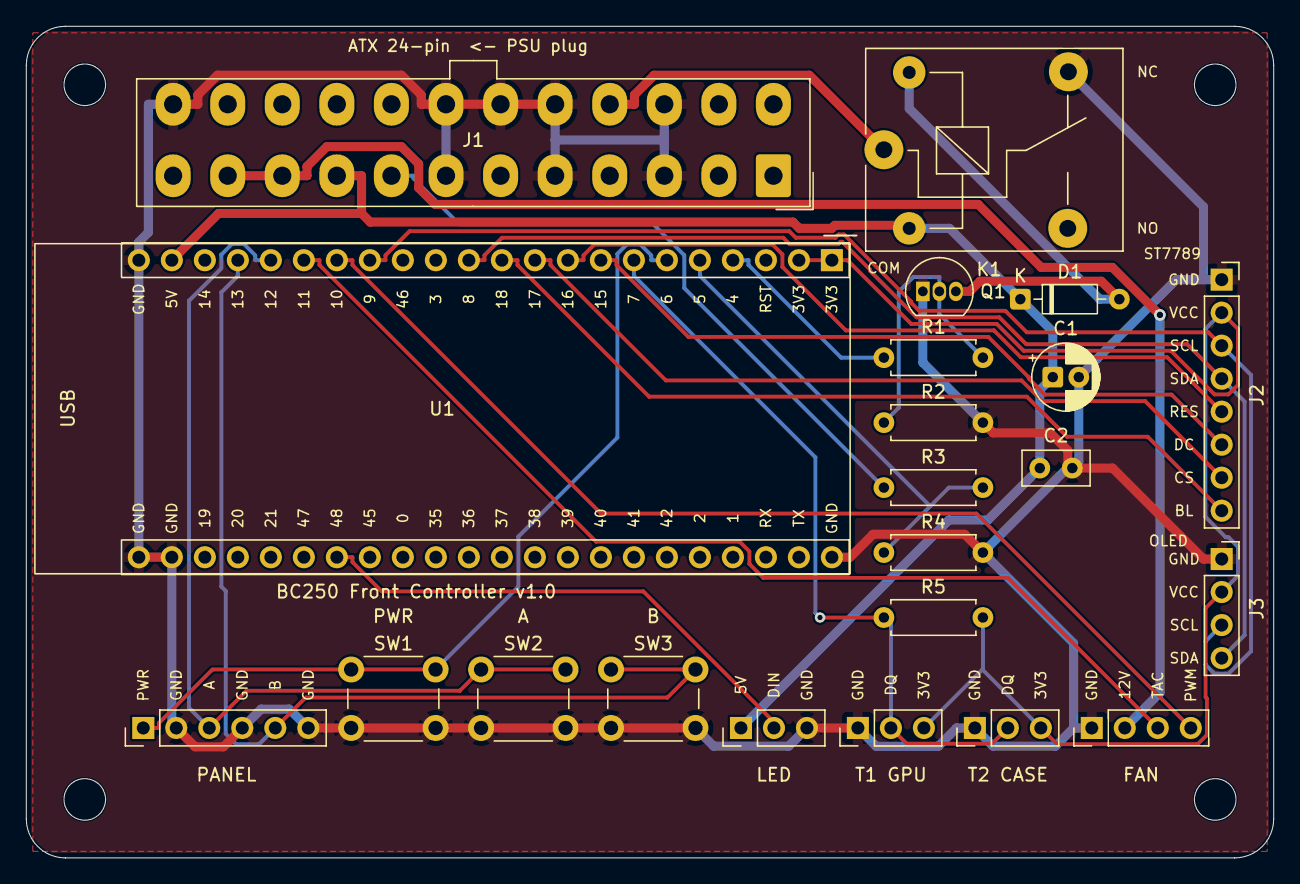
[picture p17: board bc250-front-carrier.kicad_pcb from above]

Board: 2 copper layers, 96.0 x 64.0 mm, 26 parts (0 on the bottom side), 23 nets.

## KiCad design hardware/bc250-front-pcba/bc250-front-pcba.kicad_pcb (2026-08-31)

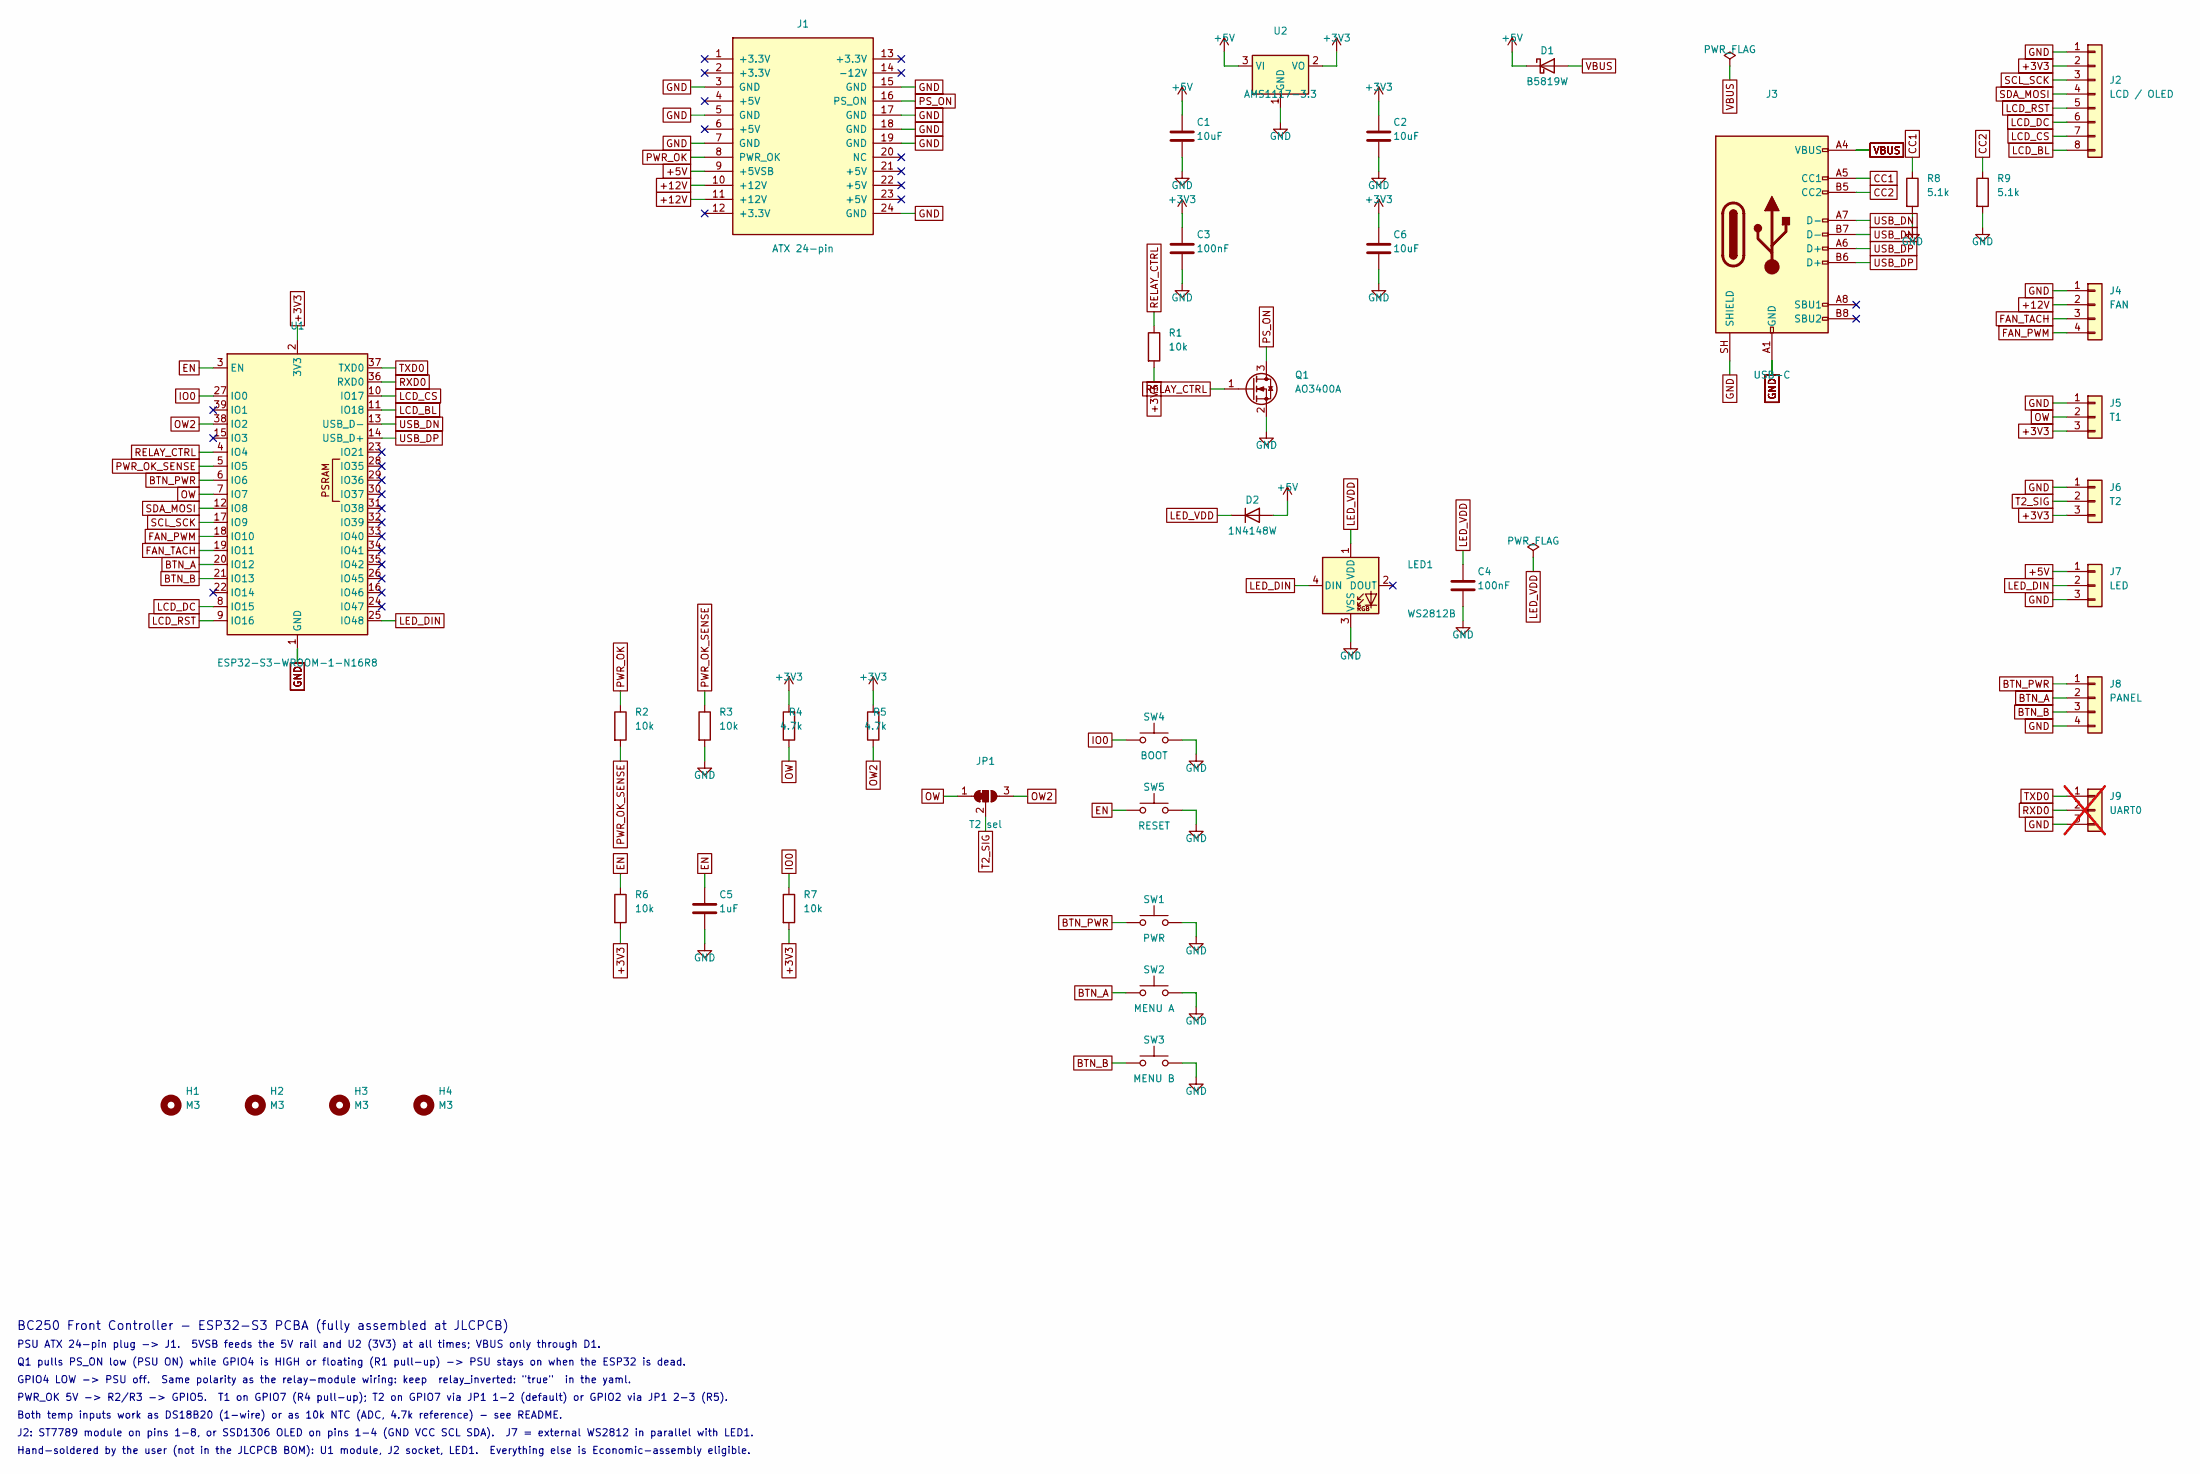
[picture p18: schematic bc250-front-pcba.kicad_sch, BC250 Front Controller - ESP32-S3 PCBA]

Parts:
C1, C2, C6: 10uF; C_0805_2012Metric
C3, C4: 100nF; C_0603_1608Metric
C5: 1uF; C_0603_1608Metric
D1: B5819W; D_SOD-123
D2: 1N4148W; D_SOD-123
H1, H2, H3, H4: M3; MountingHole_3.2mm_M3
J1: ATX 24-pin; Molex_Mini-Fit_Jr_5566-24A_2x12_P4.20mm_Vertical
J2: LCD / OLED; PinSocket_1x08_P2.54mm_Vertical
J3: USB-C; USB_C_Receptacle_HRO_TYPE-C-31-M-12
J4: FAN; PinHeader_1x04_P2.54mm_Vertical
J5: T1; PinHeader_1x03_P2.54mm_Vertical
J6: T2; PinHeader_1x03_P2.54mm_Vertical
J7: LED; PinHeader_1x03_P2.54mm_Vertical
J8: PANEL; PinHeader_1x04_P2.54mm_Vertical
J9: UART0; PinHeader_1x03_P2.54mm_Vertical; not fitted
JP1: T2 sel; SolderJumper-3_P1.3mm_Bridged12_Pad1.0x1.5mm
LED1: WS2812B; LED_WS2812B_PLCC4_5.0x5.0mm_P3.2mm
Q1: AO3400A; SOT-23
R1, R2, R3, R6, R7: 10k; R_0603_1608Metric
R4, R5: 4.7k; R_0603_1608Metric
R8, R9: 5.1k; R_0603_1608Metric
SW1: PWR; SW_TS-1187A
SW2: MENU A; SW_TS-1187A
SW3: MENU B; SW_TS-1187A
SW4: BOOT; SW_TS-1187A
SW5: RESET; SW_TS-1187A
U1: ESP32-S3-WROOM-1-N16R8; ESP32-S3-WROOM-1_edge
U2: AMS1117-3.3; SOT-223-3_TabPin2

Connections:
+3V3: C2.1, C3.1, C6.1, J2.2, J5.3, J6.3, R1.2, R4.2, R5.2, R6.2, R7.2, U1.2 (3V3), U2.2 (VO)
+5V: C1.1, D1.1 (K), D2.2 (A), J1.9 (+5VSB), J7.1, U2.3 (VI)
+12V: J1.10 (+12V), J1.11 (+12V), J4.2
BTN_A: J8.2, SW2.1, U1.20 (IO12)
BTN_B: J8.3, SW3.1, U1.21 (IO13)
BTN_PWR: J8.1, SW1.1, U1.6 (IO6)
CC1: J3.A5 (CC1), R8.1
CC2: J3.B5 (CC2), R9.1
EN: C5.1, R6.1, SW5.1, U1.3 (EN)
FAN_PWM: J4.4, U1.18 (IO10)
FAN_TACH: J4.3, U1.19 (IO11)
GND: C1.2, C2.2, C3.2, C4.2, C5.2, C6.2, J1.3 (GND), J1.5 (GND), J1.7 (GND), J1.15 (GND), J1.17 (GND), J1.18 (GND), J1.19 (GND), J1.24 (GND), J2.1, J3.A1 (GND), J3.A12 (GND), J3.B1 (GND), J3.B12 (GND), J3.SH (SHIELD), J4.1, J5.1, J6.1, J7.3, J8.4, J9.3, LED1.3 (VSS), Q1.2 (S), R3.2, R8.2, R9.2, SW1.2, SW2.2, SW3.2, SW4.2, SW5.2, U1.1 (GND), U1.40 (GND), U1.41 (GND), U2.1 (GND)
IO0: R7.1, SW4.1, U1.27 (IO0)
LCD_BL: J2.8, U1.11 (IO18)
LCD_CS: J2.7, U1.10 (IO17)
LCD_DC: J2.6, U1.8 (IO15)
LCD_RST: J2.5, U1.9 (IO16)
LED_DIN: J7.2, LED1.4 (DIN), U1.25 (IO48)
LED_VDD: C4.1, D2.1 (K), LED1.1 (VDD)
OW: J5.2, JP1.1 (A), R4.1, U1.7 (IO7)
OW2: JP1.3 (B), R5.1, U1.38 (IO2)
PS_ON: J1.16 (PS_ON), Q1.3 (D)
PWR_OK: J1.8 (PWR_OK), R2.1
PWR_OK_SENSE: R2.2, R3.1, U1.5 (IO5)
RELAY_CTRL: Q1.1 (G), R1.1, U1.4 (IO4)
RXD0: J9.2, U1.36 (RXD0)
SCL_SCK: J2.3, U1.17 (IO9)
SDA_MOSI: J2.4, U1.12 (IO8)
T2_SIG: J6.2, JP1.2 (C)
TXD0: J9.1, U1.37 (TXD0)
USB_DN: J3.A7 (D-), J3.B7 (D-), U1.13 (USB_D-)
USB_DP: J3.A6 (D+), J3.B6 (D+), U1.14 (USB_D+)
VBUS: D1.2 (A), J3.A4 (VBUS), J3.A9 (VBUS), J3.B4 (VBUS), J3.B9 (VBUS)

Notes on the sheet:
BC250 Front Controller - ESP32-S3 PCBA (fully assembled at JLCPCB)
PSU ATX 24-pin plug -> J1. 5VSB feeds the 5V rail and U2 (3V3) at all times; VBUS only through D1.
Q1 pulls PS_ON low (PSU ON) while GPIO4 is HIGH or floating (R1 pull-up) -> PSU stays on when the ESP32 is dead.
GPIO4 LOW -> PSU off. Same polarity as the relay-module wiring: keep relay_inverted: "true" in the yaml.
PWR_OK 5V -> R2/R3 -> GPIO5. T1 on GPIO7 (R4 pull-up); T2 on GPIO7 via JP1 1-2 (default) or GPIO2 via JP1 2-3 (R5).
Both temp inputs work as DS18B20 (1-wire) or as 10k NTC (ADC, 4.7k reference) - see README.
J2: ST7789 module on pins 1-8, or SSD1306 OLED on pins 1-4 (GND VCC SCL SDA). J7 = external WS2812 in parallel with LED1.
Hand-soldered by the user (not in the JLCPCB BOM): U1 module, J2 socket, LED1. Everything else is Economic-assembly eligible.

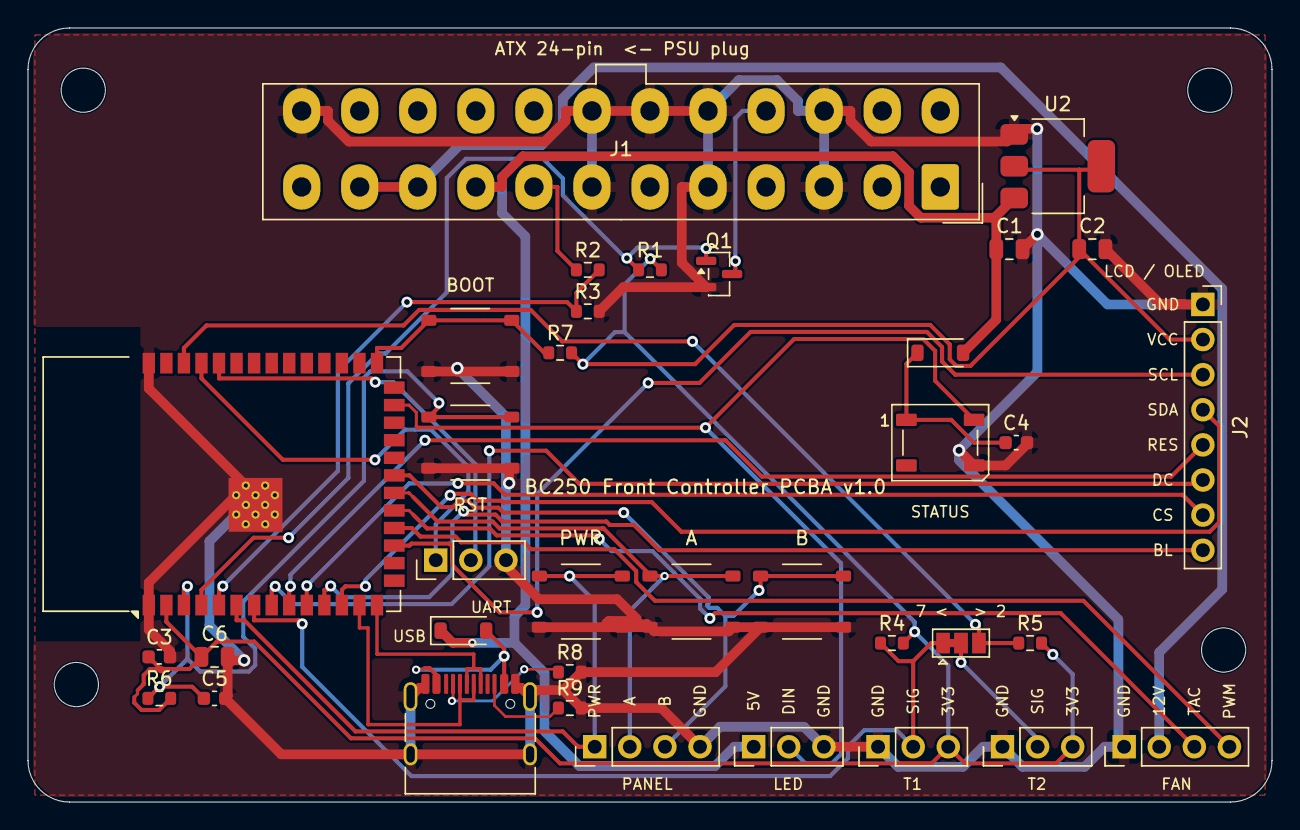
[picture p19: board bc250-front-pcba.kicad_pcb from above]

Board: 2 copper layers, 90.0 x 56.0 mm, 40 parts (0 on the bottom side), 33 nets.

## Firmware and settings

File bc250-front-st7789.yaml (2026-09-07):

# BC250 Front Controller — ST7789V 240×320 SPI 디스플레이 에디션 (풀옵션)
#
# bc250-front.yaml 의 OLED(SSD1306 I2C)를 ST7789V 2.4인치 240×320 컬러 SPI 디스플레이로
# 교체한 버전. 기존 기능(릴레이 전원 제어·정상 종료·팬 커브·DS18B20·버튼·HA·웹·OTA)은 그대로.
#
# ── 핀맵 (ESP32-S3, 기존 대비 변경분) ─────────────────────────────────────────────
#  GPIO8  SPI MOSI (기존 I2C SDA → SPI로 전환)
#  GPIO9  SPI SCLK (기존 I2C SCL → SPI로 전환)
#  GPIO17 SPI CS
#  GPIO15 SPI DC (data/command)
#  GPIO16 SPI RST
#  GPIO18 BL 백라이트 (PWM 밝기 제어, ledc)
#
# ── 핀맵 (기존 그대로) ─────────────────────────────────────────────────────────────
#  GPIO4  릴레이 IN            GPIO10 팬 PWM 출력 (25kHz)
#  GPIO5  PWR_OK 감지(분압)     GPIO11 팬 타코 입력
#  GPIO6  전원 버튼(GND로)      GPIO12 메뉴 버튼A (다음 화면 / 다음 항목 / 값 올리기 +)
#  GPIO7  DS18B20 원와이어      GPIO13 메뉴 버튼B (선택·확정)
#  GPIO48 WS2812 상태 LED       GPIO14 메뉴 버튼C (이전 화면 / 이전 항목 / 값 내리기 −)  ← 2026-08-31 추가
#
# ── 2026-08-31 변경 ──────────────────────────────────────────────────────────────
#  · 5V 투입(콜드 부팅) 때 RST를 눌러야 화면이 나오던 문제: 디스플레이 초기화 전에 LCD RST를
#    1초간 LOW로 잡아 두었다가(전원 안정 대기 겸) 해제 후 200ms 뒤 초기화 (esphome.on_boot + output lcd_rst)
#  · 주의: ESP32-S3 네이티브 USB 포트를 PC(맥)에 꽂아 두면 PC가 포트를 여는 순간 칩이 다운로드 모드로
#    리셋될 수 있음(rst:0x15, boot:0x0 DOWNLOAD) → 화면·WiFi 전부 죽은 것처럼 보임. 펌웨어로 못 막음.
#    평상시엔 PC 케이블을 빼고, 로그가 필요하면 UART(CH343) 포트를 쓸 것.
#  · 전원 버튼 강제 종료: 5초 → 3초 (누르고 있으면 3초 되는 순간 실행, 놓는 타이밍 무관)
#  · 메뉴 버튼 C(GPIO14) 추가: 이전 항목 / 값 내리기. A·C 길게 누르면 0.2초마다 자동 반복
#  · 보안: API 암호화 키·OTA 비밀번호·웹 로그인 → secrets.yaml (secrets.yaml.example 참고, git 미포함)
#  · 과열 위험(경고 온도 +10°C 가 60초 지속) → 자동 정상 종료, 실패하면 강제 전원 컷
#  · 백라이트 자동 어둡게: 서버 꺼짐 / 밤 시간(SNTP 시계 맞을 때만). 버튼 누르면 30초간 원래 밝기
#  · 컨트롤러 초기화: 설정값만 초기화(WiFi 유지) / 공장 초기화(WiFi·설정 전부 지우고 재부팅) — 메뉴·웹·HA
#
# ── 2026-09-01 변경 ──────────────────────────────────────────────────────────────
#  · 화면 깨짐 자동 복구(script lcd_heal): LCD 컨트롤러의 핵심 레지스터(절전 해제·표시 모드·색 반전·주소 방향·
#    픽셀 포맷·표시 ON)를 다시 써 주고 프레임을 다시 그린다. 버튼 조작 1초 뒤 · 60초마다 · 부팅 10/30초 뒤 자동.
#    정상일 땐 아무 변화 없음. 노이즈로 명령 한 바이트가 잘못 들어가 색 반전·밀림·백지·꺼짐이 된 화면을 되살린다.
#    (전체 프레임을 매번 다시 쓰는 드라이버라 픽셀 데이터 오류는 원래 다음 프레임에 지워지지만, 명령 레지스터가
#     바뀌면 영구히 깨진 채 남았음 → 이 복구가 그걸 메꾼다)
#  · 화면 하드 복구(script lcd_reset): RST 핀으로 LCD를 완전히 리셋하고 초기화 시퀀스 전체를 다시 보냄 —
#    메뉴 "화면 복구" / 웹·HA "화면 복구" 버튼. 약 0.4초 화면이 꺼졌다 켜진다.
#    → 이를 위해 GPIO15(DC)도 output.lcd_dc 로 공유(allow_other_uses), GPIO16(RST)은 이미 공유 중.
#  · 화면 갱신 1초 → 2초: 한 프레임(240×320×16bit=153KB) 쓰는 데 약 140ms 동안 메인 루프가 멈춰(버튼 반응
#    지연·짧은 누름이 길게 잡히는 원인) 절반으로 줄임. 값들은 어차피 5초마다 갱신. 버튼 조작은 즉시 갱신.
#  · SPI 클럭 substitutions lcd_data_rate 로 노출(기본 20MHz). 점퍼선이 길어 계속 깨지면 10MHz 로 낮춰 볼 것.
#  · 전원 투입 자동 부팅: 릴레이 restore_mode 를 ALWAYS_OFF(=서버 ON)로 바꾸고, 서버 꺼짐 상태 복원은
#    "소프트 재부팅(OTA·재시작 버튼·안전 모드)일 때만" on_boot(700)에서 직접 한다(globals server_was_off).
#    → 5VSB/AC를 뽑았다 꽂으면(콜드 부팅, rst POWERON) 마지막 상태가 꺼짐이었어도 서버가 자동으로 켜진다.
#    예전엔 RESTORE_DEFAULT_OFF 라서 "끈 채로 뽑았다 꽂으면 꺼진 채" 였음. substitutions power_on_boot 로 끔.
#
# ── 2026-09-01 (2차) 개선 ────────────────────────────────────────────────────────
#  · 종료 요청 실패가 "유지"됨: shutdown_failed 전역 → LED 빨강 + 화면 하단 "SHUTDOWN REQUEST FAILED / HOLD POWER 3S"
#    가 다음 전원 조작까지 남는다 (예전엔 5초 interval 이 LED 를 초록으로 덮어써 실패를 알 수 없었음)
#  · 종료 진행 표시: 하단 바 "SENDING SHUTDOWN" → "SHUTTING DOWN 43s" 카운트다운(shutdown_deadline). 대기가 끝났는데
#    에이전트(/health)가 아직 응답하면 OS 가 안 꺼진 것 → 한 번 더 기다린 뒤 컷 (최대 2배)
#  · 강제 컷/웹 OFF 가 종료 대기 중이면 스크립트를 끊는다 (turn_off_action 에서 script.stop)
#  · 과열 위험(overheat_critical)이 안 풀렸으면 전원 켜기 거부 (turn_on_action)
#  · "PSU 이상" 센서: 릴레이 ON 인데 PWR_OK 가 10초 넘게 안 오면 → 빨강 + 하단 "PSU NOT OK". 하단 아이콘 FAN/TEMP/PSU/NET
#  · HA 노출: "종료 진행 중", "종료 실패", "PSU 이상" binary_sensor
#  · BC250 종료 에이전트 동봉(bc250-agent/): POST /shutdown (X-Token 헤더) · GET /health. 가이드 11장. 토큰은 secrets.yaml
#    bc250_agent_token. 주소는 substitutions bc250_host / bc250_agent_port (예전 192.168.0.50 은 다른 서브넷이라 항상 실패했음)
#  · http_request timeout 5s → 3s (에이전트가 없을 때 화면·버튼이 멈추는 시간)
#  · 설정용 AP 에 비밀번호(secrets ap_password) — 예전엔 누구나 붙어서 캡티브 포털로 WiFi 를 바꿀 수 있었음
#  · 웹 대시보드 인증 basic → digest (ESPHome 2027.1 기본값 선반영, LAN 에 비밀번호 평문 안 흐름)
#  · 화면 밝기를 웹/HA 에서 바꿔도 30초 동안 자동 어둡게가 덮어쓰지 않음 (on_value 에서 last_input 갱신)
#  · 네트워크 화면: 오프라인이면 설정 AP 이름·192.168.4.1 안내. 팬은 속도가 바뀔 때만 HA 로 전송
#  · (남김) 부팅 로그의 [W][ledc.output] Not yet initialized — 밝기 number 복원이 ledc 초기화보다 먼저라 나는 무해한 경고
#  · PSU 실제 켜짐(GPIO5): 디지털 입력 → ADC 전압 판정으로 교체. 10k+10k 분압 2.5V 는 ESP32-S3 VIH(2.475V) 경계라
#    디지털로는 애매하고, 선이 안 물려 떠 있어도 ON 으로 읽힐 수 있었음. 이제 1.5V 넘으면 ON, 1.0V 아래면 OFF (히스테리시스),
#    실제 전압은 센서 "PWR_OK 전압"으로 웹/HA 에 보임 → 배선 확인용. 분압 저항은 그대로.
#  · 팬 표시: 서버(=PSU 12V)가 꺼져 있으면 팬 엔티티를 OFF 로 두고 화면에 "OFF / NO 12V" — 예전엔 PWM 명령값(20%)을
#    그대로 보여줘 안 도는 팬이 도는 것처럼 보였음. "팬 속도" 센서도 팬 OFF 면 0. 서버 켜짐인데 RPM 0 이면(팬 이상) 빨강.
#
# ── 2026-09-07 ──────────────────────────────────────────────────────────────────
#  · "컨트롤러 칩 온도" 센서(internal_temperature): ESP32-S3 내부 온도를 웹/HA 에 노출. 기판이 뜨끈할 때 정상 범위인지
#    숫자로 확인용 — WiFi 절전 OFF·240MHz 상시라 실내에서 45~65°C 는 정상, 80°C 넘으면 통풍·전원 확인.
#  · (기록) 9/7 보드에 HA 쪽 ESPHome 2025.2.2 로 빌드한 8/31 커밋본이 올라가 있었음 → 화면 1초 갱신(루프 30% 블로킹)·
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

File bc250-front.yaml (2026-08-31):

# BC250 Front Controller — ESP32-S3 (풀옵션)
# 스펙 대비 조정된 부분:
#  - BC-250에는 전원 버튼이 없다 → 릴레이는 "버튼 누르기(300ms)"가 아니라
#    ATX PS_ON을 잡고 있는 유지(hold) 방식. NC 접점 배선이라 ESP 재부팅에도 서버 안 꺼짐.
#  - "정상 종료"는 ESP32가 주체: HTTP로 BC-250에 종료 명령 → 대기 → 전원 컷 (HA 불필요).
#
# 핀맵 (ESP32-S3):
#  GPIO4  릴레이 IN            GPIO9  I2C SCL (OLED)
#  GPIO5  PWR_OK 감지(분압)     GPIO10 팬 PWM 출력
#  GPIO6  전원 버튼(GND로)      GPIO11 팬 타코 입력
#  GPIO7  DS18B20 원와이어      GPIO12 메뉴 버튼A(이동, GND로)
#  GPIO8  I2C SDA (OLED)       GPIO13 메뉴 버튼B(선택, GND로)
#  GPIO48 WS2812 상태 LED (외장이면 핀 변경)
#
# 로컬 설정 메뉴 (OLED + 버튼 2개, 값은 플래시에 저장):
#  A 짧게: 아래 이동 / (메뉴 꺼져 있으면) 메뉴 열기     A 길게: 위 이동
#  B 짧게: 선택·편집 진입/확정                        B 길게: 메뉴 닫기

substitutions:
  # BC-250 OS 세팅 후 실제 IP·포트로 교체 (BC-250 쪽 shutdown 에이전트는 OS 설치 때 만듦)
  bc250_shutdown_url: "http://192.168.0.50:8420/shutdown"
  # 릴레이 구동 극성 — 시판 릴레이 모듈(옵토커플러, active-low)이면 "true",
  # 캐리어 PCB(hardware/bc250-front-carrier, NPN 직결 active-high)면 "false"
  relay_inverted: "true"
  # 로그 출력 UART — DevKitC-1(CH343 USB-시리얼)은 UART0,
  # PCBA 보드(hardware/bc250-front-pcba, 네이티브 USB-C)는 USB_SERIAL_JTAG
  log_uart: UART0

esphome:
  name: bc250-front
  friendly_name: BC250 컨트롤러

esp32:
  board: esp32-s3-devkitc-1
  framework:
    type: esp-idf

logger:
  hardware_uart: ${log_uart}   # DevKit=UART0 / PCBA=USB_SERIAL_JTAG (substitutions 참고)
api:            # HA 직결 (자동 발견·이벤트·서비스) — 없어도 동작에 지장 없음
  reboot_timeout: 0s
ota:
  platform: esphome
web_server:     # 웹 대시보드 — http://bc250-front.local
  version: 3

# MQTT가 꼭 필요하면 주석 해제 (HA만 쓸 거면 api로 충분)
# mqtt:
#   broker: !secret mqtt_broker

# WiFi 자격증명은 펌웨어에 없음 — 첫 부팅 시 ESP가 AP("bc250-front-setup")를 열고,
# 폰/노트북으로 접속하면 설정 페이지가 떠서 집 WiFi를 고르고 비번 입력 → 플래시에 저장.
wifi:
  reboot_timeout: 0s   # WiFi 끊겨도 재부팅 금지 — 로컬 제어(버튼·팬커브·OLED)는 계속 동작
  ap:
    ssid: "bc250-front-setup"   # 접속 실패 1분 후 자동으로 설정용 AP 다시 열림
captive_portal:
improv_serial:   # USB로도 설정 가능 (web.esphome.io)

i2c:
  sda: GPIO8
  scl: GPIO9

one_wire:
  - platform: gpio
    pin: GPIO7

globals:
  - id: shutting_down
    type: bool
    initial_value: "false"

http_request:
  timeout: 5s
  verify_ssl: false

# 정상 종료 시퀀스 — ESP32가 주체. HA 없이도 완결된다.
script:
  - id: graceful_shutdown
    mode: single
    then:
      - globals.set: {id: shutting_down, value: "true"}
      - http_request.post:
          url: ${bc250_shutdown_url}
      - delay: !lambda "return (uint32_t) id(shutdown_wait).state * 1000;"
      - switch.turn_off: server_power
      - globals.set: {id: shutting_down, value: "false"}

button:
  - platform: template
    name: "정상 종료"
    icon: mdi:power-cycle
    on_press: [script.execute: graceful_shutdown]
  - platform: restart
    id: restart_btn
    name: "컨트롤러 재시작"

# ─── 로컬 설정값 (메뉴·웹·HA 어디서 바꿔도 플래시에 저장) ───
select:
  - platform: template
    id: fan_mode
    name: "팬 모드"
    options: ["자동", "수동"]
    initial_option: "자동"
    restore_value: true
    optimistic: true
  - platform: template
    id: fan_preset
    name: "팬 프리셋"
    options: ["조용히", "표준", "성능"]
    initial_option: "표준"
    restore_value: true
    optimistic: true

number:
  - platform: template
    id: manual_speed
    name: "수동 팬 속도"
    min_value: 0
    max_value: 100
    step: 5
    initial_value: 50
    restore_value: true
    optimistic: true
    unit_of_measurement: "%"
  - platform: template
    id: oled_brightness
    name: "OLED 밝기"
    min_value: 10
    max_value: 100
    step: 10
    initial_value: 80
    restore_value: true
    optimistic: true
    unit_of_measurement: "%"
    on_value:
      - lambda: 'id(oled).set_contrast(x / 100.0f);'
  - platform: template
    id: overheat_temp
    name: "과열 경고 온도 C"
    min_value: 70
    max_value: 95
    step: 1
    initial_value: 85
    restore_value: true
    optimistic: true
    unit_of_measurement: "°C"
  - platform: template
    id: shutdown_wait
    name: "종료 대기 시간 s"
    min_value: 30
    max_value: 180
    step: 15
    initial_value: 60
    restore_value: true
    optimistic: true
    unit_of_measurement: "s"

# ─── 전원 제어 ───────────────────────────────
switch:
  - platform: gpio
    id: relay
    pin: GPIO4
    inverted: ${relay_inverted}   # 모듈=true / 캐리어 PCB=false (substitutions 참고)
    restore_mode: RESTORE_DEFAULT_OFF  # 재부팅해도 마지막 전원 상태 유지 (기본=서버 ON)

  - platform: template
    id: server_power
    name: "서버 전원"
    icon: mdi:server
    lambda: 'return !id(relay).state;'
    turn_on_action:  [switch.turn_off: relay]
    turn_off_action: [switch.turn_on: relay]
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

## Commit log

2026-08-21 feat: BC250 front controller — ESPHome firmware, wiring guide, docs
2026-08-21 feat: minimal build tier (power control only) + realistic pricing
2026-08-21 feat: on-device settings menu — 2 nav buttons + OLED (fan mode/preset, brightness, thresholds), Korean menu font
2026-08-21 docs: usage manual section — button controls, settings menu, LED states, WiFi setup
2026-08-21 feat: ST7789V 240x320 SPI 디스플레이 에디션 추가
    - SSD1306 OLED(I2C) → ST7789V 240x320 SPI 컬러 디스플레이 교체
    - SPI 핀: MOSI=GPIO8, SCLK=GPIO9, CS=GPIO17, DC=GPIO15, RST=GPIO16
    - 백라이트 GPIO18 PWM 밝기 제어
    - 240x320 맞춤 UI: 대형 온도 표시, 상태 아이콘 바(FAN/TEMP/NET), 네트워크 화면
    - 기존 기능 유지: 릴레이 전원, 정상 종료, 팬 커브, DS18B20, 버튼 메뉴, HA, 웹
    - ESPHome 최신 문법(channel_colors), 컴파일 검증 통과(RAM 33.6%, Flash 59.5%)
2026-08-21 docs: ST7789V 배선 가이드 추가 + README 링크
    - docs/wiring-guide-st7789.html: ST7789V 240x320 SPI 전용 배선도 (핀맵·연결표·사용법)
    - SPI 핀 배열 반영: MOSI=8, SCLK=9, CS=17, DC=15, RST=16, BL=18
    - README(한/영) 빌드 단계 표에 ST7789V 에디션 추가, 배선 가이드 링크 연결
2026-08-21 docs: ST7789V 모듈 핀 라벨(VCC/GND/SDA/SCL/CS/DC/RST/BL) 매핑표 추가
    - 모듈에 인쇄된 라벨 기준 연결표를 배선 가이드 최상단(섹션 0)에 추가
    - SDA=MOSI, SCL=SCLK 안내 (저가 모듈 라벨 혼동 방지)
    - yaml 헤더 주석도 모듈 핀 라벨 기준으로 재정리
2026-08-21 fix: rgb_order로 되돌림 (구버전 ESPHome 25.x 호환)
    - channel_colors는 ESPHome 2026.x 전용 문법
    - rgb_order는 구버전(25.x)에서 필수 + 신버전에서도 경고만 뜨고 동작
    - 구버전 ESPHome에서 'channel_colors is invalid' 오류 해결
    [bc250-front-st7789.yaml]
2026-08-21 fix: select API를 버전 무관한 active_index()로 변경
    - current_option()은 ESPHome 2026.x 전용, .state는 2025.x 전용 (서로 호환 안 됨)
    - active_index()는 두 버전 모두 존재하는 공통 API → 버전 무관 호환
    - fan_mode: 0=자동/1=수동, fan_preset: 0=조용히/1=표준/2=성능 인덱스 비교
    - 2026.8.0 컴파일 검증 통과
    [bc250-front-st7789.yaml]
2026-08-31 feat: DS18B20 실주소·relay_inverted/log_uart 치환값, 방수 프로브 가이드, PCB 설계 파일 추가
    - bc250-front.yaml / minimal: relay_inverted·log_uart substitutions, DS18B20 2개 실제 주소
    - docs/wiring-guide.html: 6장 DS18B20 방수 프로브 연결 추가
    - README: PCB 3종(carrier/pcba/mini) 안내 표
    - hardware/: KiCad 생성 스크립트·보드 3종·JLCPCB 출력물 (개발은 중단, 기록용)
    Claude-Session: https://claude.ai/code/session_01LGV4TCo8fPNne5L7WyJzFB
    [Untitled.kicad_pcb, Untitled.kicad_sch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]
2026-08-31 feat(st7789): 메뉴 버튼 C(GPIO14)·강제종료 3초·전원 투입 시 LCD 안 켜짐 수정
    - 전원 투입(콜드 부팅) 때 RST를 눌러야 화면이 나오던 문제: on_boot에서 LCD RST(GPIO16)를
    1초간 LOW 유지 → HIGH → 200ms 뒤 드라이버 초기화, 그동안 백라이트 OFF (실물 확인 완료)
    - 전원 버튼 강제 전원 컷 5초 → 3초 (누르고 있으면 3초 되는 순간 실행)
    - 메뉴 버튼 C(GPIO14) 추가: 이전 항목/값 내리기. A/C 길게 누르면 0.2초마다 자동 반복
    - 가이드: 핀 배치도·연결표·조작표 갱신, 6장 보조 전원(J2000/J2001), 7장 DS18B20 프로브,
    8장 전원 투입 화면 문제(원인 2가지: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
    [bc250-front-st7789.yaml]
2026-08-31 chore: hardware/ 내장 git 저장소(.history)와 빈 Untitled KiCad 프로젝트 추적 제거
    .history 폴더가 gitlink(서브모듈 흉내)로 들어가 클론 시 빈 폴더가 되는 문제 수정.
    로컬 파일은 그대로 두고 인덱스에서만 제거, .gitignore에 추가.
    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
    [Untitled.kicad_pcb, Untitled.kicad_sch]
2026-08-31 feat(st7789): 안전·편의 개선 — 종료 실패 시 전원 유지, 과열 자동 종료, 백라이트 자동 어둡게, 보안
    - 정상 종료: OS 종료 요청(HTTP)이 2xx일 때만 대기 후 전원 컷, 실패하면 전원 유지 + LED 빨강.
    이미 꺼져 있으면 무시
    - 팬: GPU 온도를 못 읽으면(센서 미배선·고장) 60% 고정 — 팬 꺼진 채 서버 도는 일 방지
    - 과열 위험(경고 온도 + critical_margin 10°C가 60초 지속) → 자동 정상 종료, 실패하면 강제 컷
    - 과열 경고 온도 5°C 단위, 메뉴 숫자 소수점 제거, RSSI 첫 측정 전 '--' 표시
    - 메뉴 30초 무조작 자동 닫기, 전원 버튼 30ms 채터링 필터,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
2026-08-31 feat(st7789): 웹 내장·화면전환 버튼·컨트롤러 초기화·팬 연결 가이드
    펌웨어 (bc250-front-st7789.yaml):
    - web_server local: true — 대시보드 JS를 펌웨어에 내장, 인터넷 없는 AP 모드에서도 정상 표시
    - 화면 전환을 버튼으로: 메뉴 닫힘 상태에서 A=다음 화면, C=이전 화면 (7초 자동 순환 제거)
    - 컨트롤러 초기화: "설정값만 초기화"(WiFi 유지) / "공장 초기화"(factory_reset, WiFi·설정 전부)
    → 웹/HA 버튼 + 메뉴 "초기화" 서브메뉴(취소 포함). 한글 폰트 glyph 추가
    가이드 (docs/wiring-guide-st7789.html):
    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
2026-09-07 feat(st7789): 9/1 개선분 커밋 + 컨트롤러 칩 온도 센서 + 발열/플래시 출처 가이드(12장)
    - 2026-09-01 변경(미커밋 상태였음): LCD 자동 복구(lcd_heal/lcd_reset), 전원 투입 자동 부팅(ALWAYS_OFF +
    on_boot 700 소프트 재부팅 복원), 종료 실패 유지 표시·카운트다운·/health 재확인, PSU 이상 센서,
    PWR_OK 를 ADC 전압+히스테리시스로 판정, 팬은 바뀔 때만 전송·서버 꺼짐이면 OFF, AP 비밀번호,
    웹 digest 인증, http_request 3s, bc250-agent/ 종료 에이전트(가이드 11장)
    - 2026-09-07: "컨트롤러 칩 온도"(internal_temperature) 센서 추가. 가이드 12장: 기판 발열 판단표,
    어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
2026-09-07 fix(st7789): "서버 전원" 템플릿 스위치 부팅 복원 끔 — 콜드 부팅 자동 ON 이 무력화되던 버그
    템플릿 스위치 기본 restore_mode(RESTORE_DEFAULT_OFF)가 setup 에서 저장된 OFF 를 복원하며 turn_off_action 을
    실행해 릴레이를 켰다(서버 꺼짐). 릴레이 ALWAYS_OFF 와 on_boot(700) 정책보다 먼저 돌아 로그엔
    "Restored state OFF" 뒤에 "부팅 — 서버 ON" 이 찍히지만 실제론 꺼진 채였다. 9/1 검증 땐 저장값이 ON 이라
    드러나지 않았고, 9/7 재플래시(저장값 OFF) 때 드러남. 상태는 릴레이 lambda 에서 오므로 restore_mode: DISABLED.
    OTA 후 부팅 로그로 확인: "소프트 재부팅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
    [bc250-front-st7789.yaml]
2026-09-07 tweak(st7789): 서버 꺼짐 때 백라이트 10%→35% — 밝은 방에서 화면이 꺼진 것처럼 보이던 문제
    Claude-Session: https://claude.ai/code/session_01NmrpKWfof4UrYLztmoGpMQ
2026-09-07 fix(st7789): 소프트 재부팅(OTA·재시작) 뒤 화면이 안 켜지는 보고 — 부팅 3초 뒤 LCD 하드 복구 자동 실행
    RST(콜드 부팅)에선 켜지는데 OTA 재부팅 뒤엔 RST 를 눌러야 화면이 나온다는 보고. 소프트 재부팅은 GPIO·패널이
    이전 상태를 유지한 채 재초기화되므로, 리셋 원인이 POWERON 이 아니면 on_boot(-100)에서 script lcd_reset_boot
    (3초 뒤 lcd_reset = RST 펄스 + 전체 초기화 + 프레임 + 백라이트)를 실행한다. OTA 부팅 로그로 확인:
    "소프트 재부팅 — LCD 하드 복구 실행 (리셋 원인=3)" → "LCD 하드 복구 시작/완료" (442 ms). 가이드 8장에 설명 추가.
    Co-Au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
    [bc250-front-st7789.yaml]
2026-09-07 fix(st7789): 콜드 부팅 뒤 LCD 안 나옴 — 전원 투입 직후 1회 자동 재부팅 + LEDC 타이머 충돌 수정
    - 실측: USB/5V 투입 첫 부팅에서는 LCD 초기화·하드 복구·BOOT 버튼 모두 무효, RST 버튼 또는 소프트 재부팅
    (esp_restart)으로만 화면이 살아남. on_boot(900)에서 리셋 원인이 POWERON 이면 esp_restart() 1회.
    bc250_boot.h: RTC_NOINIT 플래그로 2차 부팅(SW)도 콜드 부팅으로 판정(bc250_is_cold_boot) → "전원 투입 = 서버 ON"
    정책 유지. safe_mode(AFTER_WIFI)보다 먼저라 부트루프 카운터에 안 잡힘. 플래그는 on_boot(-100)에서 소비.
    - 팬 PWM(25kHz, GPIO10)과 백라이트 PWM(5kH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
    [bc250-front-st7789.yaml]
2026-09-07 fix(st7789): 동작 중 화면 검게 꺼짐 — 2초마다 표시 유지 명령 재전송, SPI 10MHz, 콜드 부팅 뒤 꺼짐 플래그 정리
    - 실측(9/7): 재부팅 없이 화면이 검게 꺼지고 "LCD 화면 복구"로 돌아옴 = 프레임 앞 명령 바이트(CASET 0x2A/RAMWR 0x2C)가
    1비트 깨져 0x28 DISPOFF 로 들어간 것. interval 2s 에서 IDMOFF·NORON·INVON·DISPON 을 다시 보내 2초 안에 자가 복구.
    - lcd_data_rate 20→10MHz (9/1 에 정해 둔 다음 단계). 프레임 ~140→~200 ms.
    - on_boot(700) 콜드 부팅 분기에서 server_was_off=false — 콜드 부팅으로 서버가 켜진 뒤 소프트 재부팅에서
    "꺼짐 복원"이 도는 것 방지.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
    [bc250-front-st7789.yaml]
2026-09-07 fix(st7789): 전체 점검 반영 — 밝기/프리셋 저장 키 충돌, safe_mode 카운터, 꺼짐 플래그 미러, 팬 0%·LED·표시 자잘한 수정
    - "화면 밝기"(number) → "LCD 밝기": 한글만인 이름은 sanitize 뒤 "_____" 로 "팬 프리셋"(select)과 같은 해시가 되어
    플래시 저장 슬롯을 공유 → 프리셋을 바꾸면 다음 부팅에 밝기가 0 으로 복원돼 화면이 안 켜지는 버그. 메뉴 표기는 그대로.
    on_boot(350)에서 복원값이 10~100 밖이면 80 으로 교정.
    - safe_mode 명시(id sm, num_attempts 20) + 콜드 부팅 자동 재부팅 직전 clean_rtc()+sync(): 재부팅이 부팅 실패 2회로
    세어져 60초 안에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
    [bc250-front-st7789.yaml]
2026-09-07 tweak(st7789): WiFi 송신 출력 15dBm — USB 재연결 뒤 WiFi 접속 순간 브라운아웃 리셋 실측, 가이드 12장 전원 주의
    USB 재연결(콜드 부팅) 테스트에서 자동 재부팅 → 2차 부팅 → LCD 하드 복구까지는 정상이었으나 직후
    RTC_SW_SYS_RST → BROWNOUT_RST 가 이어짐(맥 USB 급전, WiFi 접속 시점). 신호가 -46dBm 로 충분해 출력을
    20→15dBm 으로 낮춰 송신 피크 전류를 줄임. 가이드 12장에 브라운아웃 증상·전원(짧은 케이블·PSU 5VSB) 안내.
    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
    [bc250-front-st7789.yaml]
2026-09-07 chore(st7789): esphome min_version 2026.8.0 — 옛 ESPHome(HA 애드온 2025.2.2)에서 빌드 시 명확한 오류로 중단
    9/7 아침처럼 옛 커밋본이 다른 secrets 로 올라가 API/OTA 가 안 맞는 사고를 빌드 단계에서 막는다.
    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
